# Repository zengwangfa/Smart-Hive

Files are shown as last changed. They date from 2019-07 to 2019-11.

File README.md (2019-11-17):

# 智能蜂箱系统

## 一、项目概述

| 硬件 | 主控制器(STM32) | 网关(MT7688) | 
| :--: | :--: | :--: |
|芯片型号| STM32F405RGT6 | MT7688AN |
|CPU| 32位 Cortex-M4(ARMv7) | MIPS24KEc |
|主频| 168MHz | 580MHz |
|RAM| 192KB | 256MB |
|外存| 1MB(FLASH) | 32MB(FLASH) |
|单元| FPU、DSP | Ethernet、WiFi |

> 针对户外大范围、大批量的蜂箱养殖，以及目前人工养蜂的人力成本过高等诸多问题，本设计提出了一套智能蜂箱终端控制方案，实现的内容为：用户可通过web端远程实时监控蜂箱状态（例如实时了解各个蜂箱的编号、重量、温度等）以及蜂箱防盗并且可以发送一系列指令进行远程操控（例如清洗蜂箱、喂食或气温下降给蜂箱加热、），极大便利了蜜蜂的养殖过程，降低了养蜂的人工成本。

## 二、通讯示意结构

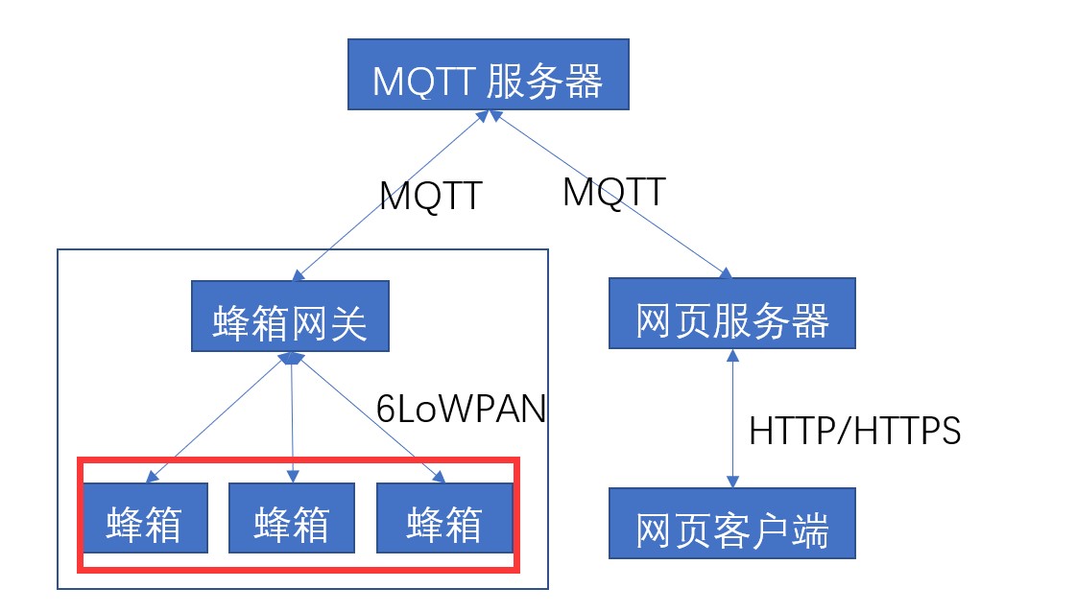
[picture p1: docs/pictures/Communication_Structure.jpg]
Communicatiom Structure


## 三、软件设计说明

- 编译环境：IAR 8.30
- 运行平台：STM32F405RGT6
- 所使用的的操作系统：RT-Thread

- 该软件使用的平台为RT-Thread 3.0物联网操作系统，采用6LoWPAN物联网协议**6LoWPAN** (IPv6 over Low-Power Wireless Personal Area Networks) 作为物联网的一种协议方式。使用这项技术，所有节在点网络层通过 **IPv6**联系起来。

### 3.1 整体结构图

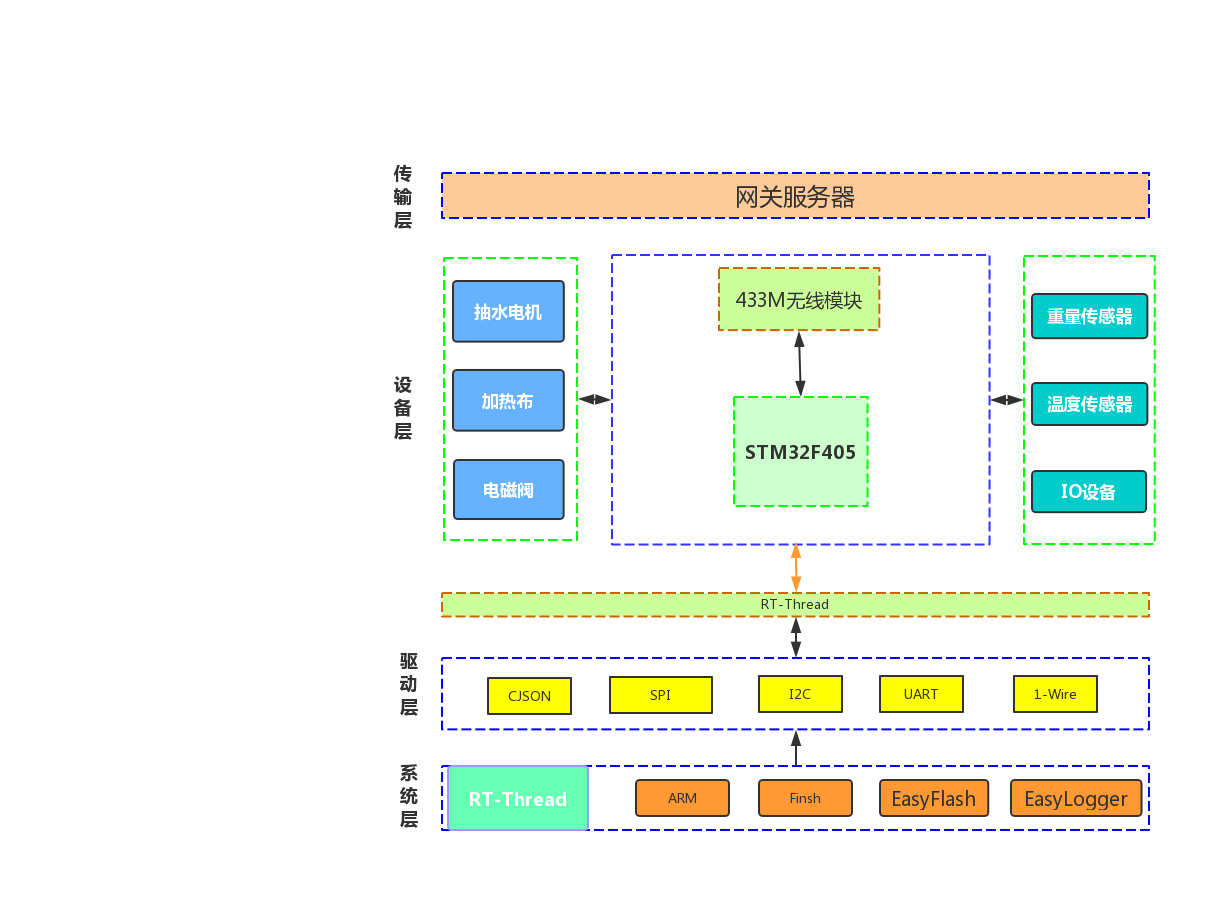
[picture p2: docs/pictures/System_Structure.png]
System Structure


- 主要功能为：采集外围设备数据（温度、重量、编号），将数据按照规定协议打包成**CJSO**数据格式，通过**433M**无线模块向**网关**上传数据，接收来自433M无线模块的控制数据包，进行外设的控制（加热控制、喂食控制、清洗控制）。
---
### 3.2 程序简易流程图
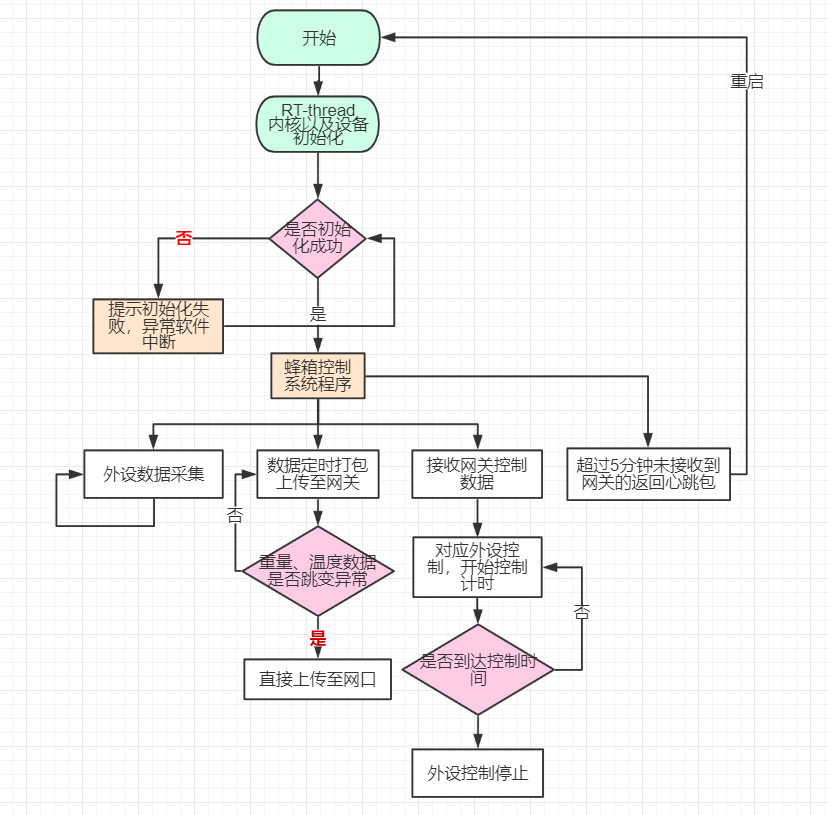
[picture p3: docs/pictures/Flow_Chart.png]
Flow Chart

---
### 3.3 实物样机测试
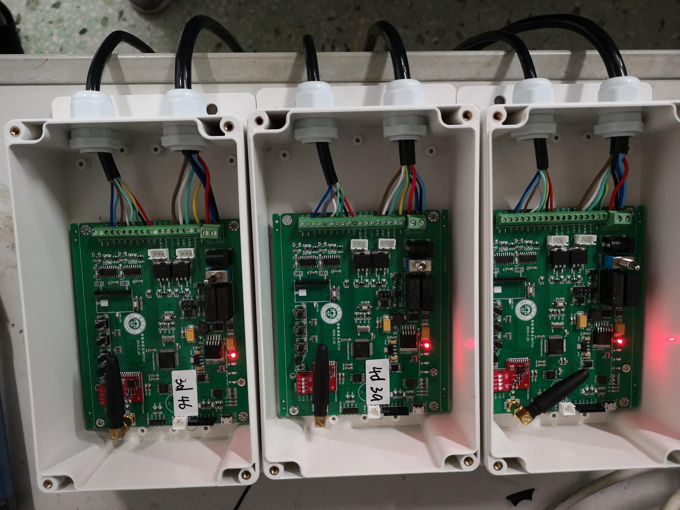
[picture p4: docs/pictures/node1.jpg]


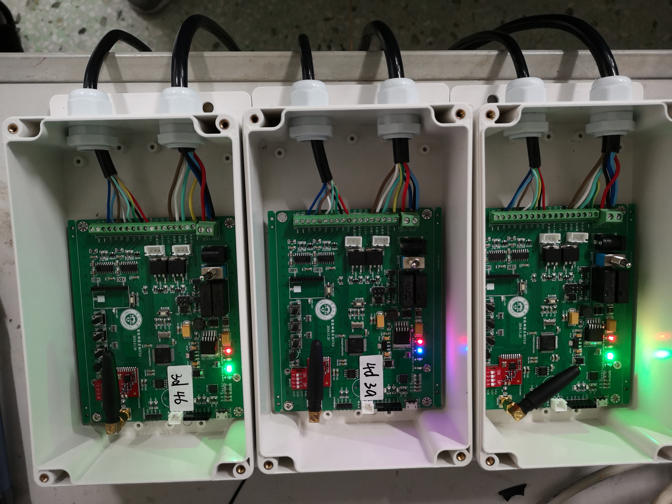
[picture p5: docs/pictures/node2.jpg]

---
### 3.4 Web端显示
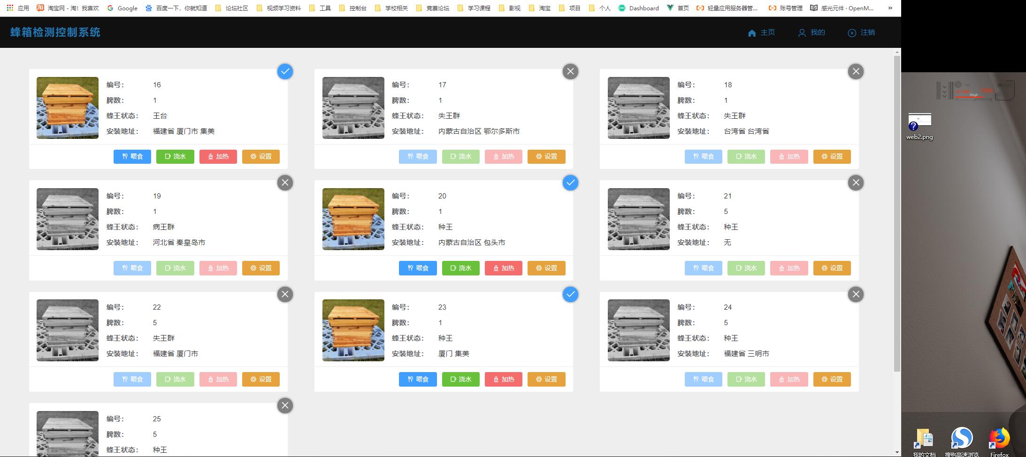
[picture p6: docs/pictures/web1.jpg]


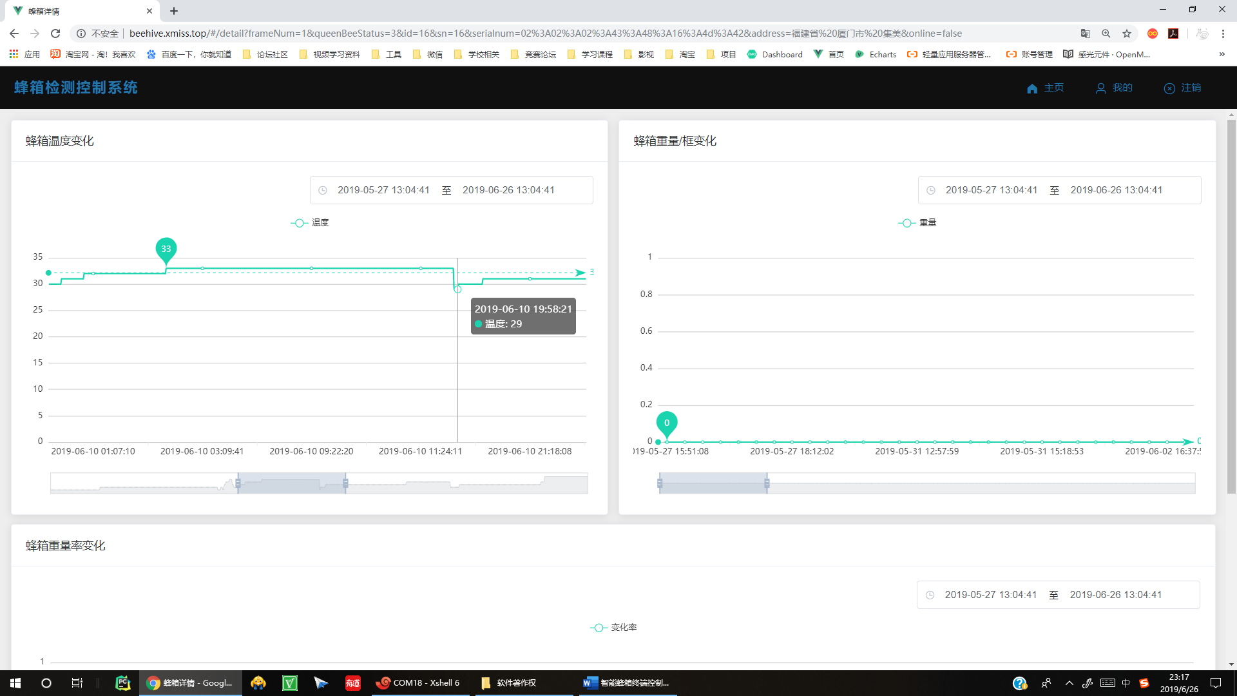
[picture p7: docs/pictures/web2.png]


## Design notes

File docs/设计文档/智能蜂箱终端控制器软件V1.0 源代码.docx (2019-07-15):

#define LOG_TAG "app_task"

#include "app_task.h"

#include <stdlib.h>

#include <stdio.h>

#include <board.h>

#include <elog.h>

#include <elog_flash.h>

#include <easyflash.h>

#include <delay_conf.h>

#include <cpuusage.h>

#include <utils.h>

#include <shell.h>

#include <finsh.h>

#include <cm_backtrace.h>

#include <dfs_elm.h>

#include <dfs_fs.h>

#include <spi_flash.h>

#include <spi_flash_sfud.h>

#include <partition.h>

#define SOFTWARE_VERSION "1.07.15"

static uint8_t cpu_usage_major, cpu_usage_minor;

static rt_uint32_t total_mem, used_mem, max_used_mem;

#define thread_sys_monitor_prio 30

ALIGN(RT_ALIGN_SIZE)

static rt_uint8_t thread_sys_monitor_stack[512];

struct rt_thread thread_sys_monitor;

rt_spi_flash_device_t nor_flash;

static void rtt_user_assert_hook(const char* ex, const char* func, rt_size_t line);

static void elog_user_assert_hook(const char* ex, const char* func, size_t line);

static rt_err_t exception_hook(void *context);

/**

* @param parameter parameter

*/

void thread_entry_sys_monitor(void* parameter)

{

while (1)

{

rt_memory_info(&total_mem, &used_mem, &max_used_mem);

// rt_kprintf("Total_Mem:%ld Used_Mem:%ld Max_Used_Mem:%ld\n",total_mem,used_mem,max_used_mem);

IWDG_Feed(); //

}

}

/**

* @param parameter parameter

*/

void sys_init_thread(void* parameter){

set_system_status(SYSTEM_STATUS_INIT);

#ifdef RT_USING_COMPONENTS_INIT

rt_components_init();

#endif

#if defined(RT_USING_FINSH) && !defined(RT_USING_POSIX)

finsh_set_device(RT_CONSOLE_DEVICE_NAME);

#endif

if ((nor_flash = rt_sfud_flash_probe("nor_flash", "spi20")) == NULL) {

set_system_status(SYSTEM_STATUS_FAULT);

return;

}

extern int rt_partition_init(const char* flash_device, const struct rt_partition* parts, rt_size_t num);

static const struct rt_partition partition[] = RT_PARTITION_DEFAULT_TABLE;

rt_partition_init("nor_flash", partition, sizeof(partition) / sizeof(struct rt_partition));

easyflash_init();

elog_init();

elog_set_fmt(ELOG_LVL_ASSERT, ELOG_FMT_ALL & ~ELOG_FMT_P_INFO);

elog_set_fmt(ELOG_LVL_ERROR, ELOG_FMT_ALL & ~ELOG_FMT_P_INFO);

elog_set_fmt(ELOG_LVL_WARN, ELOG_FMT_ALL & ~ELOG_FMT_P_INFO);

elog_set_fmt(ELOG_LVL_INFO, ELOG_FMT_LVL | ELOG_FMT_TAG | ELOG_FMT_TIME);

elog_set_fmt(ELOG_LVL_DEBUG, ELOG_FMT_ALL & ~(ELOG_FMT_FUNC | ELOG_FMT_P_INFO));

elog_set_fmt(ELOG_LVL_VERBOSE, ELOG_FMT_ALL & ~(ELOG_FMT_FUNC | ELOG_FMT_P_INFO));

#ifdef DEBUG

elog_set_filter_lvl(ELOG_LVL_VERBOSE);

#elif RELEASE

elog_set_filter_lvl(ELOG_LVL_INFO);

#endif

#ifdef ELOG_COLOR_ENABLE

elog_set_text_color_enabled(true);

#endif

elog_flash_init();

elog_start();

extern void flash_read_normalized(void);

flash_read_normalized();

elog_assert_set_hook(elog_user_assert_hook);

rt_hw_exception_install(exception_hook);

rt_assert_set_hook(rtt_user_assert_hook);

cm_backtrace_init("ART-6LoWPAN", HARDWARE_VERSION, SOFTWARE_VERSION);

if (dfs_mount("fatfs", "/", "elm", 0, 0) == 0) {

log_i("File System initialized!");

} else {

log_e("File System initialization failed!");

}

extern void contiki_init(void);

contiki_init();

set_system_status(SYSTEM_STATUS_RUN);

log_i("ART-6LoWPAN initialize success. Firmware version is %s", SOFTWARE_VERSION);

}

static void rtt_user_assert_hook(const char* ex, const char* func, rt_size_t line) {

rt_enter_critical();

#ifdef ELOG_ASYNC_OUTPUT_ENABLE

elog_async_enabled(false);

#endif

elog_output_lock_enabled(false);

elog_flash_lock_enabled(false);

elog_a("rtt", "(%s) has assert failed at %s:%ld.", ex, func, line);

cm_backtrace_assert(cmb_get_sp());

elog_flash_flush();

while(1);

}

static void elog_user_assert_hook(const char* ex, const char* func, size_t line) {

rt_enter_critical();

#ifdef ELOG_ASYNC_OUTPUT_ENABLE

elog_async_enabled(false);

#endif

elog_output_lock_enabled(false);

elog_flash_lock_enabled(false);

elog_a("elog", "(%s) has assert failed at %s:%ld.\n", ex, func, line);

cm_backtrace_assert(cmb_get_sp());

elog_flash_flush();

while(1);

}

static rt_err_t exception_hook(void *context) {

extern long list_thread(void);

uint8_t _continue = 1;

rt_enter_critical();

#ifdef ELOG_ASYNC_OUTPUT_ENABLE

elog_async_enabled(false);

#endif

elog_output_lock_enabled(false);

elog_flash_lock_enabled(false);

#ifdef RT_USING_FINSH

list_thread();

#endif

cm_backtrace_fault(*((uint32_t *)(cmb_get_sp() + sizeof(uint32_t) * 8)), cmb_get_sp() + sizeof(uint32_t) * 9);

elog_flash_flush();

while (_continue == 1);

return RT_EOK;

}

*/

void rt_hw_console_output(const char *str) {

extern void output_log_to_console_or_flash(bool console, bool flash, const char *log, size_t size);

output_log_to_console_or_flash(true, true, str, rt_strlen(str));

}

int rt_application_init(void)

{

rt_thread_t thread = NULL;

rt_thread_init(&thread_sys_monitor,

"sys_monitor",

thread_entry_sys_monitor,

RT_NULL,

thread_sys_monitor_stack,

sizeof(thread_sys_monitor_stack),

thread_sys_monitor_prio, 5);

rt_thread_startup(&thread_sys_monitor);

thread = rt_thread_create("sys init", sys_init_thread, NULL, 2048, 10, 10);

if (thread != NULL) {

rt_thread_startup(thread);

}

return 0;

}

/**

* This function will startup RT-Thread RTOS.

*/

void rtthread_startup(void)

{

/* init board */

rt_hw_board_init();

/* show version */

rt_show_version();

/* init tick */

rt_system_tick_init();

/* init kernel object */

rt_system_object_init();

/* init timer system */

rt_system_timer_init();

#ifdef RT_USING_HEAP

/* init memory system */

rt_system_heap_init((void*)STM32_SRAM_BEGIN, (void*)STM32_SRAM_END);

#endif

/* init scheduler system */

rt_system_scheduler_init();

/* initialize timer */

rt_system_timer_init();

/* init timer thread */

rt_system_timer_thread_init();

/* Add CPU usage to system */

cpu_usage_init();

/* init application */

rt_application_init();

/* init idle thread */

rt_thread_idle_init();

/* start scheduler */

rt_system_scheduler_start();

/* never reach here */

return;

}

void sys_reboot_entry(void* parameter)

{

static rt_uint32_t sys_cnt = 0;

while(1)

{

rt_thread_delay(RT_TICK_PER_SECOND); //1s

sys_cnt++;

if(sys_cnt >= 60*60*4) //6 1-5 2-10 3-20 4-30 5-1h

{

sys_cnt = 0;

NVIC_SystemReset();

}

}

}

int sys_reboot_thread_init(void)

{

rt_thread_t reboot_tid;

/* */

reboot_tid = rt_thread_create("reboot"

sys_reboot_entry,

RT_NULL,

1024,

30,

10);

if (reboot_tid != RT_NULL){

rt_thread_startup(reboot_tid);

}

return 0;

}

INIT_APP_EXPORT(sys_reboot_thread_init);

int main(void) {

/* disable interrupt first */

rt_hw_interrupt_disable();

/* startup RT-Thread RTOS */

rtthread_startup();

return 0;

}/*

* File : board.h

* This file is part of RT-Thread RTOS

* COPYRIGHT (C) 2017, RT-Thread Development Team

*

* The license and distribution terms for this file may be

* found in the file LICENSE in this distribution or at

* http://www.rt-thread.org/license/LICENSE

*

* Change Logs:

* Date Author Notes

* 2017-12-19 xidongxu first version

*/

#include "board.h"

#include <rtthread.h>

*/

static uint16_t get_adc(u8 ch) {

ADC_RegularChannelConfig(ADC1, ch, 1, ADC_SampleTime_112Cycles );

ADC_SoftwareStartConv(ADC1);

while(!ADC_GetFlagStatus(ADC1, ADC_FLAG_EOC ));

return ADC_GetConversionValue(ADC1);

}

/**

*

*/

uint32_t cpu_temp_get(void) {

uint32_t adc[10] = { 0 }, adc_max = 0, adc_min = 0;

uint32_t adc_value = 0, adc_sum = 0;

double temperature = 0.0;

for (uint8_t t = 0; t < 10; t++) {

adc[t] = get_adc(ADC_Channel_16);

adc_sum = adc_sum + adc[t];

rt_thread_delay(rt_tick_from_millisecond(5));

}

adc_max = adc[0];

adc_min = adc[0];

for (uint8_t t = 1; t < 10; t++) {

if (adc_max < adc[t]) {

adc_max = adc[t];

}

if (adc_min > adc[t]) {

adc_min = adc[t];

}

}

adc_value = ((adc_sum - adc_max - adc_min) / 8);

temperature = (float) adc_value * (3.3 / 4096);

temperature = (temperature - 0.76) / 0.0025 + 25;

return (uint32_t)(temperature);

}

*/

int stm32_cpu_temperature_init(void) {

ADC_CommonInitTypeDef ADC_CommonInitStructure;

ADC_InitTypeDef ADC_InitStructure;

RCC_APB2PeriphClockCmd(RCC_APB2Periph_ADC1, ENABLE);

RCC_APB2PeriphResetCmd(RCC_APB2Periph_ADC1, ENABLE);

RCC_APB2PeriphResetCmd(RCC_APB2Periph_ADC1, DISABLE);

ADC_TempSensorVrefintCmd(ENABLE);

ADC_CommonInitStructure.ADC_Mode = ADC_Mode_Independent;

ADC_CommonInitStructure.ADC_TwoSamplingDelay = ADC_TwoSamplingDelay_20Cycles;

ADC_CommonInitStructure.ADC_DMAAccessMode = ADC_DMAAccessMode_Disabled;

ADC_CommonInitStructure.ADC_Prescaler = ADC_Prescaler_Div4;

ADC_CommonInit(&ADC_CommonInitStructure);

ADC_InitStructure.ADC_Resolution = ADC_Resolution_12b;

ADC_InitStructure.ADC_ScanConvMode = DISABLE;

ADC_InitStructure.ADC_ContinuousConvMode = DISABLE;

ADC_InitStructure.ADC_ExternalTrigConvEdge = ADC_ExternalTrigConvEdge_None;

ADC_InitStructure.ADC_ExternalTrigConv = ADC_ExternalTrigConv_T1_CC1;

ADC_InitStructure.ADC_DataAlign = ADC_DataAlign_Right;

ADC_InitStructure.ADC_NbrOfConversion = 1;

ADC_Init(ADC1, &ADC_InitStructure);

ADC_RegularChannelConfig(ADC1, ADC_Channel_16, 1, ADC_SampleTime_112Cycles);

ADC_Cmd(ADC1, ENABLE);

return 0;

}

INIT_BOARD_EXPORT(stm32_cpu_temperature_init);

/******************************************************************************

* Copyright 2018-2023 zhuangwei@nblink-tech.com

* FileName: drv_ds18b20.c

* Desc:

*

*

* Author: zhuangwei

* Date: 2018-12-15

* Notes:

*

* -----------------------------------------------------------------

* Histroy: v1.0 2018-12-15, zhuangwei create this file

*

******************************************************************************/

/*------------------------------- Includes ----------------------------------*/

#include <rtdevice.h>

#include "utils.h"

#include "drv_ds18b20.h"

/*------------------- Global Definitions and Declarations -------------------*/

/*---------------------- Constant / Macro Definitions -----------------------*/

#define DS18B20_PIN 54

/*----------------------- Type Declarations ---------------------------------*/

/*----------------------- Variable Declarations -----------------------------*/

static int temp_value = 0;

/*----------------------- Function Prototype --------------------------------*/

/*----------------------- Function Implement --------------------------------*/

/******************************************************************************

* Name: ds18b20_rst

*

* Desc: DS18B20

* Param:

* Return:

* Global:

* Note:

* Author: zhuangwei

* -------------------------------------

* Log: 2018/12/15, Create this function by zhuangwei

******************************************************************************/

static rt_uint8_t ds18b20_rst(void)

{

rt_pin_mode(DS18B20_PIN, PIN_MODE_OUTPUT);

rt_pin_write(DS18B20_PIN, PIN_LOW);

delay_us(750);

rt_pin_write(DS18B20_PIN, PIN_HIGH);

delay_us(20);

rt_pin_mode(DS18B20_PIN, PIN_MODE_INPUT);

delay_us(100);

return rt_pin_read(DS18B20_PIN);

}

/******************************************************************************

* Name: ds18b20_read_byte

*

* Desc:

* Param:

* Return:

* Global:

* Note:

* Author: zhuangwei

* -------------------------------------

* Log: 2018/12/15, Create this function by zhuangwei

******************************************************************************/

static rt_uint8_t ds18b20_read_byte(void) // read one byte

{

rt_uint8_t i;

rt_uint8_t data = 0;

for (i=0; i<8; i++)

{

rt_pin_mode(DS18B20_PIN, PIN_MODE_OUTPUT);

rt_pin_write(DS18B20_PIN, PIN_LOW);

delay_us(2);

rt_pin_write(DS18B20_PIN, PIN_HIGH);

rt_pin_mode(DS18B20_PIN, PIN_MODE_INPUT);

delay_us(12);

data >>= 1;

if(rt_pin_read(DS18B20_PIN))

{

data |= 0x80;

}

delay_us(50);

rt_pin_mode(DS18B20_PIN, PIN_MODE_OUTPUT);

rt_pin_write(DS18B20_PIN, PIN_HIGH);

}

return data;

}

/******************************************************************************

* Name: ds18b20_write_byte

*

* Desc:

* Param:

* Return:

* Global:

* Note:

* Author: zhuangwei

* -------------------------------------

* Log: 2018/12/15, Create this function by zhuangwei

******************************************************************************/

static void ds18b20_write_byte(rt_uint8_t data)

{

rt_uint8_t i,tmp;

rt_pin_mode(DS18B20_PIN, PIN_MODE_OUTPUT);

for (i=1; i<=8; i++)

{

tmp = data&0x01;

data = data>>1;

if(tmp)

{

rt_pin_write(DS18B20_PIN, PIN_LOW);

delay_us(5);

rt_pin_write(DS18B20_PIN, PIN_HIGH);

delay_us(60);

}

else

{

rt_pin_write(DS18B20_PIN, PIN_LOW);

delay_us(60);

rt_pin_write(DS18B20_PIN, PIN_HIGH);

delay_us(5);

}

}

}

/******************************************************************************

* Name: ds18b20_get_temp

*

* Desc:

* Param:

* Return:

* Global:

* Note:

* Author: zhuangwei

* -------------------------------------

* Log: 2018/12/15, Create this function by zhuangwei

******************************************************************************/

static int ds18b20_get_value(void)

{

rt_uint8_t TL,TH;

rt_uint16_t temp;

float ret;

if(ds18b20_rst()) return 0;

delay_us(100);

ds18b20_write_byte(0xCC);//skip rom

ds18b20_write_byte(0x44);//convert

//rt_thread_delay(1);

if(ds18b20_rst()) return 0;

delay_us(100);

ds18b20_write_byte(0xCC);// skip rom

ds18b20_write_byte(0xBE);

delay_us(10);

TL = ds18b20_read_byte();

TH = ds18b20_read_byte();

temp = (TH<<8)|TL;

if(temp&0xf000)

{

ret = (~temp+1)*0.0625;

}

else

{

ret = temp*0.0625;

}

return (int)ret;

}

int ds18b20_get_temp(void)

{

int ret;

rt_enter_critical();

ret = temp_value;

rt_exit_critical();

return ret;

}

static void ds18b20(void)

{

rt_uint8_t count;

rt_uint16_t temp;

for(count=1; count<=3; count++)

{

temp =ds18b20_get_temp();

rt_kprintf("temperature : %d\r\n", temp);

rt_thread_mdelay(500);

}

}

MSH_CMD_EXPORT(ds18b20, ds18b20 test);

void first_get_temperature(void)

{

char j = 0;

rt_int32_t value[5] = {0};

/* 500ms */

rt_thread_delay(RT_TICK_PER_SECOND/2);

rt_enter_critical();

for(j=0; j<5; j++)

{

rt_thread_delay(10);

value[j] = ds18b20_get_value();

}

temp_value = Bubble(value, 5);

rt_exit_critical();

}

rt_int32_t value[5] = {0};

void ds18b20_thread_entry(void* p)

{

char i = 0;

char ON_OFF = 0; //

rt_int32_t last_temp = 0;

while(1)

{

if(ON_OFF == 0){

first_get_temperature();

ON_OFF = 1;

}

else{

rt_thread_delay(RT_TICK_PER_SECOND/5);// 0.2s 10s

value[i++] = ds18b20_get_value();

if(i >= 5){// 5

temp_value = Bubble(value, 5);

i = 0;

if(temp_value > -10 && temp_value < 55){ //

last_temp = temp_value; //

}

else if(abs(temp_value-last_temp)>5 && last_temp != 0 )// 5 0

{

temp_value = last_temp;//

}

rt_kprintf("temp:$%d\r\n",temp_value);

//rt_kprintf("last_temp:$%d\r\n",last_temp);

}

}

}

}

//void ds18b20_thread_entry(void* p)

//{

// int i = 0;

// int value[5] = {0};

// static rt_int32_t last_temp = 0;

//

// while(1)

// {

// /* 500ms */

// rt_thread_delay(RT_TICK_PER_SECOND/2);

// rt_enter_critical();

// for(i=0; i<5; i++)

// {

// rt_thread_delay(1);

// value[i] = ds18b20_get_value();

// }

//

// temp_value = Bubble((rt_int32_t *)value, 5);

// if(temp_value > -20 && temp_value < 70){ //

// last_temp = temp_value; //

// }

// else {

// temp_value = last_temp;//

// }

// rt_exit_critical();

// }

//}

static int ds18b20_init(void)

{

rt_thread_t thread = RT_NULL;

/* Create background ticks thread */

thread = rt_thread_create("ds18b20", ds18b20_thread_entry, RT_NULL, 1024, 30, 10);

if(thread == RT_NULL)

{

return RT_ERROR;

}

rt_thread_startup(thread);

return 0;

}

INIT_DEVICE_EXPORT(ds18b20_init);

/*---------------------------------------------------------------------------*/

/******************************************************************************

* Copyright 2018-2023 zhuangwei@nblink-tech.com

* FileName: drv_hx711.c

* Desc:

*

*

* Author: zhuangwei

* Date: 2018-12-19

* Notes:

*

* -----------------------------------------------------------------

* Histroy: v1.0 2018-12-19, zhuangwei create this file

*

******************************************************************************/

/*------------------------------- Includes ----------------------------------*/

#define LOG_TAG "drv_hx711"

#include <rtdevice.h>

#include "utils.h"

#include "drv_hx711.h"

#include <elog.h>

#include "multi_button.h"

#include "easyflash.h"

#include <stdio.h>

#include <stdlib.h>

/*------------------- Global Definitions and Declarations -------------------*/

/*---------------------- Constant / Macro Definitions -----------------------*/

#define FLASH_INIT_ADDRESS (4096) //

#define HX711_DT1_PIN 10

#define HX711_SCK1_PIN 11

#define HX711_DT2_PIN 14

#define HX711_SCK2_PIN 15

#define HX711_LED_PIN 55

#define HX711_KEY_PIN 28

#define HX711_DT(pin) rt_pin_read(pin)

#define HX711_SCK_HIGH(pin) rt_pin_write(pin, PIN_HIGH)

#define HX711_SCK_LOW(pin) rt_pin_write(pin, PIN_LOW)

#define HX711_LED_ON rt_pin_write(HX711_LED_PIN, PIN_HIGH)

#define HX711_LED_OFF rt_pin_write(HX711_LED_PIN, PIN_LOW)

/*----------------------- Type Declarations ---------------------------------*/

/*----------------------- Variable Declarations -----------------------------*/

static struct button btn;

uint32_t var_min[2]={999999999,999999999}; // -2147483648 +2141483647

float weight = 0;

float side_weight[2];

double Normalized[2]={0}; // float double

rt_int32_t Reverse_Normalized[2] = {0}; // flash

static int key_status = 0;

/*----------------------- Function Prototype --------------------------------*/

/*----------------------- Function Implement --------------------------------*/

int flash_read_normalized(void)

{

char string[100];

ef_port_read(FLASH_INIT_ADDRESS+0,(rt_int32_t *)&Reverse_Normalized[0],4);

ef_port_read(FLASH_INIT_ADDRESS+4,(rt_int32_t *)&Reverse_Normalized[1],4);

ef_port_read(FLASH_INIT_ADDRESS+8 ,&var_min[0],4);

ef_port_read(FLASH_INIT_ADDRESS+12,&var_min[1],4);

Normalized[0] = (double)1 / Reverse_Normalized[0] ;

Normalized[1] = (double)1 / Reverse_Normalized[1] ;

// string

sprintf(string,"Normalized*100: %f , %f ",Normalized[0]*100,Normalized[1]*100);

log_i(string);

sprintf(string,"var_min:%ld , %ld ",var_min[0],var_min[1]);

log_i(string);

return 0;

}

void flash_writer_normalized(void)

{

ef_port_erase(FLASH_INIT_ADDRESS,4); // 4096 Byte

ef_port_write(FLASH_INIT_ADDRESS+0,(uint32_t *)&Reverse_Normalized[0],4);// FLASH_INIT_ADDRESS+0

ef_port_write(FLASH_INIT_ADDRESS+4,(uint32_t *)&Reverse_Normalized[1],4);

ef_port_write(FLASH_INIT_ADDRESS+8 ,&var_min[0],4);

ef_port_write(FLASH_INIT_ADDRESS+12,&var_min[1],4);

}

rt_uint32_t hx711_read(int pin_dat, int pin_sck)

{

unsigned char i;

unsigned int value;

HX711_SCK_LOW(pin_sck);// AD

value=0;

while(HX711_DT(pin_dat));//AD ,

for(i=0; i<24; i++)

{

HX711_SCK_HIGH(pin_sck);//SCK ( )

value = value<<1;// Count ,

HX711_SCK_LOW(pin_sck);//SCK

if(HX711_DT(pin_dat)) value++;

}

HX711_SCK_HIGH(pin_sck);

value = value^0x800000;// 25 ,

HX711_SCK_LOW(pin_sck);

return value;

}

static void first_hx711_get_ad(rt_int32_t *ad)//

{

rt_int32_t var0[5];

rt_int32_t var1[5];

rt_uint8_t i = 0;

if(!ad) return;

for(i=0; i<5; i++)

{

rt_thread_delay(RT_TICK_PER_SECOND/10);// 100ms

var0[i] = hx711_read(HX711_DT1_PIN, HX711_SCK1_PIN);

var1[i] = hx711_read(HX711_DT2_PIN, HX711_SCK2_PIN);

}

ad[0] = Bubble(var0, 5);

ad[1] = Bubble(var1, 5);

}

static void hx711_get_ad(rt_int32_t *ad)

{

rt_int32_t var0[5];

rt_int32_t var1[5];

uint8_t i = 0;

if(!ad) return;

for(i=0; i<5; i++)

{

var0[i] = hx711_read(HX711_DT1_PIN, HX711_SCK1_PIN);

var1[i] = hx711_read(HX711_DT2_PIN, HX711_SCK2_PIN);

//rt_kprintf("var: %d , %d\n",var0[i],var1[i]);

}

ad[0] = Bubble(var0, 5);

ad[1] = Bubble(var1, 5);

//rt_kprintf("ad: %d , %d\n",ad[0],ad[1]);

}

void hx711_get_min(void)

{

rt_int32_t temp_res[2]={0};

uint8_t j = 5;

while(j--)

{

hx711_get_ad(temp_res);

rt_kprintf("temp_res: %ld , %ld \n",temp_res[0],temp_res[1]);

if(var_min[0] >= temp_res[0] || var_min[0] < 800000 ) {// var_min 800000 ,var_min

var_min[0] = temp_res[0];

}

if(var_min[1] >= temp_res[1] || var_min[1] < 800000 ) {

var_min[1] = temp_res[1];

}

rt_kprintf("var_min: %ld , %ld\n",var_min[0],var_min[1]);

}

log_i("var_min: %ld, %ld ",var_min[0],var_min[1]);

}

void hx711_normalized(void)

{

rt_int32_t temp[2]={0};

hx711_get_ad(temp);

Reverse_Normalized[0]= abs(temp[0]-var_min[0]);

Reverse_Normalized[1] = abs(temp[1]-var_min[1]);

Normalized[0] =(double) 1/(temp[0]-var_min[0]);

Normalized[1] =(double) 1/(temp[1]-var_min[1]);

flash_writer_normalized();//

log_i("FLASH Write Reverse_Normalized: %d, %d ",Reverse_Normalized[0],Reverse_Normalized[1]);

}

float hx711_weight_get(void)

{

float ret;

rt_enter_critical();

ret = weight;

rt_exit_critical();

return ret;

}

float hx711_weight_update(void)

{

rt_int32_t AD_Value[2] = {0};

static uint8_t count = 0;

static float last_weight = 0;

static char ON_OFF = 0;

while(1)

{

if(0 == ON_OFF){

first_hx711_get_ad(AD_Value);

ON_OFF = 1;

}

else{

hx711_get_ad(AD_Value);

}

side_weight[0] = (float)abs(AD_Value[0]-var_min[0])/abs(Reverse_Normalized[0]);

side_weight[1] = (float)abs(AD_Value[1]-var_min[1])/abs(Reverse_Normalized[1]);

//rt_kprintf("--- %ld --- %ld ---\n",abs(AD_Value[0]-var_min[0]),abs(AD_Value[1]-var_min[1]));

if ( ((side_weight[0] > 50 || side_weight[1] > 50) || (side_weight[0] < 0 || side_weight[1] < 0)) && count <= 5) // 50kg

{

count ++;

//rt_kprintf("count = %d \n",count);

continue;// 6

}

else if(count > 5){ //

count = 0;

rt_kprintf("last_weight = %d \n",last_weight);

return last_weight;//

}

last_weight = (side_weight[0]+side_weight[1])/2;

return (side_weight[0]+side_weight[1])/2; //

}

}

void hx711_key_callback(void *btn)

{

uint32_t btn_event_val;

btn_event_val = get_button_event((struct button *)btn);

if(btn_event_val == SINGLE_CLICK)

{

switch(key_status)

{

case 0://

hx711_get_min();

HX711_LED_ON;

key_status = 1;

log_i("please put 1KG");

break;

case 1://

hx711_normalized();//

HX711_LED_OFF;

key_status = 0;

log_i("hx711 normalized");

break;

default:

break;

}

}

}

static uint8_t hx711_key_read(void)

{

return rt_pin_read(HX711_KEY_PIN);

}

void hx711_key_thread_entry(void* p)

{

int cnt = 200*55;

while(1)

{

/* 5ms */

rt_thread_delay(RT_TICK_PER_SECOND/200);

button_ticks();

cnt++;

if(cnt == 200*60)//60s

{

rt_enter_critical();

weight = hx711_weight_update();

rt_exit_critical();

cnt = 0;

}

}

}

static int hx711_init(void)

{

rt_pin_mode(HX711_DT1_PIN, PIN_MODE_INPUT_PULLUP);

rt_pin_mode(HX711_SCK1_PIN, PIN_MODE_OUTPUT);

rt_pin_write(HX711_SCK1_PIN, PIN_HIGH);

rt_pin_mode(HX711_DT2_PIN, PIN_MODE_INPUT_PULLUP);

rt_pin_mode(HX711_SCK2_PIN, PIN_MODE_OUTPUT);

rt_pin_write(HX711_SCK2_PIN, PIN_HIGH);

rt_pin_mode(HX711_LED_PIN, PIN_MODE_OUTPUT);

HX711_LED_OFF;

rt_pin_mode(HX711_KEY_PIN, PIN_MODE_INPUT);

button_init(&btn, hx711_key_read, PIN_LOW);

button_attach(&btn, SINGLE_CLICK, hx711_key_callback);

button_start (&btn);

rt_thread_t thread = RT_NULL;

/* Create background ticks thread */

thread = rt_thread_create("hx711", hx711_key_thread_entry, RT_NULL, 1024, 30, 10);

if(thread == RT_NULL)

{

return RT_ERROR;

}

rt_thread_startup(thread);

return 0;

}

INIT_DEVICE_EXPORT(hx711_init);

/*---------------------------------------------------------------------------*/

/* Get weight */

void get_weight_hx711(void)

{

// string

char str[100];

float temp_weight = 0;

temp_weight = hx711_weight_update();

sprintf(str,"Weight:%f \n",temp_weight);

rt_kprintf(str);

sprintf(str,"weight1:%f weight2:%f\n",side_weight[0],side_weight[1]);

rt_kprintf(str);

}

MSH_CMD_EXPORT(get_weight_hx711,get_weight_hx711[a]);

/******************************************************************************

* Copyright 2018-2023 zhuangwei@nblink-tech.com

* FileName: drv_relay.c

* Desc:

*

*

* Author: zhuangwei

* Date: 2018-12-15

* Notes:

*

* -----------------------------------------------------------------

* Histroy: v1.0 2018-12-15, zhuangwei create this file

*

******************************************************************************/

/*------------------------------- Includes ----------------------------------*/

#define LOG_TAG "drv_relay"

#include <rtdevice.h>

#include "drv_relay.h"

#include <elog.h>

/*------------------- Global Definitions and Declarations -------------------*/

typedef struct

{

char *name;

rt_base_t pin;

rt_timer_t timer;

int status;

}relay_t;

/*---------------------- Constant / Macro Definitions -----------------------*/

static relay_t relay_table[] = {

{"water", 62, RT_NULL, 0},

{"feed", 61, RT_NULL, 0},

{"heat1", 4, RT_NULL, 0},

{"heat2", 9, RT_NULL, 0}

};

/*----------------------- Type Declarations ---------------------------------*/

/*----------------------- Variable Declarations -----------------------------*/

/*----------------------- Function Prototype --------------------------------*/

/*----------------------- Function Implement --------------------------------*/

static void timeout_handler(void* parameter)

{

relay_t *relay_ptr = (relay_t*)parameter;

relay_ptr->status = relay_ptr->status?0:1;

rt_pin_write(relay_ptr->pin, relay_ptr->status);

relay_ptr->timer = RT_NULL;

}

int relay_control(relay_dev_t dev, int expect_status, int hold_s)

{

if(dev >= RELAY_MAX) return -1;

if(relay_table[dev].status == expect_status) return 0;

if(relay_table[dev].timer)

{

if(relay_table[dev].status == expect_status)

return 0;

else

return -1;

}

else

{

rt_pin_write(relay_table[dev].pin, expect_status);

relay_table[dev].status = expect_status;

if(hold_s > 0)

{

relay_table[dev].timer = rt_timer_create(relay_table[dev].name, \

timeout_handler, &relay_table[dev], rt_tick_from_millisecond(hold_s*1000), \

RT_TIMER_FLAG_ONE_SHOT);

if (relay_table[dev].timer != RT_NULL) rt_timer_start(relay_table[dev].timer);

}

}

return 0;

}

static int relay_init(void)

{

int i;

for(i=0; i<RELAY_MAX; i++)

{

rt_pin_mode(relay_table[i].pin, PIN_MODE_OUTPUT);

rt_pin_write(relay_table[i].pin, relay_table[i].status);

}

return 0;

}

INIT_DEVICE_EXPORT(relay_init);

/*---------------------------------------------------------------------------*/

/*

* Copyright (c) 2013, Institute for Pervasive Computing, ETH Zurich

* All rights reserved.

*

* Redistribution and use in source and binary forms, with or without

* modification, are permitted provided that the following conditions

* are met:

* 1. Redistributions of source code must retain the above copyright

* notice, this list of conditions and the following disclaimer.

* 2. Redistributions in binary form must reproduce the above copyright

* notice, this list of conditions and the following disclaimer in the

* documentation and/or other materials provided with the distribution.

* 3. Neither the name of the Institute nor the names of its contributors

* may be used to endorse or promote products derived from this software

* without specific prior written permission.

*

* THIS SOFTWARE IS PROVIDED BY THE INSTITUTE AND CONTRIBUTORS ``AS IS'' AND

* ANY EXPRESS OR IMPLIED WARRANTIES, INCLUDING, BUT NOT LIMITED TO, THE

* IMPLIED WARRANTIES OF MERCHANTABILITY AND FITNESS FOR A PARTICULAR PURPOSE

* ARE DISCLAIMED. IN NO EVENT SHALL THE INSTITUTE OR CONTRIBUTORS BE LIABLE

* FOR ANY DIRECT, INDIRECT, INCIDENTAL, SPECIAL, EXEMPLARY, OR CONSEQUENTIAL

* DAMAGES (INCLUDING, BUT NOT LIMITED TO, PROCUREMENT OF SUBSTITUTE GOODS

* OR SERVICES; LOSS OF USE, DATA, OR PROFITS; OR BUSINESS INTERRUPTION)

* HOWEVER CAUSED AND ON ANY THEORY OF LIABILITY, WHETHER IN CONTRACT, STRICT

* LIABILITY, OR TORT (INCLUDING NEGLIGENCE OR OTHERWISE) ARISING IN ANY WAY

* OUT OF THE USE OF THIS SOFTWARE, EVEN IF ADVISED OF THE POSSIBILITY OF

* SUCH DAMAGE.

*

* This file is part of the Contiki operating system.

*/

/**

* \file

* Erbium (Er) CoAP client example.

* \author

* Matthias Kovatsch <kovatsch@inf.ethz.ch>

*/

#define LOG_TAG "coap_client"

#include <elog.h>

#include "rtthread.h"

#include <stdio.h>

#include <stdlib.h>

#include <string.h>

#include "contiki.h"

#include "contiki-net.h"

#include "er-coap-engine.h"

#include "net/rpl/rpl.h"

#include "net/ip/uip.h"

#include "string.h"

#define DEBUG 0

#if DEBUG

#include <stdio.h>

#define PRINTF(...) log_i(__VA_ARGS__)

#define PRINT6ADDR(addr) PRINTF("[%02x%02x:%02x%02x:%02x%02x:%02x%02x:%02x%02x:%02x%02x:%02x%02x:%02x%02x]", ((uint8_t *)addr)[0], ((uint8_t *)addr)[1], ((uint8_t *)addr)[2], ((uint8_t *)addr)[3], ((uint8_t *)addr)[4], ((uint8_t *)addr)[5], ((uint8_t *)addr)[6], ((uint8_t *)addr)[7], ((uint8_t *)addr)[8], ((uint8_t *)addr)[9], ((uint8_t *)addr)[10], ((uint8_t *)addr)[11], ((uint8_t *)addr)[12], ((uint8_t *)addr)[13], ((uint8_t *)addr)[14], ((uint8_t *)addr)[15])

#define PRINTLLADDR(lladdr) PRINTF("[%02x:%02x:%02x:%02x:%02x:%02x]", (lladdr)->addr[0], (lladdr)->addr[1], (lladdr)->addr[2], (lladdr)->addr[3], (lladdr)->addr[4], (lladdr)->addr[5])

#else

#define PRINTF(...)

#define PRINT6ADDR(addr)

#define PRINTLLADDR(addr)

#endif

/* FIXME: This server address is hard-coded for Cooja and link-local for unconnected border router. */

//#define SERVER_NODE(ipaddr) uip_ip6addr(ipaddr, 0xbbbb, 0, 0, 0, 0, 0, 0, 0x100) /* cooja2 */

//#define SERVER_NODE(ipaddr) uip_ip6addr(ipaddr, 0xbbbb, 0, 0, 0, 0xe581, 0xc232, 0x64b3, 0x6d5c)

#define SERVER_NODE(ipaddr) uip_ip6addr(ipaddr, 0xbbbb, 0, 0, 0, 0x42d6, 0x3cff, 0xfe02, 0x2082)

#define LOCAL_PORT UIP_HTONS(COAP_DEFAULT_PORT + 1)

#define REMOTE_PORT UIP_HTONS(COAP_DEFAULT_PORT)

#define TOGGLE_INTERVAL 10

PROCESS(er_example_client, "Erbium Example Client");

//AUTOSTART_PROCESSES(&er_example_client);

uip_ipaddr_t server_ipaddr;

static struct etimer et;

/* Example URIs that can be queried. */

#define NUMBER_OF_URLS 4

/* leading and ending slashes only for demo purposes, get cropped automatically when setting the Uri-Path */

char *service_urls[NUMBER_OF_URLS] =

{ ".well-known/core", "online", "battery/", "error/in//path" };

/* This function is will be passed to COAP_BLOCKING_REQUEST() to handle responses. */

void client_chunk_handler(void *response) {

const uint8_t *chunk;

int len = coap_get_payload(response, &chunk);

}

PROCESS_THREAD(er_example_client, ev, data) {

PROCESS_BEGIN();

static char msg[24];

static coap_packet_t request[1]; /* This way the packet can be treated as pointer as usual. */

#ifdef auto_find_server

/* */

static uip_ip6addr_t *globaladdr = NULL;

static rpl_dag_t *dag;

uip_ds6_addr_t *addr_desc = uip_ds6_get_global(ADDR_PREFERRED);

if(addr_desc != NULL) {

globaladdr = &addr_desc->ipaddr;

dag = rpl_get_any_dag();

if(dag) {

uip_ipaddr_copy(&server_ipaddr, globaladdr);

memcpy(&server_ipaddr.u8[8], &dag->dag_id.u8[8], sizeof(uip_ipaddr_t) / 2);

} else {

SERVER_NODE(&server_ipaddr);

}

}

#else

SERVER_NODE(&server_ipaddr);

#endif

sprintf(msg, "%02x:%02x:%02x:%02x:%02x:%02x:%02x:%02x", linkaddr_node_addr.u8[0], linkaddr_node_addr.u8[1],

linkaddr_node_addr.u8[2], linkaddr_node_addr.u8[3], linkaddr_node_addr.u8[4],

linkaddr_node_addr.u8[5], linkaddr_node_addr.u8[6], linkaddr_node_addr.u8[7]);

/* receives all CoAP messages */

coap_init_engine();

etimer_set(&et, TOGGLE_INTERVAL * CLOCK_SECOND);

while (1) {

PROCESS_YIELD();

if (etimer_expired(&et)) {

PRINTF("--Toggle timer--");

/* prepare request, TID is set by COAP_BLOCKING_REQUEST() */

coap_init_message(request, COAP_TYPE_CON, COAP_POST, 0);

coap_set_header_uri_path(request, service_urls[1]);

coap_set_payload(request, (uint8_t *) msg, sizeof(msg) - 1);

PRINT6ADDR(&server_ipaddr);

PRINTF(" : %u", UIP_HTONS(REMOTE_PORT));

COAP_BLOCKING_REQUEST(&server_ipaddr, REMOTE_PORT, request, client_chunk_handler);

PRINTF("--Done--");

etimer_reset(&et);

}

}

PROCESS_END();

}

/*

* Copyright (c) 2013, Institute for Pervasive Computing, ETH Zurich

* All rights reserved.

*

* Redistribution and use in source and binary forms, with or without

* modification, are permitted provided that the following conditions

* are met:

* 1. Redistributions of source code must retain the above copyright

* notice, this list of conditions and the following disclaimer.

* 2. Redistributions in binary form must reproduce the above copyright

* notice, this list of conditions and the following disclaimer in the

* documentation and/or other materials provided with the distribution.

* 3. Neither the name of the Institute nor the names of its contributors

* may be used to endorse or promote products derived from this software

* without specific prior written permission.

*

* THIS SOFTWARE IS PROVIDED BY THE INSTITUTE AND CONTRIBUTORS ``AS IS'' AND

* ANY EXPRESS OR IMPLIED WARRANTIES, INCLUDING, BUT NOT LIMITED TO, THE

* IMPLIED WARRANTIES OF MERCHANTABILITY AND FITNESS FOR A PARTICULAR PURPOSE

* ARE DISCLAIMED. IN NO EVENT SHALL THE INSTITUTE OR CONTRIBUTORS BE LIABLE

* FOR ANY DIRECT, INDIRECT, INCIDENTAL, SPECIAL, EXEMPLARY, OR CONSEQUENTIAL

* DAMAGES (INCLUDING, BUT NOT LIMITED TO, PROCUREMENT OF SUBSTITUTE GOODS

* OR SERVICES; LOSS OF USE, DATA, OR PROFITS; OR BUSINESS INTERRUPTION)

* HOWEVER CAUSED AND ON ANY THEORY OF LIABILITY, WHETHER IN CONTRACT, STRICT

* LIABILITY, OR TORT (INCLUDING NEGLIGENCE OR OTHERWISE) ARISING IN ANY WAY

* OUT OF THE USE OF THIS SOFTWARE, EVEN IF ADVISED OF THE POSSIBILITY OF

* SUCH DAMAGE.

*

* This file is part of the Contiki operating system.

*/

/**

* \file

* Erbium (Er) REST Engine example.

* \author

* Matthias Kovatsch <kovatsch@inf.ethz.ch>

*/

#define LOG_TAG "coap_example"

#define LOG_LVL ELOG_LVL_INFO

#include <elog.h>

#include <stdio.h>

#include <stdlib.h>

#include <string.h>

#include <contiki.h>

#include <contiki-net.h>

#include "rest-engine.h"

#if PLATFORM_HAS_BUTTON

#include "dev/button-sensor.h"

#endif

#undef DEBUG

#define DEBUG 0

#if DEBUG

#include <stdio.h>

#define PRINTF(...) printf(__VA_ARGS__)

#define PRINT6ADDR(addr) PRINTF("[%02x%02x:%02x%02x:%02x%02x:%02x%02x:%02x%02x:%02x%02x:%02x%02x:%02x%02x]", ((uint8_t *)addr)[0], ((uint8_t *)addr)[1], ((uint8_t *)addr)[2], ((uint8_t *)addr)[3], ((uint8_t *)addr)[4], ((uint8_t *)addr)[5], ((uint8_t *)addr)[6], ((uint8_t *)addr)[7], ((uint8_t *)addr)[8], ((uint8_t *)addr)[9], ((uint8_t *)addr)[10], ((uint8_t *)addr)[11], ((uint8_t *)addr)[12], ((uint8_t *)addr)[13], ((uint8_t *)addr)[14], ((uint8_t *)addr)[15])

#define PRINTLLADDR(lladdr) PRINTF("[%02x:%02x:%02x:%02x:%02x:%02x]", (lladdr)->addr[0], (lladdr)->addr[1], (lladdr)->addr[2], (lladdr)->addr[3], (lladdr)->addr[4], (lladdr)->addr[5])

#else

#define PRINTF(...)

#define PRINT6ADDR(addr)

#define PRINTLLADDR(addr)

#endif

/*

* Resources to be activated need to be imported through the extern keyword.

* The build system automatically compiles the resources in the corresponding sub-directory.

*/

extern resource_t

res_hello,

res_cpu_usage,

res_cpu_temperature,

res_temperature,

res_water,

res_feed,

res_heat,

res_weight,

res_mirror,

res_chunks,

res_separate,

res_push,

res_event,

res_sub,

res_b1_sep_b2;

#if PLATFORM_HAS_LEDS

extern resource_t res_leds, res_toggle;

#endif

#if PLATFORM_HAS_LIGHT

#include "dev/light-sensor.h"

extern resource_t res_light;

#endif

#if PLATFORM_HAS_BATTERY

#include "dev/battery-sensor.h"

extern resource_t res_battery;

#endif

/*

extern resource_t res_battery;

#endif

#if PLATFORM_HAS_RADIO

#include "dev/radio-sensor.h"

extern resource_t res_radio;

#endif

#if PLATFORM_HAS_SHT11

#include "dev/sht11/sht11-sensor.h"

extern resource_t res_sht11;

#endif

*/

PROCESS(er_example_server, "Erbium Example Server");

PROCESS_THREAD(er_example_server, ev, data)

{

PROCESS_BEGIN();

PROCESS_PAUSE();

#ifdef RF_CHANNEL

log_d("RF channel: %u", RF_CHANNEL);

#endif

#ifdef IEEE802154_PANID

log_d("PAN ID: 0x%04X", IEEE802154_PANID);

#endif

log_d("uIP buffer: %u", UIP_BUFSIZE);

log_d("LL header: %u", UIP_LLH_LEN);

log_d("IP+UDP header: %u", UIP_IPUDPH_LEN);

log_d("REST max chunk: %u", REST_MAX_CHUNK_SIZE);

/* Initialize the REST engine. */

rest_init_engine();

log_i("Start Erbium CoAP Server success");

/*

* Bind the resources to their Uri-Path.

* WARNING: Activating twice only means alternate path, not two instances!

* All static variables are the same for each URI path.

*/

rest_activate_resource(&res_hello, "test/hello");

rest_activate_resource(&res_cpu_usage, "test/cpu_usage");

rest_activate_resource(&res_cpu_temperature, "test/cpu_temperature");

rest_activate_resource(&res_temperature, "sensors/temperature");

rest_activate_resource(&res_water, "control/water");

rest_activate_resource(&res_feed, "control/feed");

rest_activate_resource(&res_heat, "control/heat");

rest_activate_resource(&res_weight, "sensors/weight");

/* rest_activate_resource(&res_mirror, "debug/mirror"); */

/* rest_activate_resource(&res_chunks, "test/chunks"); */

/* rest_activate_resource(&res_separate, "test/separate"); */

/* rest_activate_resource(&res_push, "test/push"); */

/* rest_activate_resource(&res_event, "sensors/button"); */

/* rest_activate_resource(&res_sub, "test/sub"); */

/* rest_activate_resource(&res_b1_sep_b2, "test/b1sepb2"); */

#if PLATFORM_HAS_LEDS

/* rest_activate_resource(&res_leds, "actuators/leds"); */

rest_activate_resource(&res_toggle, "actuators/toggle");

#endif

#if PLATFORM_HAS_LIGHT

rest_activate_resource(&res_light, "sensors/light");

SENSORS_ACTIVATE(light_sensor);

#endif

#if PLATFORM_HAS_BATTERY

rest_activate_resource(&res_battery, "sensors/battery");

SENSORS_ACTIVATE(battery_sensor);

#endif

/*

#if PLATFORM_HAS_RADIO

rest_activate_resource(&res_radio, "sensors/radio");

SENSORS_ACTIVATE(radio_sensor);

#endif

#if PLATFORM_HAS_SHT11

rest_activate_resource(&res_sht11, "sensors/sht11");

SENSORS_ACTIVATE(sht11_sensor);

#endif

*/

/* Define application-specific events here. */

while(1) {

PROCESS_WAIT_EVENT();

#if PLATFORM_HAS_BUTTON

if(ev == sensors_event && data == &button_sensor) {

log_d("*******BUTTON*******\n");

/* Call the event_handler for this application-specific event. */

res_event.trigger();

/* Also call the separate response example handler. */

res_separate.resume();

}

#endif /* PLATFORM_HAS_BUTTON */

} /* while (1) */

PROCESS_END();

}

/*

* This file is part of the ART-6LoWPAN.

*

* Copyright (c) 2017, xidongxu, <xi_dongxu@126.com>

*

* Permission is hereby granted, free of charge, to any person obtaining

* a copy of this software and associated documentation files (the

* 'Software'), to deal in the Software without restriction, including

* without limitation the rights to use, copy, modify, merge, publish,

* distribute, sublicense, and/or sell copies of the Software, and to

* permit persons to whom the Software is furnished to do so, subject to

* the following conditions:

*

* The above copyright notice and this permission notice shall be

* included in all copies or substantial portions of the Software.

*

* THE SOFTWARE IS PROVIDED 'AS IS', WITHOUT WARRANTY OF ANY KIND,

* EXPRESS OR IMPLIED, INCLUDING BUT NOT LIMITED TO THE WARRANTIES OF

* MERCHANTABILITY, FITNESS FOR A PARTICULAR PURPOSE AND NONINFRINGEMENT.

* IN NO EVENT SHALL THE AUTHORS OR COPYRIGHT HOLDERS BE LIABLE FOR ANY

* CLAIM, DAMAGES OR OTHER LIABILITY, WHETHER IN AN ACTION OF CONTRACT,

* TORT OR OTHERWISE, ARISING FROM, OUT OF OR IN CONNECTION WITH THE

* SOFTWARE OR THE USE OR OTHER DEALINGS IN THE SOFTWARE.

*

* Function: Example of get the cpu inside temperature resource.

* Created on: 2017-12-08

*/

/**

* \file

* Example of get the cpu inside temperature resource

*/

#include "contiki.h"

#include <limits.h>

#include <stdlib.h>

#include <string.h>

#include "rest-engine.h"

#include <drv_cpu_temp.h>

static void res_get_handler(void *request, void *response, uint8_t *buffer, uint16_t preferred_size, int32_t *offset);

RESOURCE(res_cpu_temperature,

"title=\"CPU-temperature\";rt=\"CPU-temperature\"",

res_get_handler,

NULL,

NULL,

NULL);

static void res_get_handler(void *request, void *response, uint8_t *buffer, uint16_t preferred_size, int32_t *offset) {

uint8_t length = 0;

char temperature[10] = { 0 }, temperature_major[5] = { 0 };

snprintf(temperature_major, sizeof(temperature_major), "%d", cpu_temp_get());

strncat(temperature, temperature_major, sizeof(temperature_major));

memcpy(buffer, temperature, sizeof(temperature));

length = strlen((char *) buffer);

REST.set_header_content_type(response, REST.type.TEXT_PLAIN);

REST.set_header_etag(response, (uint8_t *) &length, 1);

REST.set_response_payload(response, (uint8_t *) buffer, length);

}

* Example of get the cpu usage resource

*/

#include "contiki.h"

#include <limits.h>

#include <stdlib.h>

#include <string.h>

#include "rest-engine.h"

#include "rtthread.h"

#include <cpuusage.h>

static void res_get_handler(void *request, void *response, uint8_t *buffer, uint16_t preferred_size, int32_t *offset);

static uint8_t cpu_usage_major, cpu_usage_minor;

RESOURCE(res_cpu_usage,

"title=\"CPU-usage\";rt=\"CPU-usage\";obs",

res_get_handler,

NULL,

NULL,

NULL);

static void res_get_handler(void *request, void *response, uint8_t *buffer, uint16_t preferred_size, int32_t *offset) {

uint8_t length = 0;

char usage[10] = { 0 }, usage_major[5] = { 0 }, usage_minor[5] = { 0 };

cpu_usage_get(&cpu_usage_major, &cpu_usage_minor);

snprintf(usage_major, sizeof(usage_major), "%d", cpu_usage_major);

snprintf(usage_minor, sizeof(usage_minor), "%d", cpu_usage_minor);

strncat(usage, usage_major, sizeof(usage_major));

strncat(usage, ".", strlen("."));

strncat(usage, usage_minor, sizeof(usage_minor));

memcpy(buffer, usage, sizeof(usage));

length = strlen((char *) buffer);

REST.set_header_content_type(response, REST.type.TEXT_PLAIN);

REST.set_header_etag(response, (uint8_t *) &length, 1);

REST.set_response_payload(response, (uint8_t *) buffer, length);

}

*/

#define LOG_TAG "feed"

#include "contiki.h"

#include <string.h>

#include "rest-engine.h"

#include <elog.h>

#include "cJSON.h"

#include "drv_relay.h"

static void res_post_put_handler(void *request, void *response, uint8_t *buffer, uint16_t preferred_size, int32_t *offset);

/*A simple actuator example, depending on the color query parameter and post variable mode, corresponding led is activated or deactivated*/

RESOURCE(res_feed,

"title=\"feed\";rt=\"Control\"",

NULL,

res_post_put_handler,

res_post_put_handler,

NULL);

static void

res_post_put_handler(void *request, void *response, uint8_t *buffer, uint16_t preferred_size, int32_t *offset)

{

size_t len = 0;

uint8_t *payload = 0;

unsigned int accept = -1;

unsigned int content_format = -1;

int ack = -1;

REST.get_header_accept(request, &accept);

REST.get_header_content_type(request, &content_format);

if(content_format == REST.type.APPLICATION_JSON)

{

if(accept == REST.type.APPLICATION_JSON)

{

len = REST.get_request_payload(request,&payload);

if(len)

{

cJSON *root = cJSON_Parse(payload);

if(root)

{

cJSON *mode = cJSON_GetObjectItem(root, "mode");

if(mode)

{

log_i("mode:%s",mode->valuestring);

if(strncmp(mode->valuestring, "on", 2) == 0)

{

cJSON *delay = cJSON_GetObjectItem(root, "delay");

if(delay)

{

log_i("delay:%d",delay->valueint);

relay_control(RELAY_FEED, 1, delay->valueint);

ack = 0;

}

}

else if(strncmp(mode->valuestring, "off", 3) == 0)

{

relay_control(RELAY_FEED, 0, -1);

ack = 0;

}

}

cJSON_Delete(root);

}

}

}

}

else

{

REST.set_response_status(response, REST.status.BAD_REQUEST);

return;

}

REST.set_header_content_type(response, REST.type.APPLICATION_JSON);

snprintf((char *)buffer, REST_MAX_CHUNK_SIZE, "{\"ack\":%d}", ack);

REST.set_response_payload(response, buffer, strlen((char *)buffer));

}

#define LOG_TAG "heat"

#include "contiki.h"

#include <string.h>

#include "rest-engine.h"

#include <elog.h>

#include "cJSON.h"

#include "drv_relay.h"

static void res_post_put_handler(void *request, void *response, uint8_t *buffer, uint16_t preferred_size, int32_t *offset);

/*A simple actuator example, depending on the color query parameter and post variable mode, corresponding led is activated or deactivated*/

RESOURCE(res_heat,

"title=\"heat\";rt=\"Control\"",

NULL,

res_post_put_handler,

res_post_put_handler,

NULL);

static void

res_post_put_handler(void *request, void *response, uint8_t *buffer, uint16_t preferred_size, int32_t *offset)

{

size_t len = 0;

uint8_t *payload = 0;

unsigned int accept = -1;

unsigned int content_format = -1;

int ack = -1;

REST.get_header_accept(request, &accept);

REST.get_header_content_type(request, &content_format);

if(content_format == REST.type.APPLICATION_JSON)

{

if(accept == REST.type.APPLICATION_JSON)

{

len = REST.get_request_payload(request,&payload);

if(len)

{

cJSON *root = cJSON_Parse(payload);

if(root)

{

cJSON *mode = cJSON_GetObjectItem(root, "mode");

if(mode)

{

log_i("mode:%s",mode->valuestring);

if(strncmp(mode->valuestring, "on", 2) == 0)

{

cJSON *delay = cJSON_GetObjectItem(root, "delay");

if(delay)

{

log_i("delay:%d",delay->valueint);

relay_control(RELAY_HEAT1, 1, delay->valueint);

relay_control(RELAY_HEAT2, 1, delay->valueint);

ack = 0;

}

}

else if(strncmp(mode->valuestring, "off", 3) == 0)

{

relay_control(RELAY_HEAT1, 0, -1);

relay_control(RELAY_HEAT2, 0, -1);

ack = 0;

}

}

cJSON_Delete(root);

}

}

}

}

else

{

REST.set_response_status(response, REST.status.BAD_REQUEST);

return;

}

REST.set_header_content_type(response, REST.type.APPLICATION_JSON);

snprintf((char *)buffer, REST_MAX_CHUNK_SIZE, "{\"ack\":%d}", ack);

REST.set_response_payload(response, buffer, strlen((char *)buffer));

}

#include "contiki.h"

#include <limits.h>

#include <stdlib.h>

#include <string.h>

#include "rest-engine.h"

#include "drv_ds18b20.h"

static void res_get_handler(void *request, void *response, uint8_t *buffer, uint16_t preferred_size, int32_t *offset);

static void res_periodic_handler(void);

#define MAX_AGE 60 // 60s

#define INTERVAL_MIN 5

#define INTERVAL_MAX (MAX_AGE - 1)

#define CHANGE 1 // 1

static int32_t interval_counter = INTERVAL_MIN;

static int temperature_old = INT_MIN;

PERIODIC_RESOURCE(res_temperature,

"title=\"Temperature\";rt=\"Temperature\";obs",

res_get_handler,

NULL,

NULL,

NULL,

CLOCK_SECOND,

res_periodic_handler);

static void

res_get_handler(void *request, void *response, uint8_t *buffer, uint16_t preferred_size, int32_t *offset)

{

/*

* For minimal complexity, request query and options should be ignored for GET on observable resources.

* Otherwise the requests must be stored with the observer list and passed by REST.notify_subscribers().

* This would be a TODO in the corresponding files in contiki/apps/erbium/!

*/

int temperature = ds18b20_get_temp();

//rt_kprintf("temp $%d\r\n", temperature);

unsigned int accept = -1;

REST.get_header_accept(request, &accept);

if( accept == REST.type.TEXT_PLAIN) {

REST.set_header_content_type(response, REST.type.TEXT_PLAIN);

snprintf((char *)buffer, REST_MAX_CHUNK_SIZE, "%d", temperature);

REST.set_response_payload(response, (uint8_t *)buffer, strlen((char *)buffer));

} else if(accept == -1 || accept == REST.type.APPLICATION_JSON) {

REST.set_header_content_type(response, REST.type.APPLICATION_JSON);

snprintf((char *)buffer, REST_MAX_CHUNK_SIZE, "{\"temperature\":%d}", temperature);

REST.set_response_payload(response, buffer, strlen((char *)buffer));

} else {

REST.set_response_status(response, REST.status.NOT_ACCEPTABLE);

const char *msg = "Supporting content-types text/plain and application/json";

REST.set_response_payload(response, msg, strlen(msg));

}

REST.set_header_max_age(response, MAX_AGE);

/* The REST.subscription_handler() will be called for observable resources by the REST framework. */

}

/*

* Additionally, a handler function named [resource name]_handler must be implemented for each PERIODIC_RESOURCE.

* It will be called by the REST manager process with the defined period.

*/

static void

res_periodic_handler()

{

int temperature = ds18b20_get_temp();

//rt_kprintf("temp $%d\r\n", temperature);

++interval_counter;

if((abs(temperature - temperature_old) >= CHANGE && interval_counter >= INTERVAL_MIN) ||

interval_counter >= INTERVAL_MAX) {

interval_counter = 0;

temperature_old = temperature;

/* Notify the registered observers which will trigger the res_get_handler to create the response. */

REST.notify_subscribers(&res_temperature);

}

}

* Matthias Kovatsch <kovatsch@inf.ethz.ch>

*/

#define LOG_TAG "water"

#include "contiki.h"

#include <string.h>

#include "rest-engine.h"

#include <elog.h>

#include "cJSON.h"

#include "drv_relay.h"

static void res_post_put_handler(void *request, void *response, uint8_t *buffer, uint16_t preferred_size, int32_t *offset);

/*A simple actuator example, depending on the color query parameter and post variable mode, corresponding led is activated or deactivated*/

RESOURCE(res_water,

"title=\"water control\";rt=\"Control\"",

NULL,

res_post_put_handler,

res_post_put_handler,

NULL);

static void

res_post_put_handler(void *request, void *response, uint8_t *buffer, uint16_t preferred_size, int32_t *offset)

{

size_t len = 0;

uint8_t *payload = 0;

unsigned int accept = -1;

unsigned int content_format = -1;

int ack = -1;

REST.get_header_accept(request, &accept);

REST.get_header_content_type(request, &content_format);

if(content_format == REST.type.APPLICATION_JSON)

{

if(accept == REST.type.APPLICATION_JSON)

{

len = REST.get_request_payload(request,&payload);

if(len)

{

cJSON *root = cJSON_Parse(payload);

if(root)

{

cJSON *mode = cJSON_GetObjectItem(root, "mode");

if(mode)

{

log_i("mode:%s",mode->valuestring);

if(strncmp(mode->valuestring, "on", 2) == 0)

{

cJSON *delay = cJSON_GetObjectItem(root, "delay");

if(delay)

{

log_i("delay:%d",delay->valueint);

relay_control(RELAY_WATER, 1, delay->valueint);

ack = 0;

}

}

else if(strncmp(mode->valuestring, "off", 3) == 0)

{

relay_control(RELAY_WATER, 0, -1);

ack = 0;

}

}

cJSON_Delete(root);

}

}

}

}

else

{

REST.set_response_status(response, REST.status.BAD_REQUEST);

return;

}

REST.set_header_content_type(response, REST.type.APPLICATION_JSON);

snprintf((char *)buffer, REST_MAX_CHUNK_SIZE, "{\"ack\":%d}", ack);

REST.set_response_payload(response, buffer, strlen((char *)buffer));

}

#include "contiki.h"

#include <limits.h>

#include <stdlib.h>

#include <string.h>

#include "rest-engine.h"

#include "drv_hx711.h"

static void res_get_handler(void *request, void *response, uint8_t *buffer, uint16_t preferred_size, int32_t *offset);

static void res_periodic_handler(void);

#define MAX_AGE 60 // 60s

#define INTERVAL_MIN 1

#define INTERVAL_MAX (MAX_AGE - 1)

#define CHANGE 0.5 // 0.5kg

static int32_t interval_counter = INTERVAL_MIN;

static float weight_old = 0;

PERIODIC_RESOURCE(res_weight,

"title=\"Weight\";rt=\"Weight\";obs",

res_get_handler,

NULL,

NULL,

NULL,

CLOCK_SECOND*20,

res_periodic_handler);

static void

res_get_handler(void *request, void *response, uint8_t *buffer, uint16_t preferred_size, int32_t *offset)

{

/*

* For minimal complexity, request query and options should be ignored for GET on observable resources.

* Otherwise the requests must be stored with the observer list and passed by REST.notify_subscribers().

* This would be a TODO in the corresponding files in contiki/apps/erbium/!

*/

char str[50];

float weight = hx711_weight_get();

sprintf(str,"get_weight:%f---------------------------",weight);

rt_kprintf(str);

unsigned int accept = -1;

REST.get_header_accept(request, &accept);

if(accept == REST.type.TEXT_PLAIN) {

REST.set_header_content_type(response, REST.type.TEXT_PLAIN);

snprintf((char *)buffer, REST_MAX_CHUNK_SIZE, "%.1f", weight);

REST.set_response_payload(response, (uint8_t *)buffer, strlen((char *)buffer));

} else if(accept == -1 || accept == REST.type.APPLICATION_JSON) {

REST.set_header_content_type(response, REST.type.APPLICATION_JSON);

snprintf((char *)buffer, REST_MAX_CHUNK_SIZE, "{\"weight\":%.1f}", weight);

REST.set_response_payload(response, buffer, strlen((char *)buffer));

} else {

REST.set_response_status(response, REST.status.NOT_ACCEPTABLE);

const char *msg = "Supporting content-types text/plain and application/json";

REST.set_response_payload(response, msg, strlen(msg));

}

REST.set_header_max_age(response, MAX_AGE);

/* The REST.subscription_handler() will be called for observable resources by the REST framework. */

}

/*

* Additionally, a handler function named [resource name]_handler must be implemented for each PERIODIC_RESOURCE.

* It will be called by the REST manager process with the defined period.

*/

static void

res_periodic_handler()

{

char str[50] = {0};

float weight = hx711_weight_get();

float change = weight>weight_old?(weight-weight_old):(weight_old-weight);

sprintf(str,"res_weight:%f---------------------------",weight);

rt_kprintf(str);

++interval_counter;

if((change >= CHANGE && interval_counter >= INTERVAL_MIN) ||

interval_counter >= INTERVAL_MAX) {

interval_counter = 0;

weight_old = weight;

/* Notify the registered observers which will trigger the res_get_handler to create the response. */

REST.notify_subscribers(&res_weight);

}

}

#include <string.h>

#include <stdio.h>

#include "contiki.h"

#include "rest-engine.h"

#define DEBUG 0

#if DEBUG

#include <stdio.h>

#define PRINTF(...) printf(__VA_ARGS__)

#define PRINT6ADDR(addr) PRINTF("[%02x%02x:%02x%02x:%02x%02x:%02x%02x:%02x%02x:%02x%02x:%02x%02x:%02x%02x]", ((uint8_t *)addr)[0], ((uint8_t *)addr)[1], ((uint8_t *)addr)[2], ((uint8_t *)addr)[3], ((uint8_t *)addr)[4], ((uint8_t *)addr)[5], ((uint8_t *)addr)[6], ((uint8_t *)addr)[7], ((uint8_t *)addr)[8], ((uint8_t *)addr)[9], ((uint8_t *)addr)[10], ((uint8_t *)addr)[11], ((uint8_t *)addr)[12], ((uint8_t *)addr)[13], ((uint8_t *)addr)[14], ((uint8_t *)addr)[15])

#define PRINTLLADDR(lladdr) PRINTF("[%02x:%02x:%02x:%02x:%02x:%02x]", (lladdr)->addr[0], (lladdr)->addr[1], (lladdr)->addr[2], (lladdr)->addr[3], (lladdr)->addr[4], (lladdr)->addr[5])

#else

#define PRINTF(...)

#define PRINT6ADDR(addr)

#define PRINTLLADDR(addr)

#endif

PROCESS(rest_engine_process, "REST Engine");

/*---------------------------------------------------------------------------*/

LIST(restful_services);

LIST(restful_periodic_services);

/*---------------------------------------------------------------------------*/

/*- REST Engine API ---------------------------------------------------------*/

/*---------------------------------------------------------------------------*/

/**

* \brief Initializes and starts the REST Engine process

*

* This function must be called by server processes before any resources are

* registered through rest_activate_resource().

*/

void

rest_init_engine(void)

{

list_init(restful_services);

REST.set_service_callback(rest_invoke_restful_service);

/* Start the RESTful server implementation. */

REST.init();

/*Start REST engine process */

process_start(&rest_engine_process, NULL);

}

/*---------------------------------------------------------------------------*/

/**

* \brief Makes a resource available under the given URI path

* \param resource A pointer to a resource implementation

* \param path The URI path string for this resource

*

* The resource implementation must be imported first using the

* extern keyword. The build system takes care of compiling every

* *.c file in the ./resources/ sub-directory (see example Makefile).

*/

void

rest_activate_resource(resource_t *resource, char *path)

{

resource->url = path;

list_add(restful_services, resource);

PRINTF("Activating: %s\n", resource->url);

/* Only add periodic resources with a periodic_handler and a period > 0. */

if(resource->flags & IS_PERIODIC && resource->periodic->periodic_handler

&& resource->periodic->period) {

PRINTF("Periodic resource: %p (%s)\n", resource->periodic,

resource->periodic->resource->url);

list_add(restful_periodic_services, resource->periodic);

}

}

/*---------------------------------------------------------------------------*/

/*- Internal API ------------------------------------------------------------*/

/*---------------------------------------------------------------------------*/

list_t

rest_get_resources(void)

{

return restful_services;

}

/*---------------------------------------------------------------------------*/

int

rest_invoke_restful_service(void *request, void *response, uint8_t *buffer,

uint16_t buffer_size, int32_t *offset)

{

uint8_t found = 0;

uint8_t allowed = 1;

resource_t *resource = NULL;

const char *url = NULL;

for(resource = (resource_t *)list_head(restful_services);

resource; resource = resource->next) {

/* if the web service handles that kind of requests and urls matches */

if((REST.get_url(request, &url) == strlen(resource->url)

|| (REST.get_url(request, &url) > strlen(resource->url)

&& (resource->flags & HAS_SUB_RESOURCES)))

&& strncmp(resource->url, url, strlen(resource->url)) == 0) {

found = 1;

rest_resource_flags_t method = REST.get_method_type(request);

PRINTF("/%s, method %u, resource->flags %u\n", resource->url,

(uint16_t)method, resource->flags);

if((method & METHOD_GET) && resource->get_handler != NULL) {

/* call handler function */

resource->get_handler(request, response, buffer, buffer_size, offset);

} else if((method & METHOD_POST) && resource->post_handler != NULL) {

/* call handler function */

resource->post_handler(request, response, buffer, buffer_size,

offset);

} else if((method & METHOD_PUT) && resource->put_handler != NULL) {

/* call handler function */

resource->put_handler(request, response, buffer, buffer_size, offset);

} else if((method & METHOD_DELETE) && resource->delete_handler != NULL) {

/* call handler function */

resource->delete_handler(request, response, buffer, buffer_size,

offset);

} else {

allowed = 0;

REST.set_response_status(response, REST.status.METHOD_NOT_ALLOWED);

}

break;

}

}

if(!found) {

REST.set_response_status(response, REST.status.NOT_FOUND);

} else if(allowed) {

/* final handler for special flags */

if(resource->flags & IS_OBSERVABLE) {

REST.subscription_handler(resource, request, response);

}

}

return found & allowed;

}

/*-----------------------------------------------------------------------------

PROCESS_THREAD(rest_engine_process, ev, data)

{

PROCESS_BEGIN();

/* pause to let REST server finish adding resources. */

PROCESS_PAUSE();

/* initialize the PERIODIC_RESOURCE timers, which will be handled by this process. */

periodic_resource_t *periodic_resource = NULL;

for(periodic_resource =

(periodic_resource_t *)list_head(restful_periodic_services);

periodic_resource; periodic_resource = periodic_resource->next) {

if(periodic_resource->periodic_handler && periodic_resource->period) {

PRINTF("Periodic: Set timer for /%s to %lu\n",

periodic_resource->resource->url, periodic_resource->period);

etimer_set(&periodic_resource->periodic_timer,

periodic_resource->period);

}

}

while(1) {

PROCESS_WAIT_EVENT();

if(ev == PROCESS_EVENT_TIMER) {

for(periodic_resource =

(periodic_resource_t *)list_head(restful_periodic_services);

periodic_resource; periodic_resource = periodic_resource->next) {

if(periodic_resource->period

&& etimer_expired(&periodic_resource->periodic_timer)) {

PRINTF("Periodic: etimer expired for /%s (period: %lu)\n",

periodic_resource->resource->url, periodic_resource->period);

/* Call the periodic_handler function, which was checked during adding to list. */

(periodic_resource->periodic_handler)();

etimer_reset(&periodic_resource->periodic_timer);

}

}

}

}

PROCESS_END();

}

/*---------------------------------------------------------------------------*/

#include <stdlib.h>

#include <string.h>

#include "rest-engine.h"

static void res_get_handler(void *request, void *response, uint8_t *buffer, uint16_t preferred_size, int32_t *offset);

/*

* A handler function named [resource name]_handler must be implemented for each RESOURCE.

* A buffer for the response payload is provided through the buffer pointer. Simple resources can ignore

* preferred_size and offset, but must respect the REST_MAX_CHUNK_SIZE limit for the buffer.

* If a smaller block size is requested for CoAP, the REST framework automatically splits the data.

*/

RESOURCE(res_hello,

"title=\"Hello world: ?len=0..\";rt=\"Text\"",

res_get_handler,

NULL,

NULL,

NULL);

static void

res_get_handler(void *request, void *response, uint8_t *buffer, uint16_t preferred_size, int32_t *offset)

{

const char *len = NULL;

/* Some data that has the length up to REST_MAX_CHUNK_SIZE. For more, see the chunk resource. */

char const *const message = "Hello World! ABCDEFGHIJKLMNOPQRSTUVWXYZabcdefghijklmnopqrstuvwxy";

int length = 12; /* |<-------->| */

/* The query string can be retrieved by rest_get_query() or parsed for its key-value pairs. */

if(REST.get_query_variable(request, "len", &len)) {

length = atoi(len);

if(length < 0) {

length = 0;

}

if(length > REST_MAX_CHUNK_SIZE) {

length = REST_MAX_CHUNK_SIZE;

}

memcpy(buffer, message, length);

} else {

memcpy(buffer, message, length);

} REST.set_header_content_type(response, REST.type.TEXT_PLAIN); /* text/plain is the default, hence this option could be omitted. */

REST.set_header_etag(response, (uint8_t *)&length, 1);

REST.set_response_payload(response, buffer, length);

}

#include "net/llsec/anti-replay.h"

#include "net/packetbuf.h"

#include "net/llsec/llsec802154.h"

#if LLSEC802154_USES_FRAME_COUNTER

/* This node's current frame counter value */

static uint32_t counter;

/*---------------------------------------------------------------------------*/

void

anti_replay_set_counter(void)

{

frame802154_frame_counter_t reordered_counter;

++counter;

reordered_counter.u32 = LLSEC802154_HTONL(counter);

packetbuf_set_attr(PACKETBUF_ATTR_FRAME_COUNTER_BYTES_0_1, reordered_counter.u16[0]);

packetbuf_set_attr(PACKETBUF_ATTR_FRAME_COUNTER_BYTES_2_3, reordered_counter.u16[1]);

}

/*---------------------------------------------------------------------------*/

uint32_t

anti_replay_get_counter(void)

{

frame802154_frame_counter_t disordered_counter;

disordered_counter.u16[0] = packetbuf_attr(PACKETBUF_ATTR_FRAME_COUNTER_BYTES_0_1);

disordered_counter.u16[1] = packetbuf_attr(PACKETBUF_ATTR_FRAME_COUNTER_BYTES_2_3);

return LLSEC802154_HTONL(disordered_counter.u32);

}

/*---------------------------------------------------------------------------*/

void

anti_replay_init_info(struct anti_replay_info *info)

{

info->last_broadcast_counter

= info->last_unicast_counter

= anti_replay_get_counter();

}

/*---------------------------------------------------------------------------*/

int

anti_replay_was_replayed(struct anti_replay_info *info)

{

uint32_t received_counter;

received_counter = anti_replay_get_counter();

if(packetbuf_holds_broadcast()) {

/* broadcast */

if(received_counter <= info->last_broadcast_counter) {

return 1;

} else {

info->last_broadcast_counter = received_counter;

return 0;

}

} else {

/* unicast */

if(received_counter <= info->last_unicast_counter) {

return 1;

} else {

info->last_unicast_counter = received_counter;

return 0;

}

}

}

#include <rthw.h>

#include <rtdevice.h>

#include <board.h>

#ifdef RT_USING_PIN

#define STM32_PIN_NUMBERS 64 //[48, 64, 100, 144 ]

#define __STM32_PIN(index, rcc, gpio, gpio_index) { 0, RCC_##rcc##Periph_GPIO##gpio, GPIO##gpio, GPIO_Pin_##gpio_index}

#define __STM32_PIN_DEFAULT {-1, 0, 0, 0}

#define ITEM_NUM(items) sizeof(items)/sizeof(items[0])

/* STM32 GPIO driver */

struct pin_index

{

int index;

uint32_t rcc;

GPIO_TypeDef *gpio;

uint32_t pin;

};

/* STM32 GPIO irq information */

struct pin_irq

{

/* EXTI port source gpiox, such as EXTI_PortSourceGPIOA */

rt_uint8_t port_source;

/* EXTI pin sources, such as EXTI_PinSource0 */

rt_uint8_t pin_source;

/* NVIC IRQ EXTI channel, such as EXTI0_IRQn */

enum IRQn irq_exti_channel;

/* EXTI line, such as EXTI_Line0 */

rt_uint32_t exti_line;

};

static const struct pin_index pins[] =

{

#if (STM32_PIN_NUMBERS == 48)

__STM32_PIN_DEFAULT,

__STM32_PIN_DEFAULT,

__STM32_PIN(2, AHB1, C, 13),

__STM32_PIN(3, AHB1, C, 14),

__STM32_PIN(4, AHB1, C, 15),

__STM32_PIN_DEFAULT,

__STM32_PIN_DEFAULT,

__STM32_PIN_DEFAULT,

__STM32_PIN_DEFAULT,

__STM32_PIN_DEFAULT,

__STM32_PIN(10, AHB1, A, 0),

__STM32_PIN(11, AHB1, A, 1),

__STM32_PIN(12, AHB1, A, 2),

__STM32_PIN(13, AHB1, A, 3),

__STM32_PIN(14, AHB1, A, 4),

__STM32_PIN(15, AHB1, A, 5),

__STM32_PIN(16, AHB1, A, 6),

__STM32_PIN(17, AHB1, A, 7),

__STM32_PIN(18, AHB1, B, 0),

__STM32_PIN(19, AHB1, B, 1),

__STM32_PIN(20, AHB1, B, 2),

__STM32_PIN(21, AHB1, B, 10),

__STM32_PIN(22, AHB1, B, 11),

__STM32_PIN_DEFAULT,

__STM32_PIN_DEFAULT,

__STM32_PIN(25, AHB1, B, 12),

__STM32_PIN(26, AHB1, B, 13),

__STM32_PIN(27, AHB1, B, 14),

__STM32_PIN(28, AHB1, B, 15),

__STM32_PIN(29, AHB1, A, 8),

__STM32_PIN(30, AHB1, A, 9),

__STM32_PIN(31, AHB1, A, 10),

__STM32_PIN(32, AHB1, A, 11),

__STM32_PIN(33, AHB1, A, 12),

__STM32_PIN(34, AHB1, A, 13),

__STM32_PIN_DEFAULT,

__STM32_PIN_DEFAULT,

__STM32_PIN(37, AHB1, A, 14),

__STM32_PIN(38, AHB1, A, 15),

__STM32_PIN(39, AHB1, B, 3),

__STM32_PIN(40, AHB1, B, 4),

__STM32_PIN(41, AHB1, B, 5),

__STM32_PIN(42, AHB1, B, 6),

__STM32_PIN(43, AHB1, B, 7),

__STM32_PIN_DEFAULT,

__STM32_PIN(45, AHB1, B, 8),

__STM32_PIN(46, AHB1, B, 9),

__STM32_PIN_DEFAULT,

__STM32_PIN_DEFAULT,

#endif

#if (STM32_PIN_NUMBERS == 64)

__STM32_PIN_DEFAULT,

__STM32_PIN_DEFAULT,

__STM32_PIN(2, AHB1, C, 13),

__STM32_PIN(3, AHB1, C, 14),

__STM32_PIN(4, AHB1, C, 15),

__STM32_PIN(5, AHB1, D, 0),

__STM32_PIN(6, AHB1, D, 1),

__STM32_PIN_DEFAULT,

__STM32_PIN(8, AHB1, C, 0),

__STM32_PIN(9, AHB1, C, 1),

__STM32_PIN(10, AHB1, C, 2),

__STM32_PIN(11, AHB1, C, 3),

__STM32_PIN_DEFAULT,

__STM32_PIN_DEFAULT,

__STM32_PIN(14, AHB1, A, 0),

__STM32_PIN(15, AHB1, A, 1),

__STM32_PIN(16, AHB1, A, 2),

__STM32_PIN(17, AHB1, A, 3),

__STM32_PIN_DEFAULT,

__STM32_PIN_DEFAULT,

__STM32_PIN(20, AHB1, A, 4),

__STM32_PIN(21, AHB1, A, 5),

__STM32_PIN(22, AHB1, A, 6),

__STM32_PIN(23, AHB1, A, 7),

__STM32_PIN(24, AHB1, C, 4),

__STM32_PIN(25, AHB1, C, 5),

__STM32_PIN(26, AHB1, B, 0),

__STM32_PIN(27, AHB1, B, 1),

__STM32_PIN(28, AHB1, B, 2),

__STM32_PIN(29, AHB1, B, 10),

__STM32_PIN(30, AHB1, B, 11),

__STM32_PIN_DEFAULT,

__STM32_PIN_DEFAULT,

__STM32_PIN(33, AHB1, B, 12),

__STM32_PIN(34, AHB1, B, 13),

__STM32_PIN(35, AHB1, B, 14),

__STM32_PIN(36, AHB1, B, 15),

__STM32_PIN(37, AHB1, C, 6),

__STM32_PIN(38, AHB1, C, 7),

__STM32_PIN(39, AHB1, C, 8),

__STM32_PIN(40, AHB1, C, 9),

__STM32_PIN(41, AHB1, A, 8),

__STM32_PIN(42, AHB1, A, 9),

__STM32_PIN(43, AHB1, A, 10),

__STM32_PIN(44, AHB1, A, 11),

__STM32_PIN(45, AHB1, A, 12),

__STM32_PIN(46, AHB1, A, 13),

__STM32_PIN_DEFAULT,

__STM32_PIN_DEFAULT,

__STM32_PIN(49, AHB1, A, 14),

__STM32_PIN(50, AHB1, A, 15),

__STM32_PIN(51, AHB1, C, 10),

__STM32_PIN(52, AHB1, C, 11),

__STM32_PIN(53, AHB1, C, 12),

__STM32_PIN(54, AHB1, D, 2),

__STM32_PIN(55, AHB1, B, 3),

__STM32_PIN(56, AHB1, B, 4),

__STM32_PIN(57, AHB1, B, 5),

__STM32_PIN(58, AHB1, B, 6),

__STM32_PIN(59, AHB1, B, 7),

__STM32_PIN_DEFAULT,

__STM32_PIN(61, AHB1, B, 8),

__STM32_PIN(62, AHB1, B, 9),

__STM32_PIN_DEFAULT,

__STM32_PIN_DEFAULT,

#endif

#if (STM32_PIN_NUMBERS == 100)

__STM32_PIN_DEFAULT,

__STM32_PIN(1, AHB1, E, 2),

__STM32_PIN(2, AHB1, E, 3),

__STM32_PIN(3, AHB1, E, 4),

__STM32_PIN(4, AHB1, E, 5),

__STM32_PIN(5, AHB1, E, 6),

__STM32_PIN_DEFAULT,

__STM32_PIN(7, AHB1, C, 13),

__STM32_PIN(8, AHB1, C, 14),

__STM32_PIN(9, AHB1, C, 15),

__STM32_PIN_DEFAULT,

__STM32_PIN_DEFAULT,

__STM32_PIN_DEFAULT,

__STM32_PIN_DEFAULT,

__STM32_PIN_DEFAULT,

__STM32_PIN(15, AHB1, C, 0),

__STM32_PIN(16, AHB1, C, 1),

__STM32_PIN(17, AHB1, C, 2),

__STM32_PIN(18, AHB1, C, 3),

__STM32_PIN_DEFAULT,

__STM32_PIN_DEFAULT,

__STM32_PIN_DEFAULT,

__STM32_PIN_DEFAULT,

__STM32_PIN(23, AHB1, A, 0),

__STM32_PIN(24, AHB1, A, 1),

__STM32_PIN(25, AHB1, A, 2),

__STM32_PIN(26, AHB1, A, 3),

__STM32_PIN_DEFAULT,

__STM32_PIN_DEFAULT,

__STM32_PIN(29, AHB1, A, 4),

__STM32_PIN(30, AHB1, A, 5),

__STM32_PIN(31, AHB1, A, 6),

__STM32_PIN(32, AHB1, A, 7),

__STM32_PIN(33, AHB1, C, 4),

__STM32_PIN(34, AHB1, C, 5),

__STM32_PIN(35, AHB1, B, 0),

__STM32_PIN(36, AHB1, B, 1),

__STM32_PIN(37, AHB1, B, 2),

__STM32_PIN(38, AHB1, E, 7),

__STM32_PIN(39, AHB1, E, 8),

__STM32_PIN(40, AHB1, E, 9),

__STM32_PIN(41, AHB1, E, 10),

__STM32_PIN(42, AHB1, E, 11),

__STM32_PIN(43, AHB1, E, 12),

__STM32_PIN(44, AHB1, E, 13),

__STM32_PIN(45, AHB1, E, 14),

__STM32_PIN(46, AHB1, E, 15),

__STM32_PIN(47, AHB1, B, 10),

__STM32_PIN(48, AHB1, B, 11),

__STM32_PIN_DEFAULT,

__STM32_PIN_DEFAULT,

__STM32_PIN(51, AHB1, B, 12),

__STM32_PIN(52, AHB1, B, 13),

__STM32_PIN(53, AHB1, B, 14),

__STM32_PIN(54, AHB1, B, 15),

__STM32_PIN(55, AHB1, D, 8),

__STM32_PIN(56, AHB1, D, 9),

__STM32_PIN(57, AHB1, D, 10),

__STM32_PIN(58, AHB1, D, 11),

__STM32_PIN(59, AHB1, D, 12),

__STM32_PIN(60, AHB1, D, 13),

__STM32_PIN(61, AHB1, D, 14),

__STM32_PIN(62, AHB1, D, 15),

__STM32_PIN(63, AHB1, C, 6),

__STM32_PIN(64, AHB1, C, 7),

__STM32_PIN(65, AHB1, C, 8),

__STM32_PIN(66, AHB1, C, 9),

__STM32_PIN(67, AHB1, A, 8),

__STM32_PIN(68, AHB1, A, 9),

__STM32_PIN(69, AHB1, A, 10),

__STM32_PIN(70, AHB1, A, 11),

__STM32_PIN(71, AHB1, A, 12),

__STM32_PIN(72, AHB1, A, 13),

__STM32_PIN_DEFAULT,

__STM32_PIN_DEFAULT,

__STM32_PIN_DEFAULT,

__STM32_PIN(76, AHB1, A, 14),

__STM32_PIN(77, AHB1, A, 15),

__STM32_PIN(78, AHB1, C, 10),

__STM32_PIN(79, AHB1, C, 11),

__STM32_PIN(80, AHB1, C, 12),

__STM32_PIN(81, AHB1, D, 0),

__STM32_PIN(82, AHB1, D, 1),

__STM32_PIN(83, AHB1, D, 2),

__STM32_PIN(84, AHB1, D, 3),

__STM32_PIN(85, AHB1, D, 4),

__STM32_PIN(86, AHB1, D, 5),

__STM32_PIN(87, AHB1, D, 6),

__STM32_PIN(88, AHB1, D, 7),

__STM32_PIN(89, AHB1, B, 3),

__STM32_PIN(90, AHB1, B, 4),

__STM32_PIN(91, AHB1, B, 5),

__STM32_PIN(92, AHB1, B, 6),

__STM32_PIN(93, AHB1, B, 7),

__STM32_PIN_DEFAULT,

__STM32_PIN(95, AHB1, B, 8),

__STM32_PIN(96, AHB1, B, 9),

__STM32_PIN(97, AHB1, E, 0),

__STM32_PIN(98, AHB1, E, 1),

__STM32_PIN_DEFAULT,

__STM32_PIN_DEFAULT,

#endif

#if (STM32_PIN_NUMBERS == 144)

__STM32_PIN_DEFAULT,

__STM32_PIN(1, AHB1, E, 2),

__STM32_PIN(2, AHB1, E, 3),

__STM32_PIN(3, AHB1, E, 4),

__STM32_PIN(4, AHB1, E, 5),

__STM32_PIN(5, AHB1, E, 6),

__STM32_PIN_DEFAULT,

__STM32_PIN(7, AHB1, C, 13),

__STM32_PIN(8, AHB1, C, 14),

__STM32_PIN(9, AHB1, C, 15),

__STM32_PIN(10, AHB1, F, 0),

__STM32_PIN(11, AHB1, F, 1),

__STM32_PIN(12, AHB1, F, 2),

__STM32_PIN(13, AHB1, F, 3),

__STM32_PIN(14, AHB1, F, 4),

__STM32_PIN(15, AHB1, F, 5),

__STM32_PIN_DEFAULT,

__STM32_PIN_DEFAULT,

__STM32_PIN(18, AHB1, F, 6),

__STM32_PIN(19, AHB1, F, 7),

__STM32_PIN(20, AHB1, F, 8),

__STM32_PIN(21, AHB1, F, 9),

__STM32_PIN(22, AHB1, F, 10),

__STM32_PIN_DEFAULT,

__STM32_PIN_DEFAULT,

__STM32_PIN_DEFAULT,

__STM32_PIN(26, AHB1, C, 0),

__STM32_PIN(27, AHB1, C, 1),

__STM32_PIN(28, AHB1, C, 2),

__STM32_PIN(29, AHB1, C, 3),

__STM32_PIN_DEFAULT,

__STM32_PIN_DEFAULT,

__STM32_PIN_DEFAULT,

__STM32_PIN_DEFAULT,

__STM32_PIN(34, AHB1, A, 0),

__STM32_PIN(35, AHB1, A, 1),

__STM32_PIN(36, AHB1, A, 2),

__STM32_PIN(37, AHB1, A, 3),

__STM32_PIN_DEFAULT,

__STM32_PIN_DEFAULT,

__STM32_PIN(40, AHB1, A, 4),

__STM32_PIN(41, AHB1, A, 5),

__STM32_PIN(42, AHB1, A, 6),

__STM32_PIN(43, AHB1, A, 7),

__STM32_PIN(44, AHB1, C, 4),

__STM32_PIN(45, AHB1, C, 5),

__STM32_PIN(46, AHB1, B, 0),

__STM32_PIN(47, AHB1, B, 1),

__STM32_PIN(48, AHB1, B, 2),

__STM32_PIN(49, AHB1, F, 11),

__STM32_PIN(50, AHB1, F, 12),

__STM32_PIN_DEFAULT,

__STM32_PIN_DEFAULT,

__STM32_PIN(53, AHB1, F, 13),

__STM32_PIN(54, AHB1, F, 14),

__STM32_PIN(55, AHB1, F, 15),

__STM32_PIN(56, AHB1, G, 0),

__STM32_PIN(57, AHB1, G, 1),

__STM32_PIN(58, AHB1, E, 7),

__STM32_PIN(59, AHB1, E, 8),

__STM32_PIN(60, AHB1, E, 9),

__STM32_PIN_DEFAULT,

__STM32_PIN_DEFAULT,

__STM32_PIN(63, AHB1, E, 10),

__STM32_PIN(64, AHB1, E, 11),

__STM32_PIN(65, AHB1, E, 12),

__STM32_PIN(66, AHB1, E, 13),

__STM32_PIN(67, AHB1, E, 14),

__STM32_PIN(68, AHB1, E, 15),

__STM32_PIN(69, AHB1, B, 10),

__STM32_PIN(70, AHB1, B, 11),

__STM32_PIN_DEFAULT,

__STM32_PIN_DEFAULT,

__STM32_PIN(73, AHB1, B, 12),

__STM32_PIN(74, AHB1, B, 13),

__STM32_PIN(75, AHB1, B, 14),

__STM32_PIN(76, AHB1, B, 15),

__STM32_PIN(77, AHB1, D, 8),

__STM32_PIN(78, AHB1, D, 9),

__STM32_PIN(79, AHB1, D, 10),

__STM32_PIN(80, AHB1, D, 11),

__STM32_PIN(81, AHB1, D, 12),

__STM32_PIN(82, AHB1, D, 13),

__STM32_PIN_DEFAULT,

__STM32_PIN_DEFAULT,

__STM32_PIN(85, AHB1, D, 14),

__STM32_PIN(86, AHB1, D, 15),

__STM32_PIN(87, AHB1, G, 2),

__STM32_PIN(88, AHB1, G, 3),

__STM32_PIN(89, AHB1, G, 4),

__STM32_PIN(90, AHB1, G, 5),

__STM32_PIN(91, AHB1, G, 6),

__STM32_PIN(92, AHB1, G, 7),

__STM32_PIN(93, AHB1, G, 8),

__STM32_PIN_DEFAULT,

__STM32_PIN_DEFAULT,

__STM32_PIN(96, AHB1, C, 6),

__STM32_PIN(97, AHB1, C, 7),

__STM32_PIN(98, AHB1, C, 8),

__STM32_PIN(99, AHB1, C, 9),

__STM32_PIN(100, AHB1, A, 8),

__STM32_PIN(101, AHB1, A, 9),

__STM32_PIN(102, AHB1, A, 10),

__STM32_PIN(103, AHB1, A, 11),

__STM32_PIN(104, AHB1, A, 12),

__STM32_PIN(105, AHB1, A, 13),

__STM32_PIN_DEFAULT,

__STM32_PIN_DEFAULT,

__STM32_PIN_DEFAULT,

__STM32_PIN(109, AHB1, A, 14),

__STM32_PIN(110, AHB1, A, 15),

__STM32_PIN(111, AHB1, C, 10),

__STM32_PIN(112, AHB1, C, 11),

__STM32_PIN(113, AHB1, C, 12),

__STM32_PIN(114, AHB1, D, 0),

__STM32_PIN(115, AHB1, D, 1),

__STM32_PIN(116, AHB1, D, 2),

__STM32_PIN(117, AHB1, D, 3),

__STM32_PIN(118, AHB1, D, 4),

__STM32_PIN(119, AHB1, D, 5),

__STM32_PIN_DEFAULT,

__STM32_PIN_DEFAULT,

__STM32_PIN(122, AHB1, D, 6),

__STM32_PIN(123, AHB1, D, 7),

__STM32_PIN(124, AHB1, G, 9),

__STM32_PIN(125, AHB1, G, 10),

__STM32_PIN(126, AHB1, G, 11),

__STM32_PIN(127, AHB1, G, 12),

__STM32_PIN(128, AHB1, G, 13),

__STM32_PIN(129, AHB1, G, 14),

__STM32_PIN_DEFAULT,

__STM32_PIN_DEFAULT,

__STM32_PIN(132, AHB1, G, 15),

__STM32_PIN(133, AHB1, B, 3),

__STM32_PIN(134, AHB1, B, 4),

__STM32_PIN(135, AHB1, B, 5),

__STM32_PIN(136, AHB1, B, 6),

__STM32_PIN(137, AHB1, B, 7),

__STM32_PIN_DEFAULT,

__STM32_PIN(139, AHB1, B, 8),

__STM32_PIN(140, AHB1, B, 9),

__STM32_PIN(141, AHB1, E, 0),

__STM32_PIN(142, AHB1, E, 1),

__STM32_PIN_DEFAULT,

__STM32_PIN_DEFAULT,

#endif

};

struct rt_pin_irq_hdr pin_irq_hdr_tab[] =

{

{-1, 0, RT_NULL, RT_NULL},

{-1, 0, RT_NULL, RT_NULL},

{-1, 0, RT_NULL, RT_NULL},

{-1, 0, RT_NULL, RT_NULL},

{-1, 0, RT_NULL, RT_NULL},

{-1, 0, RT_NULL, RT_NULL},

{-1, 0, RT_NULL, RT_NULL},

{-1, 0, RT_NULL, RT_NULL},

{-1, 0, RT_NULL, RT_NULL},

{-1, 0, RT_NULL, RT_NULL},

{-1, 0, RT_NULL, RT_NULL},

{-1, 0, RT_NULL, RT_NULL},

{-1, 0, RT_NULL, RT_NULL},

{-1, 0, RT_NULL, RT_NULL},

{-1, 0, RT_NULL, RT_NULL},

{-1, 0, RT_NULL, RT_NULL},

};

const struct pin_index *get_pin(uint8_t pin)

{

const struct pin_index *index;

if (pin < ITEM_NUM(pins))

{

index = &pins[pin];

if (index->index == -1)

index = RT_NULL;

}

else

{

index = RT_NULL;

}

return index;

};

void stm32_pin_write(rt_device_t dev, rt_base_t pin, rt_base_t value)

{

const struct pin_index *index;

index = get_pin(pin);

if (index == RT_NULL)

{

return;

}

if (value == PIN_LOW)

{

GPIO_ResetBits(index->gpio, index->pin);

}

else

{

GPIO_SetBits(index->gpio, index->pin);

}

}

int stm32_pin_read(rt_device_t dev, rt_base_t pin)

{

int value;

const struct pin_index *index;

value = PIN_LOW;

index = get_pin(pin);

if (index == RT_NULL)

{

return value;

}

if (GPIO_ReadInputDataBit(index->gpio, index->pin) == Bit_RESET)

{

value = PIN_LOW;

}

else

{

value = PIN_HIGH;

}

return value;

}

void stm32_pin_mode(rt_device_t dev, rt_base_t pin, rt_base_t mode)

{

const struct pin_index *index;

GPIO_InitTypeDef GPIO_InitStructure;

index = get_pin(pin);

if (index == RT_NULL)

{

return;

}

/* GPIO Periph clock enable */

RCC_AHB1PeriphClockCmd(index->rcc, ENABLE);

/* Configure GPIO_InitStructure */

GPIO_InitStructure.GPIO_Pin = index->pin;

GPIO_InitStructure.GPIO_Speed = GPIO_Speed_2MHz;

GPIO_InitStructure.GPIO_PuPd = GPIO_PuPd_NOPULL;

if (mode == PIN_MODE_OUTPUT)

{

/* output setting */

GPIO_InitStructure.GPIO_Mode = GPIO_Mode_OUT;

GPIO_InitStructure.GPIO_OType = GPIO_OType_PP;

}

else if (mode == PIN_MODE_INPUT)

{

/* input setting: not pull. */

GPIO_InitStructure.GPIO_Mode = GPIO_Mode_IN;

GPIO_InitStructure.GPIO_PuPd = GPIO_PuPd_NOPULL;

}

else if (mode == PIN_MODE_INPUT_PULLUP)

{

/* input setting: pull up. */

GPIO_InitStructure.GPIO_Mode = GPIO_Mode_IN;

GPIO_InitStructure.GPIO_PuPd = GPIO_PuPd_UP;

}

else if (mode == PIN_MODE_INPUT_PULLDOWN)

{

/* input setting: pull down. */

GPIO_InitStructure.GPIO_Mode = GPIO_Mode_IN;

GPIO_InitStructure.GPIO_PuPd = GPIO_PuPd_DOWN;

}

else if (mode == PIN_MODE_OUTPUT_OD)

{

/* output setting: open drain */

GPIO_InitStructure.GPIO_Mode = GPIO_Mode_OUT;

GPIO_InitStructure.GPIO_OType = GPIO_OType_OD;

}

else

{

/* error mode */

RT_ASSERT(0);

}

GPIO_Init(index->gpio, &GPIO_InitStructure);

}

rt_inline rt_int32_t bit2bitno(rt_uint32_t bit)

{

int i;

for (i = 0; i < 32; i++)

{

if ((1UL << i) == bit)

{

return i;

}

}

return -1;

}

rt_inline rt_int32_t bitno2bit(rt_uint32_t bitno)

{

if (bitno <= 32)

{

return 1UL << bitno;

}

else

{

return 0;

}

}

static const struct pin_irq *get_pin_irq(uint16_t pin)

{

static struct pin_irq irq;

const struct pin_index *index;

index = get_pin(pin);

if (index == RT_NULL)

{

return RT_NULL;

}

irq.exti_line = index->pin;

irq.pin_source = bit2bitno(index->pin);

irq.port_source = ((uint32_t)index->gpio - GPIOA_BASE) / (GPIOB_BASE - GPIOA_BASE);

switch (irq.pin_source)

{

case 0 : irq.irq_exti_channel = EXTI0_IRQn;break;

case 1 : irq.irq_exti_channel = EXTI1_IRQn;break;

case 2 : irq.irq_exti_channel = EXTI2_IRQn;break;

case 3 : irq.irq_exti_channel = EXTI3_IRQn;break;

case 4 : irq.irq_exti_channel = EXTI4_IRQn;break;

case 5 :

case 6 :

case 7 :

case 8 :

case 9 : irq.irq_exti_channel = EXTI9_5_IRQn;break;

case 10 :

case 11 :

case 12 :

case 13 :

case 14 :

case 15 : irq.irq_exti_channel = EXTI15_10_IRQn;break;

default : return RT_NULL;

}

return &irq;

};

rt_err_t stm32_pin_attach_irq(struct rt_device *device, rt_int32_t pin,

rt_uint32_t mode, void (*hdr)(void *args), void *args)

{

const struct pin_index *index;

rt_base_t level;

rt_int32_t irqindex = -1;

index = get_pin(pin);

if (index == RT_NULL)

{

return -RT_ENOSYS;

}

irqindex = bit2bitno(index->pin);

if (irqindex < 0 || irqindex >= ITEM_NUM(pin_irq_hdr_tab))

{

return -RT_ENOSYS;

}

level = rt_hw_interrupt_disable();

if (pin_irq_hdr_tab[irqindex].pin == pin &&

pin_irq_hdr_tab[irqindex].hdr == hdr &&

pin_irq_hdr_tab[irqindex].mode == mode &&

pin_irq_hdr_tab[irqindex].args == args

)

{

rt_hw_interrupt_enable(level);

return RT_EOK;

}

if (pin_irq_hdr_tab[irqindex].pin != -1)

{

rt_hw_interrupt_enable(level);

return -RT_EBUSY;

}

pin_irq_hdr_tab[irqindex].pin = pin;

//TODO PA1 will overwrite PB1's hdr, using rt_list ?

pin_irq_hdr_tab[irqindex].hdr = hdr;

pin_irq_hdr_tab[irqindex].mode = mode;

pin_irq_hdr_tab[irqindex].args = args;

rt_hw_interrupt_enable(level);

return RT_EOK;

}

rt_err_t stm32_pin_dettach_irq(struct rt_device *device, rt_int32_t pin)

{

const struct pin_index *index;

rt_base_t level;

rt_int32_t irqindex = -1;

index = get_pin(pin);

if (index == RT_NULL)

{

return -RT_ENOSYS;

}

irqindex = bit2bitno(index->pin);

if (irqindex < 0 || irqindex >= ITEM_NUM(pin_irq_hdr_tab))

{

return -RT_ENOSYS;

}

level = rt_hw_interrupt_disable();

if (pin_irq_hdr_tab[irqindex].pin == -1)

{

rt_hw_interrupt_enable(level);

return RT_EOK;

}

pin_irq_hdr_tab[irqindex].pin = -1;

pin_irq_hdr_tab[irqindex].hdr = RT_NULL;

pin_irq_hdr_tab[irqindex].mode = 0;

pin_irq_hdr_tab[irqindex].args = RT_NULL;

rt_hw_interrupt_enable(level);

return RT_EOK;

}

rt_err_t stm32_pin_irq_enable(struct rt_device *device, rt_base_t pin, rt_uint32_t enabled)

{

const struct pin_index *index;

const struct pin_irq *irq;

rt_base_t level;

rt_int32_t irqindex = -1;

NVIC_InitTypeDef NVIC_InitStructure;

EXTI_InitTypeDef EXTI_InitStructure;

index = get_pin(pin);

if (index == RT_NULL)

{

return -RT_ENOSYS;

}

if (enabled == PIN_IRQ_ENABLE)

{

irqindex = bit2bitno(index->pin);

if (irqindex < 0 || irqindex >= ITEM_NUM(pin_irq_hdr_tab))

{

return -RT_ENOSYS;

}

level = rt_hw_interrupt_disable();

if (pin_irq_hdr_tab[irqindex].pin == -1)

{

rt_hw_interrupt_enable(level);

return -RT_ENOSYS;

}

irq = get_pin_irq(pin);

if (irq == RT_NULL)

{

rt_hw_interrupt_enable(level);

return -RT_ENOSYS;

}

/* select the input source pin for the EXTI line */

SYSCFG_EXTILineConfig(irq->port_source, irq->pin_source);

/* select the mode(interrupt, event) and configure the trigger selection */

EXTI_InitStructure.EXTI_Line = irq->exti_line;

EXTI_InitStructure.EXTI_Mode = EXTI_Mode_Interrupt;

switch (pin_irq_hdr_tab[irqindex].mode)

{

case PIN_IRQ_MODE_RISING:

EXTI_InitStructure.EXTI_Trigger = EXTI_Trigger_Rising;

break;

case PIN_IRQ_MODE_FALLING:

EXTI_InitStructure.EXTI_Trigger = EXTI_Trigger_Falling;

break;

case PIN_IRQ_MODE_RISING_FALLING:

EXTI_InitStructure.EXTI_Trigger = EXTI_Trigger_Rising_Falling;

break;

}

EXTI_InitStructure.EXTI_LineCmd = ENABLE;

EXTI_Init(&EXTI_InitStructure);

/* configure NVIC IRQ channel mapped to the EXTI line */

NVIC_InitStructure.NVIC_IRQChannel = irq->irq_exti_channel;

NVIC_InitStructure.NVIC_IRQChannelPreemptionPriority = 2;

NVIC_InitStructure.NVIC_IRQChannelSubPriority = 2;

NVIC_InitStructure.NVIC_IRQChannelCmd = ENABLE;

NVIC_Init(&NVIC_InitStructure);

rt_hw_interrupt_enable(level);

}

else if (enabled == PIN_IRQ_DISABLE)

{

irq = get_pin_irq(index->pin);

if (irq == RT_NULL)

{

return -RT_ENOSYS;

}

EXTI_InitStructure.EXTI_Line = irq->exti_line;

EXTI_InitStructure.EXTI_Mode = EXTI_Mode_Interrupt;

EXTI_InitStructure.EXTI_Trigger = EXTI_Trigger_Rising;

EXTI_InitStructure.EXTI_LineCmd = DISABLE;

EXTI_Init(&EXTI_InitStructure);

}

else

{

return -RT_ENOSYS;

}

return RT_EOK;

}

const static struct rt_pin_ops _stm32_pin_ops =

{

stm32_pin_mode,

stm32_pin_write,

stm32_pin_read,

stm32_pin_attach_irq,

stm32_pin_dettach_irq,

stm32_pin_irq_enable,

};

int stm32_hw_pin_init(void)

{

int result;

/* enable SYSCFG clock for EXTI */

RCC_APB2PeriphClockCmd(RCC_APB2Periph_SYSCFG, ENABLE);

result = rt_device_pin_register("pin", &_stm32_pin_ops, RT_NULL);

return result;

}

INIT_BOARD_EXPORT(stm32_hw_pin_init);

rt_inline void pin_irq_hdr(int irqno)

{

EXTI_ClearITPendingBit(bitno2bit(irqno));

if (pin_irq_hdr_tab[irqno].hdr)

{

pin_irq_hdr_tab[irqno].hdr(pin_irq_hdr_tab[irqno].args);

}

}

void EXTI0_IRQHandler(void)

{

/* enter interrupt */

rt_interrupt_enter();

pin_irq_hdr(0);

/* leave interrupt */

rt_interrupt_leave();

}

void EXTI1_IRQHandler(void)

{

/* enter interrupt */

rt_interrupt_enter();

pin_irq_hdr(1);

/* leave interrupt */

rt_interrupt_leave();

}

void EXTI2_IRQHandler(void)

{

/* enter interrupt */

rt_interrupt_enter();

pin_irq_hdr(2);

/* leave interrupt */

rt_interrupt_leave();

}

void EXTI3_IRQHandler(void)

{

/* enter interrupt */

rt_interrupt_enter();

pin_irq_hdr(3);

/* leave interrupt */

rt_interrupt_leave();

}

void EXTI4_IRQHandler(void)

{

/* enter interrupt */

rt_interrupt_enter();

pin_irq_hdr(4);

/* leave interrupt */

rt_interrupt_leave();

}

void EXTI9_5_IRQHandler(void)

{

/* enter interrupt */

rt_interrupt_enter();

if (EXTI_GetITStatus(EXTI_Line5) != RESET)

{

pin_irq_hdr(5);

}

if (EXTI_GetITStatus(EXTI_Line6) != RESET)

{

pin_irq_hdr(6);

}

if (EXTI_GetITStatus(EXTI_Line7) != RESET)

{

pin_irq_hdr(7);

}

if (EXTI_GetITStatus(EXTI_Line8) != RESET)

{

pin_irq_hdr(8);

}

if (EXTI_GetITStatus(EXTI_Line9) != RESET)

{

pin_irq_hdr(9);

}

/* leave interrupt */

rt_interrupt_leave();

}

void EXTI15_10_IRQHandler(void)

{

/* enter interrupt */

rt_interrupt_enter();

if (EXTI_GetITStatus(EXTI_Line10) != RESET)

{

pin_irq_hdr(10);

}

if (EXTI_GetITStatus(EXTI_Line11) != RESET)

{

pin_irq_hdr(11);

}

if (EXTI_GetITStatus(EXTI_Line12) != RESET)

{

pin_irq_hdr(12);

}

if (EXTI_GetITStatus(EXTI_Line13) != RESET)

{

pin_irq_hdr(13);

}

if (EXTI_GetITStatus(EXTI_Line14) != RESET)

{

pin_irq_hdr(14);

}

if (EXTI_GetITStatus(EXTI_Line15) != RESET)

{

pin_irq_hdr(15);

}

/* leave interrupt */

rt_interrupt_leave();

}

#endif

#include "multi_button.h"

#define EVENT_CB(ev) if(handle->cb[ev]) handle->cb[ev]((button*)handle)

static struct button* head_handle = NULL;

/**

* @brief Initializes the button struct handle.

* @param handle: the button handle strcut.

* @param pin_level: read the pin of the connet button level.

* @param active_level: pin pressed level.

* @retval None

*/

void button_init(struct button* handle, uint8_t(*pin_level)(void), uint8_t active_level)

{

memset(handle, 0, sizeof(struct button));

handle->event = (uint8_t)NONE_PRESS;

handle->hal_button_Level = pin_level;

handle->button_level = handle->hal_button_Level();

handle->active_level = active_level;

}

/**

* @brief Attach the button event callback function.

* @param handle: the button handle strcut.

* @param event: trigger event type.

* @param cb: callback function.

* @retval None

*/

void button_attach(struct button* handle, PressEvent event, BtnCallback cb)

{

handle->cb[event] = cb;

}

/**

* @brief Inquire the button event happen.

* @param handle: the button handle strcut.

* @retval button event.

*/

PressEvent get_button_event(struct button* handle)

{

return (PressEvent)(handle->event);

}

/**

* @brief button driver core function, driver state machine.

* @param handle: the button handle strcut.

* @retval None

*/

void button_handler(struct button* handle)

{

uint8_t read_gpio_level = handle->hal_button_Level();

//ticks counter working..

if((handle->state) > 0)

{

handle->ticks++;

}

/*------------button debounce handle---------------*/

if(read_gpio_level != handle->button_level)

{

//not equal to prev one

//continue read 3 times same new level change

if(++(handle->debounce_cnt) >= DEBOUNCE_TICKS)

{

handle->button_level = read_gpio_level;

handle->debounce_cnt = 0;

}

}

else

{

// leved not change ,counter reset.

handle->debounce_cnt = 0;

}

/*-----------------State machine-------------------*/

switch (handle->state)

{

case 0:

if(handle->button_level == handle->active_level)

{

handle->event = (uint8_t)PRESS_DOWN;

EVENT_CB(PRESS_DOWN);

handle->ticks = 0;

handle->repeat = 1;

handle->state = 1;

}

else

{

handle->event = (uint8_t)NONE_PRESS;

}

break;

case 1:

if(handle->button_level != handle->active_level)

{

handle->event = (uint8_t)PRESS_UP;

EVENT_CB(PRESS_UP);

handle->ticks = 0;

handle->state = 2;

}

else if(handle->ticks > LONG_TICKS)

{

handle->event = (uint8_t)LONG_RRESS_START;

EVENT_CB(LONG_RRESS_START);

handle->state = 5;

}

break;

case 2:

if(handle->button_level == handle->active_level)

{

handle->event = (uint8_t)PRESS_DOWN;

EVENT_CB(PRESS_DOWN);

handle->repeat++;

handle->event = (uint8_t)PRESS_REPEAT;

EVENT_CB(PRESS_REPEAT);

handle->ticks = 0;

handle->state = 3;

}

else if(handle->ticks > SHORT_TICKS)

{

if(handle->repeat == 1)

{

handle->event = (uint8_t)SINGLE_CLICK;

EVENT_CB(SINGLE_CLICK);

}

else if(handle->repeat == 2)

{

handle->event = (uint8_t)DOUBLE_CLICK;

EVENT_CB(DOUBLE_CLICK);

}

handle->state = 0;

}

break;

case 3:

if(handle->button_level != handle->active_level)

{

handle->event = (uint8_t)PRESS_UP;

EVENT_CB(PRESS_UP);

if(handle->ticks < SHORT_TICKS)

{

handle->ticks = 0;

handle->state = 2;

}

else

{

handle->state = 0;

}

}

break;

case 5:

if(handle->button_level == handle->active_level)

{

handle->event = (uint8_t)LONG_PRESS_HOLD;

if (handle->ticks % LONG_HOLD_CYC == 0)

{

EVENT_CB(LONG_PRESS_HOLD);

}

}

else

{

handle->event = (uint8_t)PRESS_UP;

EVENT_CB(PRESS_UP);

handle->state = 0;

}

break;

}

}

/**

* @brief Start the button work, add the handle into work list.

* @param handle: target handle strcut.

* @retval 0: succeed. -1: already exist.

*/

int button_start(struct button* handle)

{

struct button* target = head_handle;

while(target)

{

if(target == handle)

{

return -1; //already exist.

}

target = target->next;

}

handle->next = head_handle;

head_handle = handle;

return 0;

}

/**

* @brief Stop the button work, remove the handle off work list.

* @param handle: target handle strcut.

* @retval None

*/

void button_stop(struct button* handle)

{

struct button** curr;

for(curr = &head_handle; *curr;)

{

struct button* entry = *curr;

if (entry == handle)

{

*curr = entry->next;

}

else

{

curr = &entry->next;

}

}

}

/**

* @brief background ticks, timer repeat invoking interval 5ms.

* @param None.

* @retval None

*/

void button_ticks(void)

{

struct button* target;

for(target = head_handle; target != NULL; target = target->next)

{

button_handler(target);

}

}

#include "drv_usart.h"

#include "board.h"

#include <rtdevice.h>

/* UART GPIO define. */

#define UART1_GPIO_TX GPIO_Pin_9

#define UART1_TX_PIN_SOURCE GPIO_PinSource9

#define UART1_GPIO_RX GPIO_Pin_10

#define UART1_RX_PIN_SOURCE GPIO_PinSource10

#define UART1_GPIO GPIOA

#define UART1_GPIO_RCC RCC_AHB1Periph_GPIOA

#define RCC_APBPeriph_UART1 RCC_APB2Periph_USART1

#define UART2_GPIO_TX GPIO_Pin_2

#define UART2_TX_PIN_SOURCE GPIO_PinSource2

#define UART2_GPIO_RX GPIO_Pin_3

#define UART2_RX_PIN_SOURCE GPIO_PinSource3

#define UART2_GPIO GPIOA

#define UART2_GPIO_RCC RCC_AHB1Periph_GPIOA

#define RCC_APBPeriph_UART2 RCC_APB1Periph_USART2

#define UART3_GPIO_TX GPIO_Pin_10

#define UART3_TX_PIN_SOURCE GPIO_PinSource10

#define UART3_GPIO_RX GPIO_Pin_11

#define UART3_RX_PIN_SOURCE GPIO_PinSource11

#define UART3_GPIO GPIOB

#define UART3_GPIO_RCC RCC_AHB1Periph_GPIOB

#define RCC_APBPeriph_UART3 RCC_APB1Periph_USART3

#define UART4_GPIO_TX GPIO_Pin_10

#define UART4_TX_PIN_SOURCE GPIO_PinSource10

#define UART4_GPIO_RX GPIO_Pin_11

#define UART4_RX_PIN_SOURCE GPIO_PinSource11

#define UART4_GPIO GPIOC

#define UART4_GPIO_RCC RCC_AHB1Periph_GPIOC

#define RCC_APBPeriph_UART4 RCC_APB1Periph_UART4

#define UART5_GPIO_TX GPIO_Pin_12

#define UART5_TX_PIN_SOURCE GPIO_PinSource12

#define UART5_GPIO_RX GPIO_Pin_2

#define UART5_RX_PIN_SOURCE GPIO_PinSource2

#define UART5_TX GPIOC

#define UART5_RX GPIOD

#define UART5_GPIO_RCC_TX RCC_AHB1Periph_GPIOC

#define UART5_GPIO_RCC_RX RCC_AHB1Periph_GPIOD

#define RCC_APBPeriph_UART5 RCC_APB1Periph_UART5

/* STM32 uart driver */

struct stm32_uart

{

USART_TypeDef *uart_device;

IRQn_Type irq;

struct stm32_uart_dma

{

/* dma stream */

DMA_Stream_TypeDef *rx_stream;

/* dma channel */

uint32_t rx_ch;

/* dma flag */

uint32_t rx_flag;

/* dma irq channel */

uint8_t rx_irq_ch;

/* setting receive len */

rt_size_t setting_recv_len;

/* last receive index */

rt_size_t last_recv_index;

} dma;

};

static void DMA_Configuration(struct rt_serial_device *serial);

static rt_err_t stm32_configure(struct rt_serial_device *serial, struct serial_configure *cfg)

{

struct stm32_uart* uart;

USART_InitTypeDef USART_InitStructure;

RT_ASSERT(serial != RT_NULL);

RT_ASSERT(cfg != RT_NULL);

uart = (struct stm32_uart *)serial->parent.user_data;

USART_InitStructure.USART_BaudRate = cfg->baud_rate;

if (cfg->data_bits == DATA_BITS_8){

USART_InitStructure.USART_WordLength = USART_WordLength_8b;

} else if (cfg->data_bits == DATA_BITS_9) {

USART_InitStructure.USART_WordLength = USART_WordLength_9b;

}

if (cfg->stop_bits == STOP_BITS_1){

USART_InitStructure.USART_StopBits = USART_StopBits_1;

} else if (cfg->stop_bits == STOP_BITS_2){

USART_InitStructure.USART_StopBits = USART_StopBits_2;

}

if (cfg->parity == PARITY_NONE){

USART_InitStructure.USART_Parity = USART_Parity_No;

} else if (cfg->parity == PARITY_ODD) {

USART_InitStructure.USART_Parity = USART_Parity_Odd;

} else if (cfg->parity == PARITY_EVEN) {

USART_InitStructure.USART_Parity = USART_Parity_Even;

}

USART_InitStructure.USART_HardwareFlowControl = USART_HardwareFlowControl_None;

USART_InitStructure.USART_Mode = USART_Mode_Rx | USART_Mode_Tx;

USART_Init(uart->uart_device, &USART_InitStructure);

/* Enable USART */

USART_Cmd(uart->uart_device, ENABLE);

return RT_EOK;

}

static rt_err_t stm32_control(struct rt_serial_device *serial, int cmd, void *arg)

{

struct stm32_uart* uart;

rt_uint32_t ctrl_arg = (rt_uint32_t)(arg);

RT_ASSERT(serial != RT_NULL);

uart = (struct stm32_uart *)serial->parent.user_data;

switch (cmd)

{

/* disable interrupt */

case RT_DEVICE_CTRL_CLR_INT:

/* disable rx irq */

UART_DISABLE_IRQ(uart->irq);

if (ctrl_arg == RT_DEVICE_FLAG_INT_RX){

/* disable interrupt */

USART_ITConfig(uart->uart_device, USART_IT_RXNE, DISABLE);

}

break;

/* enable interrupt */

case RT_DEVICE_CTRL_SET_INT:

/* enable rx irq */

UART_ENABLE_IRQ(uart->irq);

if (ctrl_arg == RT_DEVICE_FLAG_INT_RX){

/* enable interrupt */

USART_ITConfig(uart->uart_device, USART_IT_RXNE, ENABLE);

}

break;

/* USART config */

case RT_DEVICE_CTRL_CONFIG :

if (ctrl_arg == RT_DEVICE_FLAG_DMA_RX) {

uart->dma.last_recv_index = 0;

uart->dma.setting_recv_len = 0;

DMA_Configuration(serial);

/* enable rx irq */

UART_ENABLE_IRQ(uart->irq);

}

break;

}

return RT_EOK;

}

static int stm32_putc(struct rt_serial_device *serial, char c)

{

struct stm32_uart *uart;

RT_ASSERT(serial != RT_NULL);

uart = (struct stm32_uart *)serial->parent.user_data;

while (!(uart->uart_device->SR & USART_FLAG_TXE));

uart->uart_device->DR = c;

return 1;

}

static int stm32_getc(struct rt_serial_device *serial)

{

int ch;

struct stm32_uart *uart;

RT_ASSERT(serial != RT_NULL);

uart = (struct stm32_uart *)serial->parent.user_data;

ch = -1;

if (uart->uart_device->SR & USART_FLAG_RXNE)

{

ch = uart->uart_device->DR & 0xff;

}

return ch;

}

/**

* DMA initialize by DMA_InitStruct structure

*

* @param serial serial device

* @param setting_recv_len setting receive length

* @param mem_base_addr memory 0 base address for DMA stream

*/

static void dma_uart_config(struct rt_serial_device *serial, uint32_t setting_recv_len,

void *mem_base_addr)

{

struct stm32_uart *uart = (struct stm32_uart *) serial->parent.user_data;

DMA_InitTypeDef DMA_InitStructure;

/* rx dma config */

uart->dma.setting_recv_len = setting_recv_len;

DMA_DeInit(uart->dma.rx_stream);

while (DMA_GetCmdStatus(uart->dma.rx_stream) != DISABLE);

DMA_InitStructure.DMA_Channel = uart->dma.rx_ch;

DMA_InitStructure.DMA_PeripheralBaseAddr = (uint32_t) &(uart->uart_device->DR);

DMA_InitStructure.DMA_Memory0BaseAddr = (uint32_t)mem_base_addr;

DMA_InitStructure.DMA_DIR = DMA_DIR_PeripheralToMemory;

DMA_InitStructure.DMA_BufferSize = uart->dma.setting_recv_len;

DMA_InitStructure.DMA_PeripheralInc = DMA_PeripheralInc_Disable;

DMA_InitStructure.DMA_MemoryInc = DMA_MemoryInc_Enable;

DMA_InitStructure.DMA_PeripheralDataSize = DMA_PeripheralDataSize_Byte;

DMA_InitStructure.DMA_MemoryDataSize = DMA_PeripheralDataSize_Byte;

DMA_InitStructure.DMA_Mode = DMA_Mode_Circular;

DMA_InitStructure.DMA_Priority = DMA_Priority_High;

DMA_InitStructure.DMA_FIFOMode = DMA_FIFOMode_Disable;

DMA_InitStructure.DMA_FIFOThreshold = DMA_FIFOThreshold_Full;

DMA_InitStructure.DMA_MemoryBurst = DMA_MemoryBurst_Single;

DMA_InitStructure.DMA_PeripheralBurst = DMA_PeripheralBurst_Single;

DMA_Init(uart->dma.rx_stream, &DMA_InitStructure);

}

/**

* Serial port receive idle process. This need add to uart idle ISR.

*

* @param serial serial device

*/

static void dma_uart_rx_idle_isr(struct rt_serial_device *serial) {

struct stm32_uart *uart = (struct stm32_uart *) serial->parent.user_data;

rt_size_t recv_total_index, recv_len;

rt_base_t level;

/* disable interrupt */

level = rt_hw_interrupt_disable();

recv_total_index = uart->dma.setting_recv_len - DMA_GetCurrDataCounter(uart->dma.rx_stream);

recv_len = recv_total_index - uart->dma.last_recv_index;

uart->dma.last_recv_index = recv_total_index;

/* enable interrupt */

rt_hw_interrupt_enable(level);

if (recv_len) rt_hw_serial_isr(serial, RT_SERIAL_EVENT_RX_DMADONE | (recv_len << 8));

/* read a data for clear receive idle interrupt flag */

USART_ReceiveData(uart->uart_device);

}

/**

* DMA receive done process. This need add to DMA receive done ISR.

*

* @param serial serial device

*/

static void dma_rx_done_isr(struct rt_serial_device *serial)

{

struct stm32_uart *uart = (struct stm32_uart *) serial->parent.user_data;

rt_size_t recv_len;

rt_base_t level;

if (DMA_GetFlagStatus(uart->dma.rx_stream, uart->dma.rx_flag) != RESET)

{

/* disable interrupt */

level = rt_hw_interrupt_disable();

recv_len = uart->dma.setting_recv_len - uart->dma.last_recv_index;

/* reset last recv index */

uart->dma.last_recv_index = 0;

/* enable interrupt */

rt_hw_interrupt_enable(level);

if (recv_len) rt_hw_serial_isr(serial, RT_SERIAL_EVENT_RX_DMADONE | (recv_len << 8));

/* start receive data */

DMA_ClearFlag(uart->dma.rx_stream, uart->dma.rx_flag);

}

}

/**

* Uart common interrupt process. This need add to uart ISR.

*

* @param serial serial device

*/

static void uart_isr(struct rt_serial_device *serial)

{

struct stm32_uart *uart = (struct stm32_uart *) serial->parent.user_data;

RT_ASSERT(uart != RT_NULL);

if(USART_GetITStatus(uart->uart_device, USART_IT_RXNE) != RESET)

{

rt_hw_serial_isr(serial, RT_SERIAL_EVENT_RX_IND);

/* clear interrupt */

USART_ClearITPendingBit(uart->uart_device, USART_IT_RXNE);

}

if(USART_GetITStatus(uart->uart_device, USART_IT_IDLE) != RESET)

{

dma_uart_rx_idle_isr(serial);

}

if (USART_GetITStatus(uart->uart_device, USART_IT_TC) != RESET)

{

/* clear interrupt */

USART_ClearITPendingBit(uart->uart_device, USART_IT_TC);

}

if (USART_GetFlagStatus(uart->uart_device, USART_FLAG_ORE) == SET)

{

stm32_getc(serial);

}

}

static const struct rt_uart_ops stm32_uart_ops =

{

stm32_configure,

stm32_control,

stm32_putc,

stm32_getc,

};

#if defined(RT_USING_UART1)

/* UART1 device driver structure */

struct stm32_uart uart1 =

{

USART1,

USART1_IRQn,

{

DMA2_Stream5,

DMA_Channel_4,

DMA_FLAG_TCIF5,

DMA2_Stream5_IRQn,

0,

},

};

struct rt_serial_device serial1;

void USART1_IRQHandler(void)

{

/* enter interrupt */

rt_interrupt_enter();

uart_isr(&serial1);

/* leave interrupt */

rt_interrupt_leave();

}

void DMA2_Stream5_IRQHandler(void) {

/* enter interrupt */

rt_interrupt_enter();

dma_rx_done_isr(&serial1);

/* leave interrupt */

rt_interrupt_leave();

}

#endif /* RT_USING_UART1 */

#if defined(RT_USING_UART2)

/* UART2 device driver structure */

struct stm32_uart uart2 =

{

USART2,

USART2_IRQn,

{

DMA1_Stream5,

DMA_Channel_4,

DMA_FLAG_TCIF5,

DMA1_Stream5_IRQn,

0,

0,

},

};

struct rt_serial_device serial2;

void USART2_IRQHandler(void)

{

/* enter interrupt */

rt_interrupt_enter();

uart_isr(&serial2);

/* leave interrupt */

rt_interrupt_leave();

}

void DMA1_Stream5_IRQHandler(void) {

/* enter interrupt */

rt_interrupt_enter();

dma_rx_done_isr(&serial2);

/* leave interrupt */

rt_interrupt_leave();

}

#endif /* RT_USING_UART2 */

#if defined(RT_USING_UART3)

/* UART3 device driver structure */

struct stm32_uart uart3 =

{

USART3,

USART3_IRQn,

{

DMA1_Stream1,

DMA_Channel_4,

DMA_FLAG_TCIF1,

DMA1_Stream1_IRQn,

0,

0,

},

};

struct rt_serial_device serial3;

void USART3_IRQHandler(void)

{

/* enter interrupt */

rt_interrupt_enter();

uart_isr(&serial3);

/* leave interrupt */

rt_interrupt_leave();

}
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

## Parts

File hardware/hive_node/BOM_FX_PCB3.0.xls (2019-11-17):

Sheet: BOM Report
Bill of Materials |  | Bill of Materials For PCB Document [FX_PCB3.0.PcbDoc]
Source Data From:
Project:
Variant:
Creation Date: | 2018/12/25
Print Date: | 2018-12-26
Footprint | Comment | Designator | 备注： | Description | Quantity
两脚贴片按键 | WiFi-复位按键 | K5 |  | 轻触开关 | 1
两脚贴片按键 | 复位按键 | K1 |  | 轻触开关 | 1
BUZZER-8mm | 蜂鸣器 | U20 |  | 蜂鸣器 | 1
继电器F3AA005E | 继电器-005VDC | J1, J2 | 富士通 直流5V驱动 一组常开 | 继电器 | 2
0805R | 0Ω | R2, R18, R19 | RES SMD 0 OHM 1％ 1 / 16W 0805 | 电阻 | 3
0805R | 10K | R1, R1_2, R4, R5, R12, R13, R14, R15 | RES SMD 10K OHM 1％ 1 / 16W 0805 | 电阻 | 8
0805R | 1K | R6, R7, R22, R23, R26, R29 | RES SMD 1K OHM 1％ 1 / 16W 0805 | 电阻 | 6
0805R | 1M | R9 | RES SMD 1M OHM 1％ 1 / 16W 0805 | 电阻 | 1
0805R | 20K | R24, R27 | RES SMD 20K OHM 1％ 1 / 16W 0805 | 电阻 | 2
0805R | 4.7K | R17, R20, R21, R33 | RES SMD 4.7K OHM 1％ 1 / 16W 0805 | 电阻 | 4
0805R | 47K | R3 | RES SMD 47K OHM 1％ 1 / 16W 0805 | 电阻 | 1
0805R | 5M | R8 | RES SMD 5M OHM 1％ 1 / 16W 0805 | 电阻 | 1
0805R | 8.2K | R25, R28 | RES SMD 8.2K OHM 1％ 1 / 16W 0805 | 电阻 | 2
SOT-223 | AMS1117-3.3V | U2 | AMS1117-3.3V | 电源芯片 | 1
DC-012 | DC-012 | POWER1 |  | 电源插孔 | 1
贴片电感7*7*4 | 100uH | L1, L1_2 | CDRH74R 7*7*4MM 最大峰值电流: 2.5-3A | 电感 | 2
TAJ-D | 100uF/25V | C3 |  | 极性贴片电容 | 1
TAJ-D | 100uF/25V | C1, C1_2, C3_2 |  | 极性贴片电容 | 3
TAJ-A | 47uF/16V | C6, C8 |  | 极性贴片电容 | 2
0805C | 103/16V | C5, C5_2 |  | 无极贴片电容 | 2
0805C | 104/16V | C2, C2_2, C4, C4_2, C7, C9, C11, C12, C13, C14, C15, C16, C17, C18, C19, C20, C21, C23, C24, C25, C26, C27, C28, C29, C30, C31 |  | 无极贴片电容 | 26
0805C | 226/16V | C10, C22 |  | 无极贴片电容 | 2
TO-92 | DS18B20 | U10 |  | 数字温度传感器 | 1
排阻(4位贴片) | 1K | R16, R34,R35 |  | 排阻 | 3
Header 2 | GND | P17, P18 |  | 排针 | 2
Header 6 | OLED | P13 |  | 排针 | 1
Header 4 | SWD调试接口 | P2 |  | 排针 | 1
钮子开关(大) | 钮子开关 | S1 |  | 大功率开关 | 1
SW_PB4_DIP | PA12 | K4 |  | 四脚按键 | 1
SW_PB4_DIP | PB10 | K3 |  | 四脚按键 | 1
SW_PB4_DIP | PB2 | K2 |  | 四脚按键 | 1
0805LED | (LED绿) | LED6 |  | 发光二极管 | 1
0805LED | (LED蓝) | LED5 |  | 发光二极管 | 1
0805LED | (LED绿) | LED7 |  | 发光二极管 | 1
0805LED | (LED红) | LED3 |  | 发光二极管 | 1
0805LED | (LED绿) | LED0, LED1 |  | 发光二极管 | 2
0805LED | (LED蓝) | LED2 |  | 发光二极管 | 1
Header 3X2 | 电源预留排针 | P15 |  | 双排排针 | 1
1812 | 保险丝T300 | F1, F1_2 | TLC-MSMD300 1812 3A 12V | 保险丝 | 2
SMBJ | SMBJ3.3A (KC) | D6 | SMBJ3.3A (KC) 单向瞬变抑制器 | 二极管 | 1
SMBJ | SMBJ5.0A (KE) | D5 | SMBJ5.0A (KE) 单向瞬变抑制器 | 二极管 | 1
SMA/DO-214AC | SS14 | D3, D4 |  | 二极管 | 2
SMA/DO-214AC | SS34 | D1, D1_2, D2, D2_2 |  | 二极管 | 4
排母2.0MM-10PIN | 排母2.0MM-10PIN | U9 | WIFI模块无需买，只接底座 | WIFI模块底座 | 1
QFN-28 | CP2102 | U6 |  | USB转串口芯片 | 1
Micro-USB (直插固定脚) | micro-USB | U5 |  | USB接口 | 1
SOT-23 | S8550 | Q5, Q6 |  | PNP | 2
TO-263 | IRF4905 | MOS1, MOS2 |  | PMOS | 2
SOT-23 | S8050 | Q1, Q2, Q3, Q4 |  | NPN三极管 | 4
LQFP-64(GOOD) | STM32F405RGT6V | U0 |  | ARM Cortex-M4 32-bit MCU+FPU, 210 DMIPS, 1024 kB Flash, 192 kB Internal RAM, 51 I/Os, 64-pin LQFP, -40 to 85 degC, Tray | 1
SOP-16 | HX711 | U7, U8 |  | A/D转换器芯片 | 2
TO-263-5 | LM2596-5.0V | U1, U1_1 |  | 正品电源芯片 | 2
拨码开关(4位直插) | 拨码开关 | P35 |  | 4位拨码开关 | 1
接线端子(2.54mm)-3PIN | 流量计接口 | P11 |  | 3PIN | 1
接线端子(2.54mm)-3PIN | 舵机接口 | P12 |  | 3PIN | 1
接线端子(2.54mm)-2PIN | 蜂鸣器接口 | P13 |  | 2PIN | 1
接线端子(5.00mm)-2PIN | DC-012 | POWER2 |  | 接线端子(5.00mm)-2PIN | 1
定位孔 | M3定位孔 | H1, H2, H3, H4 |  | M3定位孔 | 4
三脚贴片8M晶振 | 8M | XTAL1 |  | 贴片陶瓷晶振CSTCC8M00G53-RO 8.000M 8MHZ 3*7 | 1
E10-433MS | E10-433MS | U4 | 成都亿佰特电子科技有限公司 | E10-433MS通信模块 | 1
KF350-18P | KF350-18P | P22 |  | KF350螺钉式接线端子 | 1
SMA-KE | SMA-KE | J3 |  | SMA天线底座 | 1
SOW-8 | W25Q128 | U3 |  | FLASH芯片 | 1
 |  |  |  |  | 133
Approved

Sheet: Project Information
Project Full Path | D:\My\SH\SH_PCB\FX_Project-08(18.12.10)\SH_Project.PrjPcb
Project Filename | SH_Project.PrjPcb
Variant Name | None
Data-Source Filename | FX_PCB3.0.PcbDoc
Data-Source Full Path | C:\Users\zengwangfa\Desktop\FX测试\FX_PCB3.0.PcbDoc
Title | Bill of Materials For PCB Document [FX_PCB3.0.PcbDoc]
Total Quantity | 133
Report Time | 12:21:00
Report Date | 2018/12/19
Report Date & Tine | 2018/12/19 12:21:00
Output Name | Bill of Materials
Output Type | BOM_PartType
Output Generator Name | BOM
Output Generator Description | Bill of Materials

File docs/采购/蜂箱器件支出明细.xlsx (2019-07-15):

智能蜂箱项目支出明细表
器材名称 | 价格（元） |  | 备注 | 日期 | 收入（元）
LORA模块*3 | 118.8 |  | 有发票
应变片*15 | 62
应变片*10 | 46
电子元器件 | 33.59 |  | 有发票
称重传感器 | 38.9
全桥式称重传感器*4 | 35.9
半桥式称重传感器*8 | 12.5
方铝架 | 80
 |  |  |  | 2018.11.10 | 1000
小计 | 427.69
小计剩余 | 1000-427.67=572.33元
蜂箱-蜂巢-称重框CAD设计 | 50
多芯线 | 12.7
PCB板打样 | 88 |  | 有发票
防水盒*2与防水接线头样品 | 51.2
 |  |  |  | 2018.11.25
小计 | 201.9
小计剩余 | 572.33-201.9=370.43元
PCB打板 | 160 |  | 有发票
多芯线 | 12.67
器件器材（元器件） | 329 |  | 有发票
元器件 | 60.2
无线模块E10-433MS | 85.6 |  | 有发票
 |  |  |  | 2018.12.3
小计 | 647.47
小计剩余 | 370.43-715.47= - 345.04元
网关PCB | 48 |  | 有发票 | 2019.1.04
（433M天线、天线底座、 USB插座）*105个 | 294 |  | 有发票 | 2019.1.05
网关器件 | 135 |  | 有发票 | 2019.1.08
小计 | 477
小计剩余 | -345.04-477 = -822.04
DS18B20温度传感器*120 | 563 |  | 有发票 | 2019.1.14
网关电子元器件 | 110.46 |  | 有发票
网关铝外壳*2 | 56
12V3A电源适配器*10 | 228 |  | 有发票
小计剩余 | -822.04 - 957.46 = - 1779.5
主要器件名称 | 单价 | 需要数量
继电器F3AA005E | 2.2 | 2 | 4.4
AMS1117-3.3V | 2 | 1 | 2
DS18B20 | 4 | 1 | 4
IRF4905 | 4.5 | 2 | 9
STM32F405RGT6V | 25 | 1 | 25
HX711 | 2 | 2 | 4
LM2596-5.0V | 1 | 2 | 2
E10-433MS | 16 | 1 | 16
W25Q128 | 3.3 | 1 | 3.3
CP2102 | 5.8 | 1 | 5.8
 |  | 总价： | 75.5

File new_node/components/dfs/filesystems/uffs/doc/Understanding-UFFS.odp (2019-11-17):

## Understanding UFFS

Ricky Zheng

< ricky_gz_zheng@yahoo.co.nz >

Created: March 2007

Last modified: Nov 2011

## Content

- Why UFFS ?
- Design goal
- Flash: NOR vs NAND ?
- What's wrong with FAT ?
- UFFS basic idea
  - Serial number
  - Tree in memory
  - Journalizing
- UFFS architecture
  - UFFS device
  - Mount point
  - UFFS nodes tree
  - Mounting UFFS
  - Page spare/UFFS tags
  - Block info cache
  - UFFS page buffer
  - Block recover
  - Bad block management
  - How ECC works ?
  - Flash interface
- What's next ?
  - UFFS2

## Why UFFS ?

- JFFS/JFFS2
  - Can't go out of Linux/MTD
  - Memory monster
- YAFFS/YAFFS2 still consumes too much RAM
  - 64M FLASH, 500 files ==> 410K RAM
- No open source lightweight flash file system exists yet ...

## UFFS design goal

- Ultra low cost
  - Low memory cost
  - Fast booting
- Superb Stability
  - Constant RAM consumption, support static memory allocation
  - Guaranteed integrity across unexpected power losses
  - Bad block tolerant, ECC and ware leveling
- NAND flash friendly
  - Support small (512B) or large page (up to 4KB) size
  - Support SLC and MLC
  - Support software ECC or hardware ECC / RS-ECC
  - Direct flash interface
- Well Emulated on PC platform, easy for debugging

## Flash: NOR vs NAND

- NOR:
  - Random access for read
  - Big block (minimal erase unit)
  - Byte programing
  - Slow erasing/programing
- NAND:
  - Page/spare access for read
  - Small block
  - Page/spare programing (with limited splits/Restricted rewrite)
  - Fast erasing/programing
  - Delivered with bad blocks

## NAND Flash Basic

Page data

Spare

Block

Erase: '0'->'1', Write/Program: '1'->'0'

## What's wrong with FAT

- Need FTL (which may cost many RAM)
- Big FAT table,slow down the whole system
- Vulnerable when unexpectedly interrupted while updating FAT or File info

FAT

File info

Changes

Write File

Changes

File data

Changes

## UFFS basic idea(1)

Parent

Serial

Parent

Serial

Parent

Serial

Parent

Serial

Parent

Serial

Parent

Serial

Parent

Serial

Parent

Serial

Parent

Serial

- Use unique parent/serial number pair to:
  - Identify blocks
  - Build relationships

ROOT

Parent: 16 bit

Serial: 16 bit

## UFFS basic idea(2)

- Build the relationship tree in memory when mounting UFFS:
  - Erased blocks
  - Bad blocks
  - Hash tables (serial number as key)
    - Dir table
    - File table
    - File data table
- Tree node size: 16 bytes
  - Memory cost: 16 * total_blocks

## UFFS basic idea(3)

- Journalizing
  - Write to a new block/page instead of modify the old one.
  - Use circular time stamp: 00->01->11->00>...
  - Check and correct conflicts while mounting UFFS
  - Using “mini-header” eliminates partial page programing requirement

## UFFS Device

- UFFS Device & Mount Point

extern uffs_Device uffs_rootDev;

extern uffs_Device uffs_dataDev;

static struct uffs_mountTableSt femu_MountTbl[] = {

{&uffs_rootDev, 0, 200, "/"},

{&uffs_dataDev, 201, -1, "/data/"},

{NULL, 0, 0, NULL},

};

“/”

“/data/”

UFFS Device ===> Partition
UFFS Device: individual flash ops, cache/buffer, tree nodes ...

## UFFS node tree

- UFFS nodes tree

UFFS device

Bad blocks

Erased blocks

Dir nodes

File nodes

Data nodes

Hash table, serial as the key

block,next

block,next

block,parent,serial,sum,next

block,parent,serial,sum,length(4),next

block,parent,serial,length(2),next

sizeof(TreeNode) = 16B

## UFFS Mounting

- Mounting UFFS

Step 1:

  - Scan page spares*, classify DIR/FILE/DATA nodes
  - Check bad block
  - Check interrupted writing

Step 2:

  - Randomize erased blocks

Step3:

  - Check DATA nodes,take care orphan nodes

Super fast !

* UFFS only read a few spares (normally one or two) from each block rather then all spares !!

UFFS device

Bad blocks

Erased blocks

Dir nodes

File nodes

Data nodes

## UFFS tags

- Page spare/UFFS tags

struct uffs_TagStoreSt {

u32 dirty:1;

u32 valid:1;

u32 type:2;

u32 block_ts:2;

u32 data_len:12;

u32 serial:14;

u32 parent:10;

u32 page_id:6;

u32 reserved:4;

u32 tag_ecc:12;

};

sizeof(struct uffs_TagStoreSt) = 8, small enough to store on spare area

* Note: if using RS-ECC on small page MLC, then tag may store on page data area

## UFFS block info cache

- UFFS block info cache

struct uffs_pageSpareSt {

u8 expired:1;

uffs_Tags tag;

};

struct uffs_blockInfoSt {

struct uffs_blockInfoSt *next;

struct uffs_blockInfoSt *prev;

u16 blockNum;

struct uffs_pageSpareSt *spares;

int expiredCount;

int refCount;

};

uffs_config.h:

MAX_CACHED_BLOCK_INFO(5 ~10)

Memory: 40 bytes for each cached info

## UFFS page buffer

- UFFS page buffer

struct uffs_BufSt{

struct uffs_BufSt *next;

struct uffs_BufSt *prev;

struct uffs_BufSt *nextDirty;

struct uffs_BufSt *prevDirty;

u8 type;

u8 ext_mark;

u16 parent;

u16 serial;

u16 pageID;

u16 mark;

u16 refCount;

u16 dataLen;

u8 * data;

u8 * header;

};

uffs_config.h:

MAX_PAGE_BUFFERS (10 ~ 40)

Memory: (40 + page_size) each buffer

## UFFS page status

Valid page

Discarded page

Free page

- Free page: no page id assigned yet. Free pages are always on the bottom.
- Valid page: the page with a id and have max page offset
- Discarded page: the page with page id, there are one or more pages have the same id and bigger page offset.
- Unknown status: interrupted while writing a page.

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
## UFFS block status

Valid page

Discarded page

Free page

- Bad block
- Free/Erased block
- Non-full loaded block (have one or more free pages)
- Full loaded block (no free page, page id = physical page offset)

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
Bad block

Free block

Non-full loaded block

13

14

15

Full loaded block

## UFFS block recover(1)

- Block recover happens when:
  - No more free pages available inside the block and
  - Data were modified and/or
  - Flush the buffer
- Block recover steps:
  - (1)Get a free/erased block from erased block list
  - (2)Copy pages from old block, write to new block with newer timestamps
  - (3)Erase the old block
  - (4)Put the old block to erased block list
  - Note: (1) and (4) are operating in memory. (2) and (3) identified by timestamps, all steps allow to be interrupted at any time ! (Guaranteed integrity across unexpected power losses)

## UFFS block recover(2)

- No block recover if there are enough free pages

Block 1234

0

Block 1234

0

1

1

Since there are free pages, no block recover happens.

Mark old page as discarded, and generate a new page.

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
Valid page

Discarded page

Free page

## UFFS block recover(3)

- Recover a non-full loaded block

Block 1234

0

Block 5678

0

1

No more free page available in this block, modify any pages from 0-7, or add a new page 8, will cause block recovering.

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
Valid page

Discarded page

Free page

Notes: See uffs_buf.c: static URET _BufFlush_Exist_With_BlockCover ( uffs_Device *dev, TreeNode *node, uffs_blockInfo *bc )

## UFFS block recover(4)

- Recover a full-loaded block

Block 1234

0

Block 5678

0

Modify any page of full-loaded block will cause block recovering.

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
Valid page

Discarded page

Free page

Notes: See uffs_buf.c: static URET _BufFlush_Exist_With_BlockCover ( uffs_Device *dev, TreeNode *node, uffs_blockInfo *bc )

## UFFS Page layout

Status byte

mini-

header

Seal byte

ECC

DATA

Tag

- Mini-header (4B) and DATA on page data area, Tag, ECC and 'seal byte' on spare area
- In some case (for example, when using hardware RS-ECC on small page MLC), you can treat the whole NAND page as one body, blur the page data and spare area boundary.
- The 'status byte': this is the first byte of mini-header. If status byte is not 0xFF – this page is “dirty”, page program already started.
- The 'seal byte': this is the last byte of spare data. If seal byte is not 0xFF – this page is “sealed”, all data and tag/ECC have been programmed successfully.

## UFFS bad block management

- Bad block discover when mounting UFFS
- Bad block discover when read/write/erase
  - Try ECC error correct
  - If ECC fail, there is no way get valid data
  - Do not process bad block immediately, leave it at the end of Read/Write operation.
  - Only handle one bad block during the one read/write operation.
- Check bad block when formating UFFS

## How ECC works ? (1)

- XOR: A ^ B = C
  - 0 ^ 0 = 0
  - 1 ^ 0 = 1
  - 0 ^ 1 = 1
  - 1 ^ 1 = 0
- Knowing any two of A, B and C, will know the rest one.
- UFFS ECC: 3 bytes ECC for 256 bytes data
  - 256 Bytes ==> 2048 Bits ===> 256(row) X 8(col)

## How ECC works ? (2)

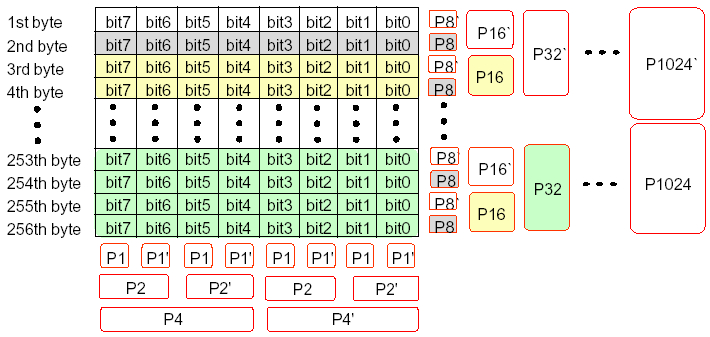
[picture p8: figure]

## UFFS Flash Interface

- struct uffs_FlashOpsSt:
  - Use hardware ECC, or leave it to UFFS
  - Allow driver do the spare layout, or leave it to UFFS
  - Return flash operation status
  - Sequential page programing. No partial page programing.

## UFFS Limitations

- Only one file/dir on one block
- Dynamic wear-leveling, Static wear-leveling is not implemented.

## The next: UFFS2 ?

- Smaller Tree Node (12 bytes), save 25% RAM
- Use NAND block as buffers
- Multiple files/dirs on one block
- Support 8K, 16K page size
- Static wear-leveling
- Symbol link, FIFO file ?
- NOR flash support ? Maybe ...

## The End

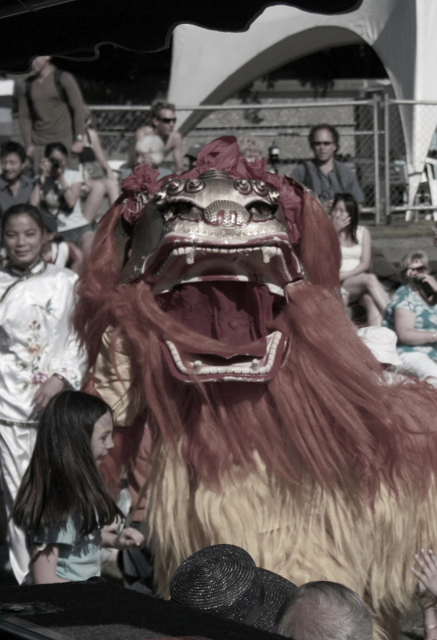
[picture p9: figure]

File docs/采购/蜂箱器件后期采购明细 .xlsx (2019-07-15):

智能蜂箱项目后期采购支出明细表
名称 | 价格（元） | 备注 | 日期
阿里云服务器 | 114元/年 | 系统镜像：centos
防水盒+PG防水接头 | 9.5/个 | 盒面喷绘信息
16 芯 多芯线 | 8.06元/米

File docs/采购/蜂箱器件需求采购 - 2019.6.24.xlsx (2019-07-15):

智能蜂箱项目后期采购支出明细表
名称 | 大概价格（元） | 备注 | 参考淘宝链接
防水盒（带4个螺丝、1条密封条） | 9.5元/套 | 同侧开孔2个，开孔具体要求见“开孔要求.png” | https://item.taobao.com/item.htm?spm=a1z09.2.0.0.3c752e8dS8cYuv&id=39533965452&_u=o1v2ldgsc4a7
PG 11防水接头 400个 | 0.5元/个 |  | https://item.taobao.com/item.htm?id=39779518842&spm=2014.21600712.0.0
国标8芯线 0.3平方 200米 | 2.5元/米 |  | https://item.taobao.com/item.htm?id=547341392721&last_time=1561381096
国标8芯线 0.5平方 200米 | 3.9元/米 |  | https://item.taobao.com/item.htm?id=547341392721&last_time=1561381096
12V 电源适配器
原装正品 DS18B20+ 可编程数字温度器 | 4元/个 |  | https://item.taobao.com/item.htm?spm=a1z09.2.0.0.3c752e8dS8cYuv&id=522575988442&_u=o1v2ldgs831c
SI4463无线模块433M | 14元/PCS |  | https://item.taobao.com/item.htm?spm=a1z09.2.0.0.3c752e8dS8cYuv&id=35422295797&_u=o1v2ldgsdd58
天线座SMA-KE 直头正脚型 外螺内孔 直插 | 0.73元/个 |  | https://item.taobao.com/item.htm?spm=a1z0d.7625083.1998302264.6.5c5f4e69QDpE9W&id=535391330089
433mhz小辣椒天线 | 2元/个 |  | https://item.taobao.com/item.htm?spm=a1z09.2.0.0.3c752e8dS8cYuv&id=573999240350&_u=o1v2ldgsbba7

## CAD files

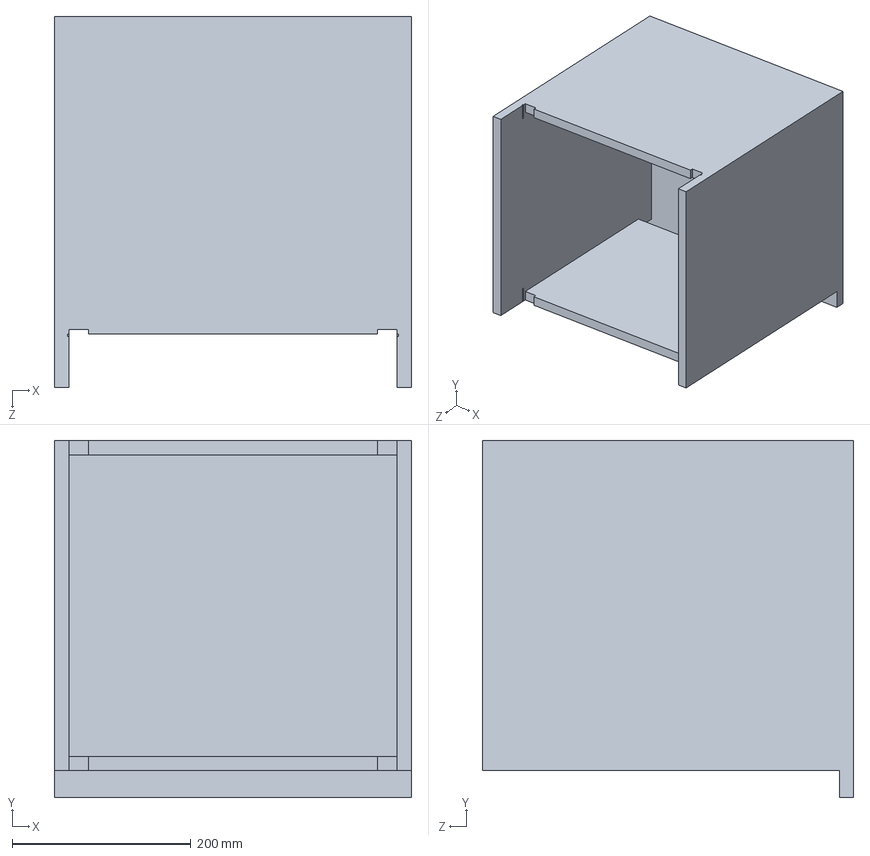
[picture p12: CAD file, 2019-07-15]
docs/设计文档/称重结构设计/蜂箱3D立体视图.SLDPRT
400.0 x 400.0 x 416.0 mm

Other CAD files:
docs/设计文档/称重结构设计/3.1.1半桥式传感器.dwg
docs/设计文档/称重结构设计/3.1.2蜂箱三视图.dwg
docs/设计文档/称重结构设计/3.1.3称重方铝框.dwg
docs/设计文档/称重结构设计/蜂箱-蜂巢-称重框结构及参数CAD.dwg
docs/设计文档/称重结构设计/3.1.4片形蜂巢.dwg

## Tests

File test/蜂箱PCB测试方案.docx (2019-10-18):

蜂箱PCB测试方案

注：带有“【】”其括号中的内容为PCB板上的器件标识编号

测试步骤：

1． 在SWD下载接口，连接SWD下载器，烧写测试程序；
2． 在板上OLED接口（6PIN排母），插入0.96寸OELD显示屏（注：OLED仅为测试时使用）；
3． 接入12V电源后；
4． 上电1s后 听到持续间隔为0.5秒 的 继电器吸合声音，

1秒后两个继电器关闭，以此反复即表示继电器模块正常；

先响应的为继电器【J1】，后响应的为继电器【J2】

5． 最侧边KF350螺钉式接线端子P14、P15引脚各插入一直插LED（耐压值为5V）的正极，负极接统一插入P18引脚。

上电后立即 看到两个间隔为0.5秒的 LED被点亮，而后即表示MOS管无故障。（14、15引脚上下顺序对应MOS管的上下顺序，即位置一一对应）

即先点亮的为【MOS1】响应，后点亮的为【MOS2】响应

6． 在OLED(母排插)接入0.96寸OELD显示屏。

上电后 在屏幕上看到如下图状态，即各个模块无故障

    - （第一行）FLASH：若显示“OK”即正常

若显示“Error”，则【U3】W25Q128 模块电路有异常

    - （第二行）温度：若显示“OK”即正常

若显示“Error”，则【U1】DS18B20 模块电路有异常

- （第二行）电压：若显示“OK”即正常

若显示“Error”，则分压电路中电阻【R8、R9】有异常

- （第三、四行）两组重量：若显示“OK”即正常

若显示“Error”，则 HX711模块电路有异常（重量1对应芯片【U7】，重量2对应芯片【U8】）

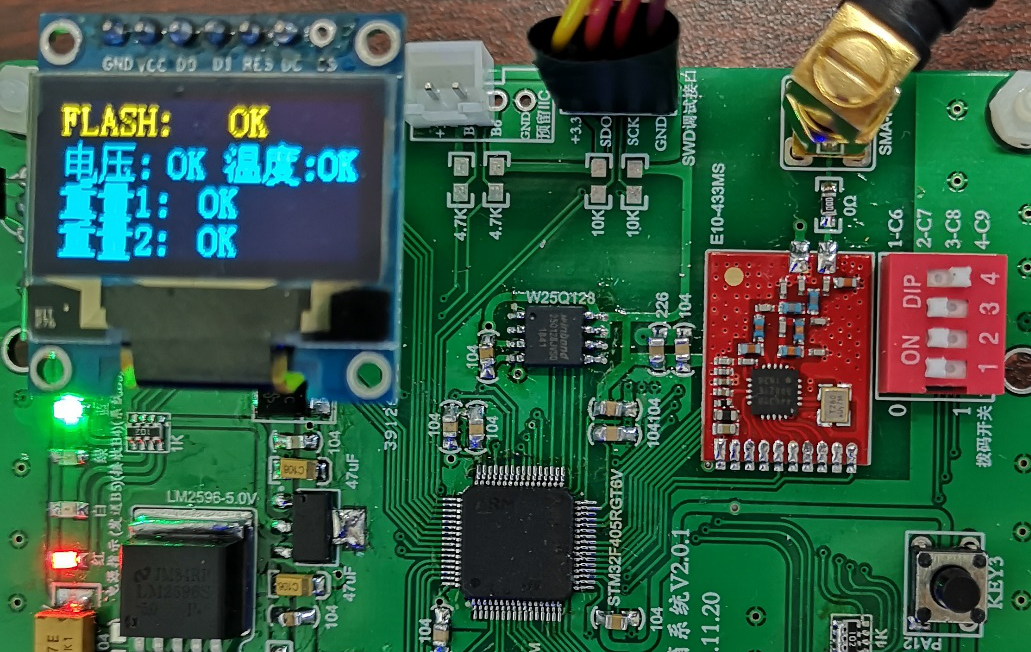
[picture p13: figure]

若以上各个模块都为所要求正常响应或显示，即总体电路测试成功。

注：FX_PCB文件与实物样板 局部有一些小差异，若有差异处按PCB文件为准。

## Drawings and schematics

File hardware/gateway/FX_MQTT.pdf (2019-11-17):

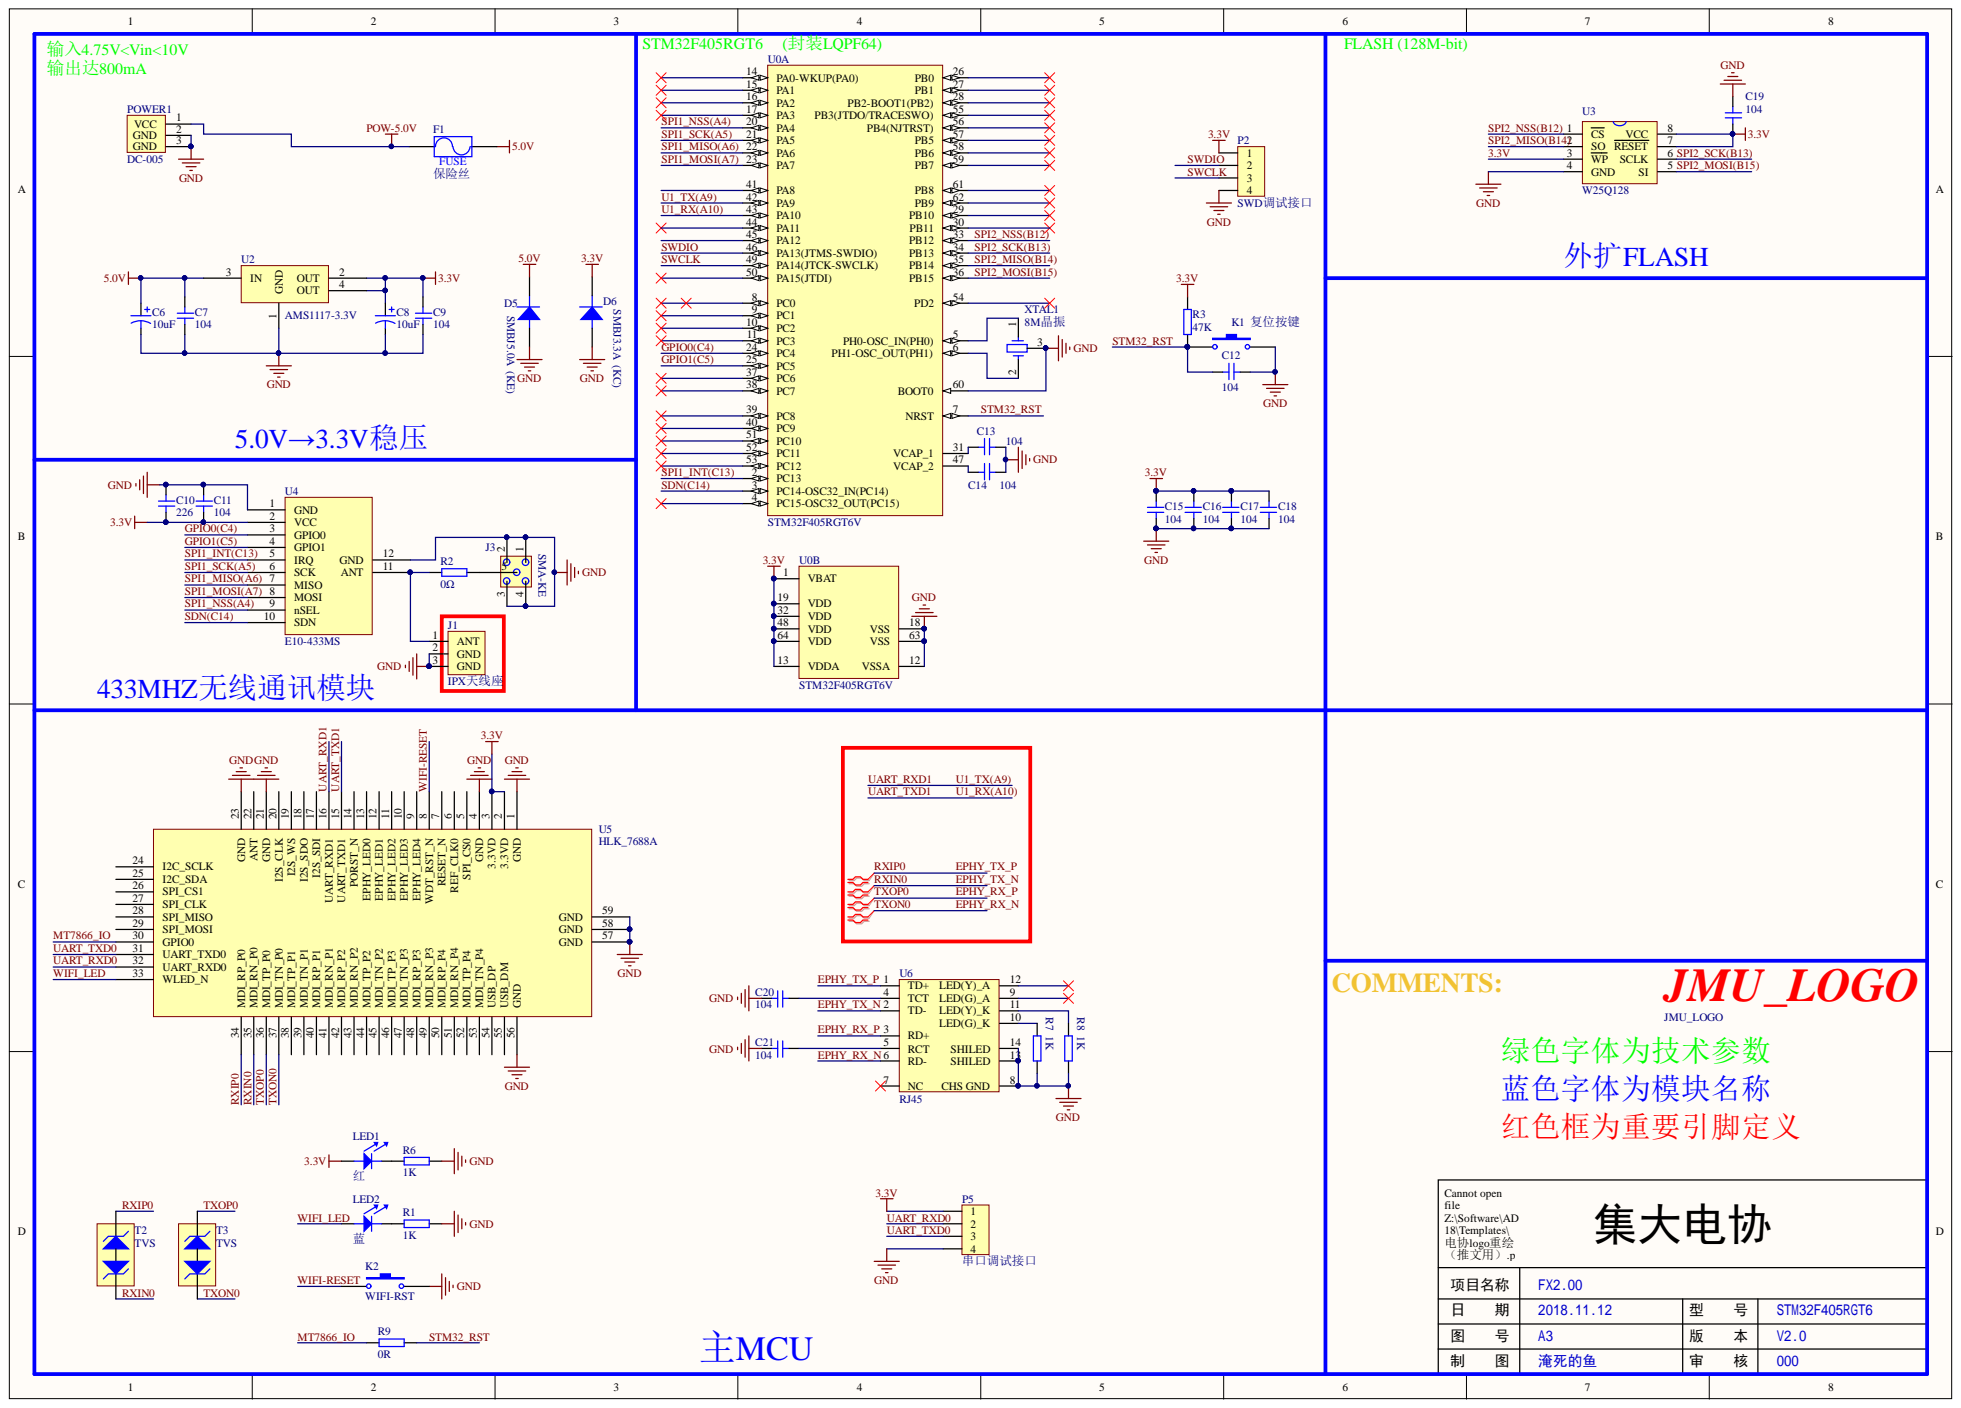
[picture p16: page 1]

C10 C11
226 | 104 | VCC 2

GND 1 3.3VD 2 3.3VD 3 GND 4 SPI_CS0 5 REF_CLK0 6 RESET_N 7 WDT_RST_N 8 EPHY_LED4 9 EPHY_LED3 10 EPHY_LED2 11 EPHY_LED1 12 EPHY_LED0 13 PORST_N 14 UART_TXD1 15 UART_RXD1 16 I2S_SDI 17 I2S_SDO 18 I2S_WS 19 I2S_CLK 20 GND 21 ANT 22 GND 23

项目名称
日 期 | 型 号
图 号 | 版 本

Comment | Description | Designator | Footprint | LibRef | Quantity
JMU_LOGO | LOGO | | JMU_LOGO(1.35cm) | JMU_LOGO | 1
10uF | 极性贴片电容 | C6, C8 | TAJ-A | Pol Cap | 2
104 | 无极贴片电容 | C7, C9, C11, C12, C13, C14, C15, C16, C17, C18, C19, C20, C21 | 0805C | Cap1 | 13
226 | 无极贴片电容 | C10 | 0805C | Cap1 | 1
SMBJ5.0A (KE) | 二极管 | D5 | SMBJ | Diode | 1
SMBJ3.3A (KC) | 二极管 | D6 | SMBJ | Diode | 1
保险丝 | 保险丝 | F1 | 1812 | Fuse | 1
IPX天线座 | | J1 | IPX天线底座 | IPX天线座 | 1
SMA-KE | SMA天线底座 | J3 | SMA-KE | SMA-KE | 1
复位按键 | 轻触开关 | K1 | 贴片按键 | 贴片按键 | 1
WIFI-RST | 轻触开关 | K2 | 卧式侧按键 4.5*4.5*6 | 轻触按键 | 1
红 | 发光二极管 | LED1 | LED-RED直插) | LED | 1
蓝 | 发光二极管 | LED2 | LED-BLUE(直插) | LED | 1
SWD调试接口 | 排针 | P2 | Header 4 | Header 4 | 1
串口调试接口 | 排针 | P5 | Header 4 | Header 4 | 1
DC-005 | 电源插孔 | POWER1 | DC-005 | DC-005 | 1
1K | 电阻 | R1, R6, R7, R8 | 0805R | Res | 4
0Ω | 电阻 | R2 | 0805R | Res | 1
47K | 电阻 | R3 | 0805R | Res | 1
0R | 电阻 | R9 | 0805R | Res | 1
TVS | | T2, T3 | TVS | TVS | 2
STM32F405RGT6V | ARM Cortex-M4 32-bit MCU+FPU, 210 DMIPS, 1024 kB Flash, 192 kB Internal RAM, 51 I/Os, 64-pin LQFP, -40 to 85 degC, Tray | U0 | LQFP-64(GOOD) | STM32F405RGT6V | 1
AMS1117-3.3V | 电源芯片 | U2 | SOT-223 | AMS1117-3.3V/5.0V | 1
W25Q128 | FLASH芯片 | U3 | SOW-8 | W25Q128 | 1
E10-433MS | E10-433MS通信模块 | U4 | E10-433MS | E10-433MS | 1
HLK_7688A | | U5 | MT7688 | HLK_7688A | 1
RJ45 | | U6 | RJ45 | RJ45 | 1
8M晶振 | CSTCC8M00G53-RO 8.000MXTAL1 | | 三脚贴片8M晶振 | XTAL三脚贴片晶振 | 1

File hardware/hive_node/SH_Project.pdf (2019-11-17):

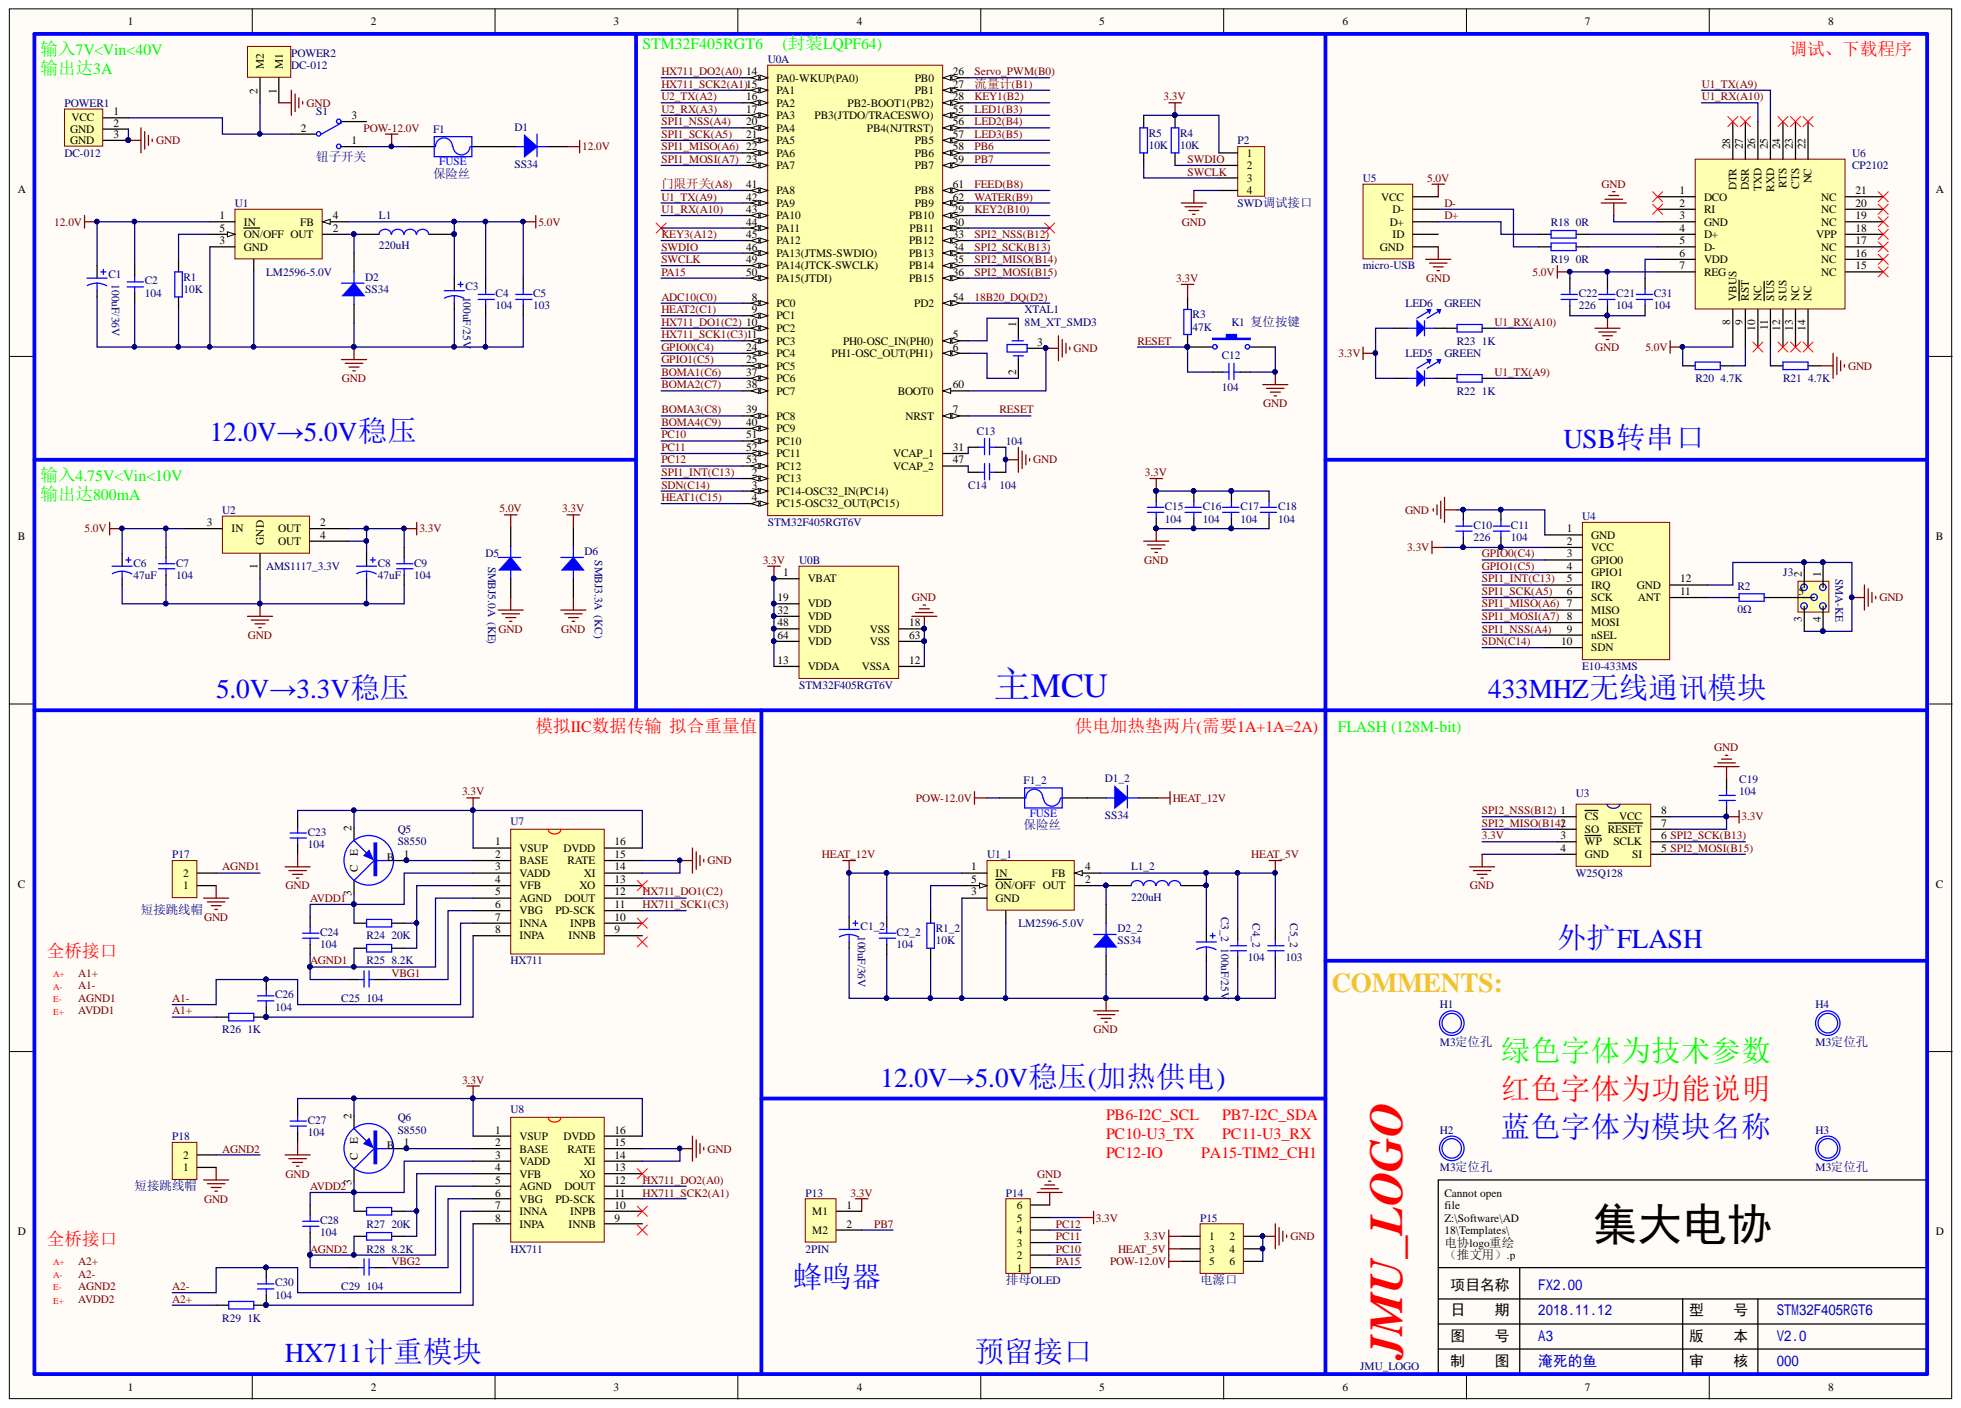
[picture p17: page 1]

C10 C11
226 | 104 | VCC 2

VBG 6 | HX711_SCK1(C3)
INNA 7

AGND1 | R25 | 8.2K

VBG1

图 号 | | 版 本
制 图 | 淹死的鱼 | 审 核

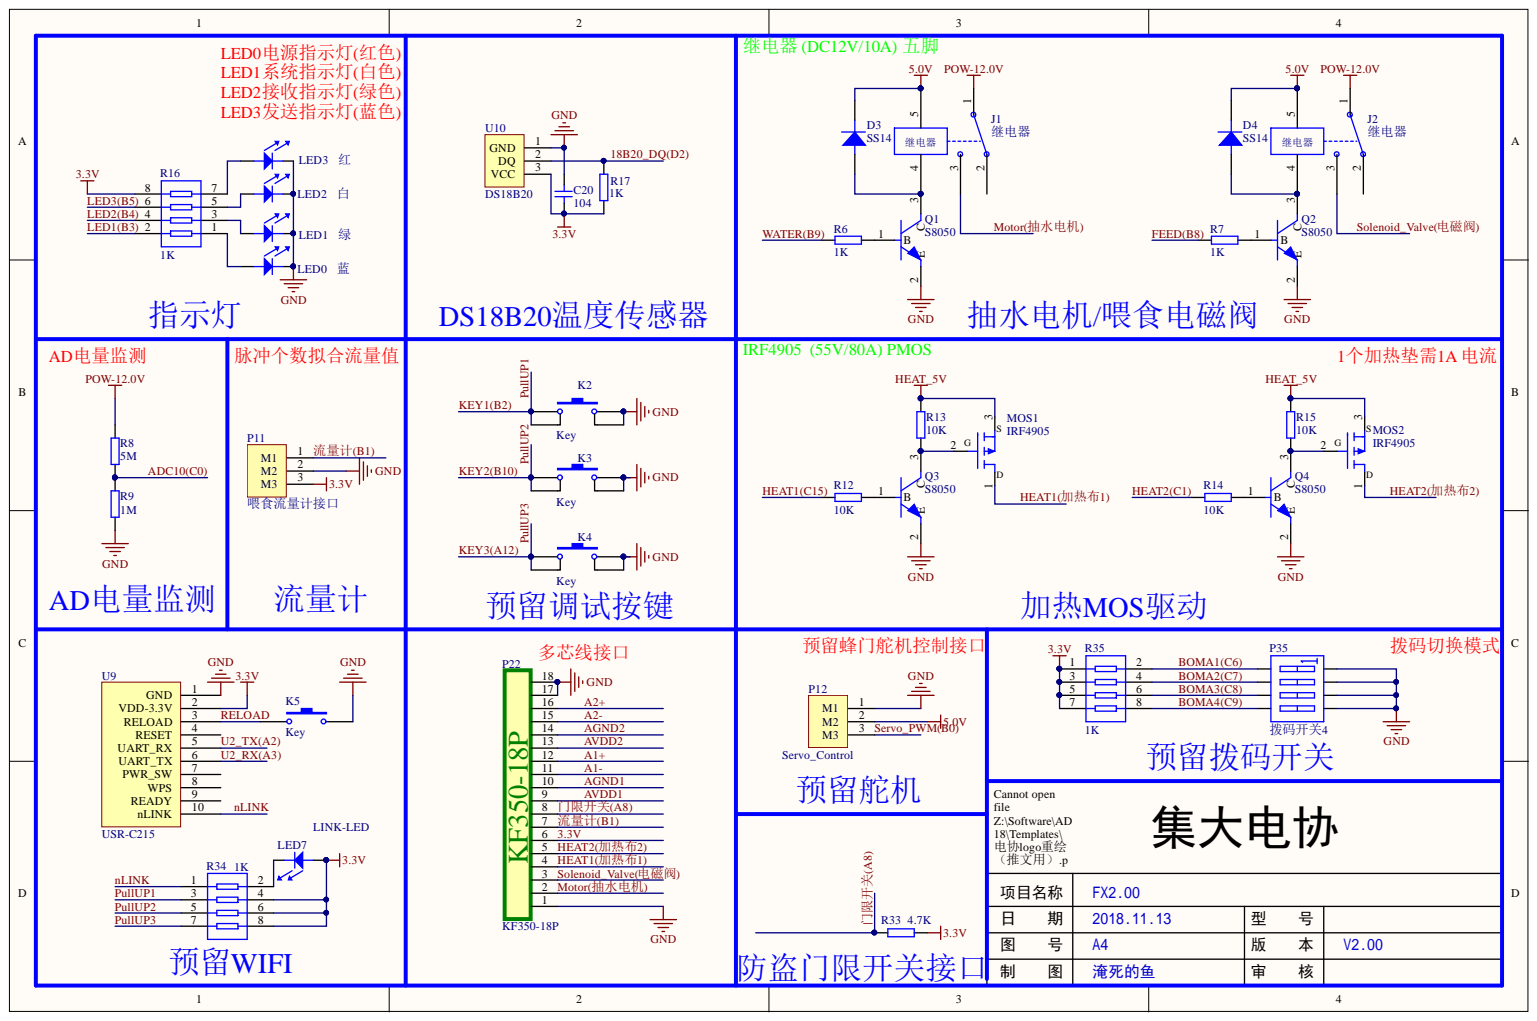
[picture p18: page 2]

Comment | Description | Designator | Footprint | LibRef | Quantity
JMU_LOGO | LOGO | | JMU_LOGO(1.35cm) | JMU_LOGO | 1
100uF/36V | 极性贴片电容 | C1, C1_2 | TAJ-D | Pol Cap | 2
104 | 无极贴片电容 | C2, C2_2, C4, C4_2, C7, C9, C11, C12, C13, C14, C15, C16, C17, C18, C19, C20, C21, C23, C24, C25, C26, C27, C28, C29, C30, C31 | 0805C | Cap1 | 26
100uF/25V | 极性贴片电容 | C3, C3_2 | TAJ-D | Pol Cap | 2
103 | 无极贴片电容 | C5, C5_2 | 0805C | Cap1 | 2
47uF | 极性贴片电容 | C6, C8 | TAJ-A | Pol Cap | 2
226 | 无极贴片电容 | C10, C22 | 0805C | Cap1 | 2
SS34 | 二极管 | D1, D1_2, D2, D2_2 | SMA/DO-214AC | Diode | 4
SS14 | 二极管 | D3, D4 | SMA/DO-214AC | Diode | 2
SMBJ5.0A (KE) | 二极管 | D5 | SMBJ | Diode | 1
SMBJ3.3A (KC) | 二极管 | D6 | SMBJ | Diode | 1
保险丝 | 保险丝 | F1, F1_2 | 1812 | Fuse | 2
M3定位孔 | | H1, H2, H3, H4 | 定位孔 | M3定位孔 | 4
继电器 | 继电器 | J1, J2 | 继电器(小型) | 继电器 | 2
SMA-KE | | J3 | SMA-KE | SMA-KE | 1
复位按键 | 轻触开关 | K1 | 贴片按键 | 贴片按键 | 1
Key | 四脚按键 | K2, K3, K4 | SW_PB4_DIP | 轻触开关 | 3
Key | 轻触开关 | K5 | 贴片按键 | 贴片按键 | 1
220uH | 电感 | L1, L1_2 | 电感 220uh | L | 2
蓝 | 发光二极管 | LED0 | 0805LED | LED | 1
绿 | 发光二极管 | LED1 | 0805LED | LED | 1
白 | 发光二极管 | LED2 | 0805LED | LED | 1
红 | 发光二极管 | LED3 | 0805LED | LED | 1
GREEN | 发光二极管 | LED5, LED6 | 0805LED | LED | 2
LINK-LED | 发光二极管 | LED7 | 0805LED | LED | 1
IRF4905 | PMOS | MOS1, MOS2 | IRF4905(PMOS) | PMOS | 2
SWD调试接口 | 排针 | P2 | Header 4 | Header 4 | 1
喂食流量计接口 | 3PIN | P11 | 接线端子(2.54mm)-3PIN | 接线端子-3PIN | 1
Servo_Control | 3PIN | P12 | 接线端子(2.54mm)-3PIN | 接线端子-3PIN | 1
2PIN | 2PIN | P13 | 接线端子(2.54mm)-2PIN | 接线端子-2PIN | 1
排母OLED | 排针 | P14 | Header 6 | Header 6 | 1
电源口 | 双排排针 | P15 | Header 3X2 | Header 3X2 | 1
短接跳线帽 | 排针 | P17, P18 | Header 2 | Header 2 | 2
KF350-18P | | P22 | KF350-18P | 接线端子KF350-18P | 1
拨码开关4 | 4位拨码开关 | P35 | 拨码开关(4位直插) | 拨码开关4 | 1
DC-012 | 电源插孔 | POWER1 | DC-005 | DC-005 | 1
DC-012 | 2PIN | POWER2 | 接线端子-2P-5.0MM | 接线端子-2PIN | 1
S8050 | NPN三极管 | Q1, Q2, Q3, Q4 | SOT-23 | NPN | 4
S8550 | PNP | Q5, Q6 | SOT-23 | S8550 | 2
10K | 电阻 | R1, R1_2, R4, R5, R12, R13, R14, R15 | 0805R | Res | 8
0Ω | 电阻 | R2 | 0805R | Res | 1
47K | 电阻 | R3 | 0805R | Res | 1
1K | 电阻 | R6, R7, R17, R22, R23, R26, R29 | 0805R | Res | 7
5M | 电阻 | R8 | 0805R | Res | 1
1M | 电阻 | R9 | 0805R | Res | 1
1K | 排阻 | R16, R34, R35 | 排阻(4位贴片) | Res-4 | 3
0R | 电阻 | R18, R19 | 0805R | Res | 2
4.7K | 电阻 | R20, R21, R33 | 0805R | Res | 3
20K | 电阻 | R24, R27 | 0805R | Res | 2
8.2K | 电阻 | R25, R28 | 0805R | Res | 2
钮子开关 | 大功率开关 | S1 | 钮子开关(大) | 钮子开关 | 1
STM32F405RGT6V | ARM Cortex-M4 32-bit MCU+FPU, 210 DMIPS, 1024 kB Flash, 192 kB Internal RAM, 51 I/Os, 64-pin LQFP, -40 to 85 degC, Tray | U0 | LQFP-64(GOOD) | STM32F405RGT6V | 1
LM2596-5.0V | 5V电源芯片 | U1, U1_1 | TO-263-5 - duplicate | LM2596 | 2
AMS1117_3.3V | 电源芯片 | U2 | SOT-223 | AMS1117-3.3V/5.0V | 1
W25Q128 | | U3 | SOW-8 | W25Q128 | 1
E10-433MS | | U4 | E10-433MS | E10-433MS | 1
micro-USB | USB接口 | U5 | Micro-USB (兼容牛角以 及固定脚) | micro-USB | 1
CP2102 | USB转串口芯片 | U6 | QFN-28 | CP2102 | 1
HX711 | A/D转换器芯片 | U7, U8 | SOP-16 | HX711 | 2
USR-C215 | WIFI模块 | U9 | USR-C215 | USR-C215 | 1
DS18B20 | 数字温度传感器 | U10 | TO-92 | DS18B20 | 1
8M_XT_SMD3 | | XTAL1 | 三脚贴片8M晶振 | XTAL三脚贴片晶振 | 1

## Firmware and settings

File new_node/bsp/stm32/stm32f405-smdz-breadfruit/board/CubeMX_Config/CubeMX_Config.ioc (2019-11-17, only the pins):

Mcu.UserName=STM32F405RGTx
PA10.Signal=USART1_RX
PA2.Signal=USART2_TX
PA3.Signal=USART2_RX
PA5.Signal=SPI1_SCK
PA6.Signal=SPI1_MISO
PA7.Signal=SPI1_MOSI
PA9.Signal=USART1_TX
PB13.Signal=SPI2_SCK
PB14.Signal=SPI2_MISO
PB15.Signal=SPI2_MOSI
PC14-OSC32_IN.Signal=RCC_OSC32_IN
PC15-OSC32_OUT.Signal=RCC_OSC32_OUT
PH0-OSC_IN.Signal=RCC_OSC_IN
PH1-OSC_OUT.Signal=RCC_OSC_OUT

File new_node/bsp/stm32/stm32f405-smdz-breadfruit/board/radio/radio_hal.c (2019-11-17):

/*
 * This file is part of the ART-6LoWPAN Radio Library.
 *
 * Copyright (c) 2017, Armink, <armink.ztl@gmail.com>
 * Copyright (c) 2017, xidongxu, <xi_dongxu@126.com>
 *
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
 * Function: Radio HAL(Hardware Abstraction Layer) layer driver. It provide radio API to `radio_trans_soft.c` or `radio_driver.c` .
 * Created on: 2017-09-15
 */

#include "radio_cfg.h"
#include <board.h>
#include "drv_spi.h"


//#define DRV_DEBUG
#define LOG_TAG             "radio_hal"
#include <drv_log.h>

#include "radio_hal.h"
#include <stdbool.h>
#include <rtthread.h>
#include <drivers/spi.h>

#define RADIO_SPI_BUS_NAME             "spi1"
#define RADIO_SPI_DEV_NAME             "spi10"

#define RADIO_DEFAULT_SPI_CFG                   \
{                                               \
    .mode = RT_SPI_MODE_0 | RT_SPI_MSB,         \
    .data_width = 8,                            \
    .max_hz = 1 * 1000 * 1000,                  \
}

#define RSSI_UNKNOWN                   -128
/* 状态切换超时，单位：毫秒 */
#define STATE_SWITCH_TIMEOUT           10

U8 Radio_Configuration_Data_Array[] = RADIO_CONFIGURATION_DATA_ARRAY;
tRadioConfiguration RadioConfiguration = RADIO_CONFIGURATION_DATA;
tRadioConfiguration *pRadioConfiguration = &RadioConfiguration;

/* SPI 设备对象 */
static struct rt_spi_device *radio_spi_device;
/* 命令回复的结果锁 */
static rt_mutex_t cmd_reply_locker = NULL;

static void radio_power_up(void) {
    /* Hardware reset the chip */
    si446x_reset();

    /* Wait until reset timeout or Reset IT signal */
    rt_thread_delay(rt_tick_from_millisecond(5));
}

static bool wait_state_switch(uint8_t state) {
    bool switch_ok = false;
    rt_tick_t last_time = rt_tick_get();
    const rt_tick_t timeout = STATE_SWITCH_TIMEOUT * RT_TICK_PER_SECOND / 1000;
    uint8_t cur_state;

    while (rt_tick_get() - last_time < timeout) {
        radio_cmd_reply_lock();
        si446x_request_device_state();
        cur_state = Si446xCmd.REQUEST_DEVICE_STATE.CURR_STATE;
        radio_cmd_reply_unlock();
        if (cur_state == state) {
            switch_ok = true;
            break;
        }
        rt_thread_delay(rt_tick_from_millisecond(1));
    }

    if (rt_tick_get() - last_time >= timeout) {
        LOG_E("radio main state(%d) switch failed!", state);
    }

    return switch_ok;
}

void radio_start_rx(uint8_t channel, uint8_t packet_lenght) {
    /* Set filed2 to max length */
    si446x_set_property(SI446X_PROP_GRP_ID_PKT, 2, SI446X_PROP_PKT_FIELD_2_LENGTH_FIELD_2_LENGTH_12_8_INDEX, 0x04, 0x00);

    /* Reset the RX & TX FIFO */
    si446x_fifo_info(SI446X_CMD_FIFO_INFO_ARG_FIFO_RX_BIT | SI446X_CMD_FIFO_INFO_ARG_FIFO_TX_BIT);

    /* Switch to SPI_ACTIVE state */
    si446x_change_state(SI446X_CMD_CHANGE_STATE_ARG_NEXT_STATE1_NEW_STATE_ENUM_SPI_ACTIVE);

    /* Wait SPI_ACTIVE state switch OK */
    wait_state_switch(SI446X_CMD_REQUEST_DEVICE_STATE_REP_CURR_STATE_MAIN_STATE_ENUM_SPI_ACTIVE);

    /* Switch to RX_TUNE state */
    si446x_change_state(SI446X_CMD_CHANGE_STATE_ARG_NEXT_STATE1_NEW_STATE_ENUM_RX_TUNE);

    /* Wait RX_TUNE state switch OK */
    wait_state_switch(SI446X_CMD_REQUEST_DEVICE_STATE_REP_CURR_STATE_MAIN_STATE_ENUM_RX_TUNE);

    /* Start Receiving packet, channel, START immediately, Packet length used or not according to packetLength */
    si446x_start_rx(channel, 0u, 0u, SI446X_CMD_START_RX_ARG_NEXT_STATE1_RXTIMEOUT_STATE_ENUM_RX,
                    SI446X_CMD_START_RX_ARG_NEXT_STATE2_RXVALID_STATE_ENUM_RX,
                    SI446X_CMD_START_RX_ARG_NEXT_STATE3_RXINVALID_STATE_ENUM_RX );
}

/*!
 *  Set Radio to TX mode, variable packet length.
 *  Use it when multiple fields are in use (START_TX is called with 0 length).
 *
 *  @param channel Freq. Channel, Packet to be sent length of of the packet sent to TXFIFO
 *
 *  @note
 *
 */
void radio_start_tx_variable_packet_multifield(uint8_t channel, uint8_t *radio_packet, uint8_t length) {
    /* Reset the TX & RX FIFO */
    si446x_fifo_info(SI446X_CMD_FIFO_INFO_ARG_FIFO_TX_BIT | SI446X_CMD_FIFO_INFO_ARG_FIFO_RX_BIT);

    /* Switch to SPI_ACTIVE state */
    si446x_change_state(SI446X_CMD_CHANGE_STATE_ARG_NEXT_STATE1_NEW_STATE_ENUM_SPI_ACTIVE);

    /* Wait SPI_ACTIVE state switch OK */
    wait_state_switch(SI446X_CMD_REQUEST_DEVICE_STATE_REP_CURR_STATE_MAIN_STATE_ENUM_SPI_ACTIVE);

    /* Fill the TX FIFO with datas */
    si446x_write_tx_fifo(length, radio_packet);

    /* Switch to SPI_ACTIVE state */
    si446x_change_state(SI446X_CMD_CHANGE_STATE_ARG_NEXT_STATE1_NEW_STATE_ENUM_SPI_ACTIVE);

    /* Wait SPI_ACTIVE state switch OK */
    wait_state_switch(SI446X_CMD_REQUEST_DEVICE_STATE_REP_CURR_STATE_MAIN_STATE_ENUM_SPI_ACTIVE);

    /* Switch to TX_TUNE state */
    si446x_change_state(SI446X_CMD_CHANGE_STATE_ARG_NEXT_STATE1_NEW_STATE_ENUM_TX_TUNE);

    /* Wait TX_TUNE state switch OK */
    wait_state_switch(SI446X_CMD_REQUEST_DEVICE_STATE_REP_CURR_STATE_MAIN_STATE_ENUM_TX_TUNE);

    /* Start sending packet, channel 0, START immediately, stay TX status when send finish */
    si446x_start_tx(channel, 0x00, 0);
}

uint8_t radio_hal_init(void) {
    uint8_t result = 0;
    struct rt_spi_configuration cfg = RADIO_DEFAULT_SPI_CFG;

    rt_hw_spi_device_attach(RADIO_SPI_BUS_NAME, RADIO_SPI_DEV_NAME, GPIOA, GPIO_PIN_4);
    
    radio_spi_device = (struct rt_spi_device *) rt_device_find(RADIO_SPI_DEV_NAME);
    if (radio_spi_device == RT_NULL || radio_spi_device->parent.type != RT_Device_Class_SPIDevice) {
        LOG_E("ERROR: SPI device %s not found!\n", RADIO_SPI_DEV_NAME);
        RT_ASSERT(0);
    }
    rt_spi_configure(radio_spi_device, &cfg);

    if (!cmd_reply_locker) {
        cmd_reply_locker = rt_mutex_create("cmd_reply", RT_IPC_FLAG_FIFO);
        RT_ASSERT(cmd_reply_locker);
    }

    /* Power Up the radio chip */
    radio_power_up();

    si446x_part_info();
    LOG_D("si446x chip revision: %x, part id: %x, rom id: %d", Si446xCmd.PART_INFO.CHIPREV, Si446xCmd.PART_INFO.PART, Si446xCmd.PART_INFO.ROMID);

    if (Si446xCmd.PART_INFO.PART != 0x4463) {
        LOG_E("Radio chip part info(%d) error. This radio driver only support SI4463", Si446xCmd.PART_INFO.PART);
        return SI446X_INIT_ERROR;
    }

#if SI446X_USING_REV_B1
    if (Si446xCmd.PART_INFO.CHIPREV != 0x11) {
        LOG_E("Radio chip revision(%d) don't match. This radio driver only support SI4463 Rev.B1(0x11)", Si446xCmd.PART_INFO.CHIPREV);
        return SI446X_INIT_ERROR;
    }
#else
    if (Si446xCmd.PART_INFO.CHIPREV != 0x22) {
        log_e("Radio chip revision(%d) don't match. This radio driver only support SI4463 Rev.C2(0x22)", Si446xCmd.PART_INFO.CHIPREV);
        return SI446X_INIT_ERROR;
    }
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

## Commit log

2019-07-05 【提交】提交V1.00版本
    [FX_MCU.SchDoc, FX_Peripherals.SchDoc, SH_Project.PrjPcb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]
2019-07-06 【更新】完善说明文档
2019-07-06 【更新】更新说明文档
2019-07-15 【提交】提交设计文档 & 参考文献
    [3.1.1半桥式传感器.dwg, 3.1.2蜂箱三视图.dwg, 3.1.3称重方铝框.dwg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]
2019-07-15 提交Gateway 电路设计
    [FX_MQTT.PrjPcb, FX_MQTT.SchDoc]
2019-07-16 【提交】提交节点样机照片
2019-07-16 “【更新】更新说明文档
2019-08-27 【提交】提交使用与安装说明
2019-10-14 【提交】提交备份网关程序
2019-10-18 【添加】添加蜂箱PCB板测试程序
2019-10-18 【提交】提交蜂箱测试方案与bin程序
2019-10-18 【提交】提交蜂箱节点与边界路由bin程序
2019-10-18 【提交】提交相关设计文档
2019-10-18 【更新】
2019-10-22 【提交】提交mt7688配置文件及说明
2019-10-22 【更新】完善使用文档
2019-10-22 【更新】提交相关配置与工具
2019-10-23 【更新】完善目录结构
2019-10-23 【更新】更新main.js
2019-10-26 【提交】提交改进版，扩大上传时间
    [kconfig-language.txt, kconfig.txt]
2019-10-26 【更新】完善发送掉线问题
2019-10-27 【提交】
    [kconfig-language.txt, kconfig.txt]
2019-10-28 【提交】提交边界路由程序
    [kconfig-language.txt, kconfig.txt]
2019-10-31 【更新】完善配置信息
2019-10-31 【更新】完善配置流程
2019-10-31 【添加】添加后续测试版本
    [kconfig-language.txt, kconfig.txt]
2019-11-17 【更新】备份提交
    [BOM_FX_PCB3.0.xls, FX_MQTT.PrjPcb]
2019-11-17 【更新】提交节点程序重构版本
2019-11-17 【删除】
2019-11-17 【提交】提交节点重构版本
    [kconfig-language.txt, kconfig.txt]
2019-11-18 【删除】删除其他bsp
2019-11-18 【更新】添加easyflash、elogger驱动
2019-11-20 【更新】移植外设功能驱动
